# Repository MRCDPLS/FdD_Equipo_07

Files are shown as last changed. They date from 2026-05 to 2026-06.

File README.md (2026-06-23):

# Equipo 07 - Fundamentos de Diseño
### Carrera de Ingeniería Ambiental / Informática / Industrial  
**Universidad Peruana Cayetano Heredia**

---

## 🌍 Descripción del Equipo  
<p align="justify">
Somos el <strong>Equipo 07</strong> del curso <strong>Fundamentos de Diseño 2026</strong>, conformado por estudiantes de la carrera de Ingeniería Ambiental / Informática / Industrial.  
Nuestro objetivo es diseñar e implementar una solución tecnológica basada en metodologías de diseño que permita la detección y clasificación de microplásticos en ecosistemas marino, con el proposito de que las playas tengan el antiguo brillo de antes, y que los animales marinos esten bien. 
</p>

---

## 📌 Descripción del Proyecto
<p align="justify">
El Equipo 07 desarrolla un dispositivo portátil de detección automatizada de microplásticos llamado Yaku-Ñawi, enfocado en la identificación de partículas polímeras como PP (polipropileno) y EPS (poliestireno expandido) en playas y humedales de Lima y Callao.

La solución integra técnicas de procesamiento digital de imágenes, visión computacional e inteligencia artificial, empleando hardware embebido basado en Seeed Studio XIAO ESP32-S3 Sense, una placa con cámara integrada que permite la captura de imágenes en campo y su procesamiento dentro de una arquitectura portátil. Para mejorar la observación de las muestras, el prototipo incorpora iluminación ultravioleta (UV), aprovechando las propiedades ópticas de ciertos polímeros para facilitar su diferenciación visual y fortalecer el análisis computacional. De manera complementaria, el sistema puede integrar sensores de apoyo para caracterizar el entorno de la muestra, contribuyendo a una evaluación más completa del estado del agua.

El objetivo principal de Yaku-Ñawi es lograr la identificación temprana de microplásticos mediante un sistema autónomo capaz de procesar datos sin depender de infraestructura externa ni análisis de laboratorio especializados. Esto permite implementar un monitoreo ambiental continuo, oportuno y adaptado a condiciones reales, reduciendo tiempos, costos operativos y barreras tecnológicas existentes en los métodos tradicionales.

A través de esta propuesta, Yaku-Ñawi busca contribuir al estudio y monitoreo de la contaminación por microplásticos en ecosistemas marino-costeros, alineándose con los Objetivos de Desarrollo Sostenible, especialmente el ODS 6: Agua limpia y saneamiento y el ODS 14: Vida submarina.
</p>

---

## 🔍 Introducción
<p align="justify">
La creciente contaminación por microplásticos se ha convertido en uno de los desafíos ambientales más relevantes a nivel global, como resultado del uso masivo de plásticos y su persistencia en el ambiente. Estas partículas, menores a 5 mm, se encuentran ampliamente distribuidas en ecosistemas acuáticos y terrestres, lo que facilita su dispersión, acumulación y permanencia a largo plazo (1).
</p>

<p align="justify">
En el Perú, la deficiente gestión de residuos sólidos y el inadecuado manejo de desechos costeros han intensificado la presencia de microplásticos en ambientes marinos. Esta problemática no solo impacta a los ecosistemas, sino que también representa un riesgo creciente para la salud humana (2), debido a su ingreso al organismo a través de alimentos contaminados y la inhalación de partículas, generando efectos adversos como inflamación y alteraciones celulares (3).
</p>

<p align="justify">
Frente a este escenario, el presente proyecto propone determinar la presencia de microplásticos en humedales y playas de Lima y Callao mediante una metodología de análisis orientada a la identificación de polímeros sintéticos de uso común, como el polipropileno (PP) y el poliestireno expandido (EPS) (4). De esta manera, se busca generar evidencia científica que permita dimensionar la magnitud de esta contaminación y sentar bases para el desarrollo de estrategias de monitoreo y mitigación en ecosistemas acuáticos (5).
</p>

---

## ⚠️ Problemática 
### Problemática a Nivel Mundial
<p align="justify">
La crisis de los microplásticos está impulsada principalmente por polímeros de alta producción como el polipropileno (PP) y el EPS (poliestireno expandido). El polipropileno representa aproximadamente el 21 % de la producción total de plásticos no fibrosos, siendo ampliamente utilizado en envases, empaques y materiales industriales, lo que incrementa su liberación al ambiente tras su disposición final inadecuada (6). Por su parte, el PET constituye un material fundamental en la industria de bebidas y textiles sintéticos, donde domina la producción de fibras artificiales utilizadas globalmente (6,7).
</p>

#### Impactos y comportamiento:
* Persistencia diferencial:
  <p align="justify">
  El PET tiende a degradarse más lentamente que otros polímeros como el polietileno, lo que prolonga su presencia en el entorno (5,6).
  </p>

* Comportamiento en el agua: 
  <p align="justify">
  El EPS posee una densidad aproximada de 0.94 g/mL, característica que le permite flotar y dispersarse ampliamente en la superficie marina. En contraste, el PET presenta mayor densidad, favoreciendo su sedimentación y acumulación en fondos acuáticos (7,8).
  </p>

* Presencia en humanos: 
  <p align="justify">
  Diversas investigaciones han evidenciado la presencia de microplásticos en muestras biológicas humanas. Partículas de PP han sido detectadas en placenta y heces humanas, mientras que el PET constituye uno de los polímeros más frecuentemente identificados en sangre y muestras fecales, evidenciando su ingreso a la cadena alimentaria y posible impacto en la salud humana (7,8).
  </p>

### Problemática a Nivel Local
<p align="justify">
En Lima y el Callao, el ESP y el PET representan contaminantes prioritarios debido al elevado consumo de productos descartables y a deficiencias en la gestión integral de residuos sólidos. Se estima que cerca del 40 % de los residuos generados en el país no recibe una disposición adecuada, terminando en ríos, playas y ecosistemas marinos donde se fragmentan progresivamente en microplásticos (11).
</p>

#### Hallazgos específicos en Lima:
* Contaminación en playas: 
  <p align="justify">
  Estudios realizados en playas arenosas del litoral peruano han confirmado la presencia de microplásticos mediante análisis espectroscópicos, identificándose partículas de polipropileno asociadas a residuos marinos transportados por corrientes costeras y acumulación de basura oceánica (12).
  </p>

* Riesgo en recursos pesqueros: 
  <p align="justify">
  Investigaciones recientes en especies comerciales capturadas en terminales pesqueros de Lima y Callao reportaron la presencia de microplásticos en el 100 % de algunas especies analizadas, evidenciando la transferencia de estas partículas dentro de la red trófica marina y su potencial riesgo para el consumo humano (6). El uso de PP en artes de pesca y la degradación de botellas de PET constituyen fuentes directas de contaminación en el ecosistema marino local (7,11,13).
  </p>
--- 

## 🌊 Yaku-Ñawi – Detector de microplásticos
### 💡 Presentación de la solución 
<p align="justify">
El presente proyecto propone el desarrollo de un <strong>dispositivo inteligente portátil diseñado para detectar y clasificar microplásticos como el polipropileno (PP) y el polietileno tereftalato (PET)</strong> en cuerpos de agua, como humedales y playas de Lima y Callao, donde la contaminación por residuos plásticos representa una amenaza creciente para los ecosistemas y la salud humana.
</p>

<p align="justify">
La solución integra sensores ópticos, captura y procesamiento de imágenes y análisis automatizado usando modelos de IA, de muestras de agua y sedimentos. Este sistema incorpora algoritmos de machine learning y la inteligencia artificial actúa como núcleo del sistema, optimizando continuamente la detección a medida que procesa nuevas muestras. Todo ello se traduce en una herramienta portable y escalable, permitiendo realizar monitoreo ambiental directamente en campo sin necesidad de laboratorio especializado.
</p>

<p align="justify">
Bajo el enfoque de ingeniería, Yaku-Ñawi integra principalmente <strong>procesamiento de imágenes, machine learning, electrónica con sensores y microcontroladores</strong>. Esto permite transformar un proceso tradicionalmente manual en un sistema automatizado, escalable y replicable.
</p>

<p align="justify">
El valor innovador radica que <strong>automatiza la detección de microplásticos y macroplásticos, reduce costos frente a un análisis de laboratorio y que puede ser adaptada en distintas zonas del país</strong>.
</p>

---

## 🎯 Objetivos de Desarrollo Sostenible (ODS)
<p align="justify">
Nuestro proyecto se relaciona con los siguientes <strong>Objetivos de Desarrollo Sostenible (ODS)</strong>: 
</p>

- 🐠 **ODS 14 : VIDA SUBMARINA**  
  <p align="justify">
  La contaminación por plásticos y microplásticos representa una amenaza importante para los ecosistemas marinos. Estas partículas pueden permanecer durante muchos años en el agua y afectar a la fauna marina. Se estima que entre 19 y 23 millones de toneladas de residuos plásticos ingresaron a los sistemas acuáticos en el 2016, y se prevé que esta cifra podría alcanzar hasta 53 millones de toneladas anuales para 2030. Esta problemática afecta directamente a la vida submarina, ya que los organismos marinos pueden ingerir microplásticos, lo que altera los ecosistemas y la biodiversidad.
  </p>

- 💧 **ODS 6: AGUA LIMPIA Y SANEAMIENTO**  
  <p align="justify">
  Los microplásticos también afectan la calidad del agua potable y los sistemas de tratamiento de aguas residuales. Estas partículas pueden ingresar a las plantas de tratamiento a través del lavado de ropa sintética y productos que contienen plástico. Aunque los sistemas de tratamiento pueden eliminar una parte de estos contaminantes, la gran cantidad de microplásticos sigue representando un desafío para garantizar agua segura y saneamiento adecuado.
  </p>

---

## 📖 Referencias bibliográficas 
1.  Microplastics and human health. Wasser 3.0 [Internet]. 27 de julio de 2024 [citado 13 de abril de 2026].  
Disponible en: https://wasserdreinull.de/en/blog/microplastics-and-human-health/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 
2.  Micro- and mesoplastic pollution along the coast of Peru | Request PDF. ResearchGate. 23 de enero de 2026. 
Disponible en: doi:10.1007/s11356-023-27707-6.
3. Emenike EC, Okorie CJ, Ojeyemi T, Egbemhenghe A, Iwuozor KO, Saliu OD, et al. From oceans to dinner plates: The impact of microplastics on human health. Heliyon. 1 de octubre de 2023;9(10):e20440.  
Disponible en: doi:10.1016/j.heliyon.2023.e20440.
4. Luque Fernández CR. Contaminación por microplásticos en playas arenosas de Islay, departamento de Arequipa [Internet]. 17 de enero de 2020 [citado 1 de abril de 2026].  
Disponible en: https://repositorio.ucsm.edu.pe/handle/20.500.12920/9869. 
5. Gimiliani GT. Caracterização de microplásticos em amostras marinhas e estuarinas [tesis doctoral]. São Paulo: Instituto de Pesquisas Energéticas e Nucleares, Universidade de São Paulo; 2021.   
Disponible en: https://www.teses.usp.br/teses/disponiveis/85/85134/tde-22102021-104234/pt-br.php.
6. Geyer R, Jambeck JR, Law KL. Production, use, and fate of all plastics ever made. Sci Adv. 2017;3(7):e1700782. 
Disponible en: doi:10.1126/sciadv.1700782
7. Osman AI, Hosny M, Eltaweil AS, Omar S, Elgarahy AM, Farghali M, et al. Microplastic sources, formation, toxicity and remediation: a review. Environ Chem Lett. 2023;21:2129-2169.   
Disponible en: doi:10.1007/s10311-023-01593-3.
8. Rios Mendoza LM, Balcer M. Microplastics in freshwater environments: A review of quantification assessment. Trends Analyt Chem. 2019;113:402-408.
9. Hu B, Dai Y, Zhou H, Sun Y, Yu H, Dai Y, et al. Using artificial intelligence to rapidly identify microplastics pollution and predict microplastics environmental behaviors. J Hazard Mater. 2024;474:134865.
10. Tian X, Beén F, Bäuerlein PS. Quantum cascade laser imaging (LDIR) and machine learning for the identification of environmentally exposed microplastics and polymers. Environ Res. 2022;212:113569. 
Disponible en: doi:10.1016/j.envres.2022.113569
11. Ministerio del Ambiente (MINAM). Plásticos. Lima: Red Peruana Ciclo de Vida y Ecología Industrial (PELCAN); 2026. 
Disponible en: https://red.pucp.edu.pe/ciclodevida/
12. Purca S, Henostroza A. Presencia de microplásticos en cuatro playas arenosas de Perú. Rev Peru Biol. 2017;24(1):101-106.  
Disponible en: doi:10.15381/rpb.v24i1.12724
13. Flores K, Seminario M, Canchari F, Alvariño L, Miñaya D, Castañeda L, et al. Contaminación por microplásticos en tres peces marinos del Perú. Rev Inv Vet Perú. 2026;37(1):e32888.  
Disponible en: doi:10.15381/rivep.v37i1.32888

---

## 📸 Fotografía del Equipo  
<p align="center">
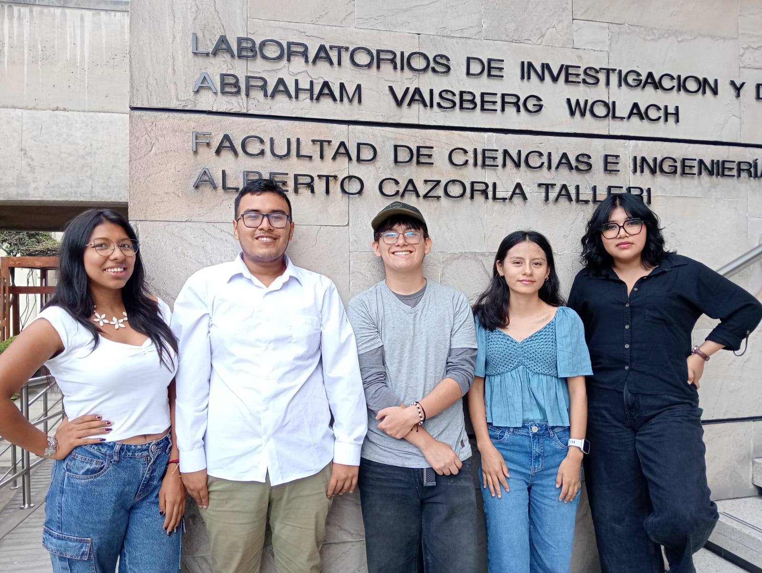
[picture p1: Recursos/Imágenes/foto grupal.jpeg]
imagen_alumnos_IA

  <em>Figura 1. Fotografía del Equipo 07</em>
</p>

---

## 👥 Integrantes del Equipo  

| Foto | 👤 Nombre | 🎓 Rol | 💡 Intereses |
| :---: | :---: | :---: | :---: |
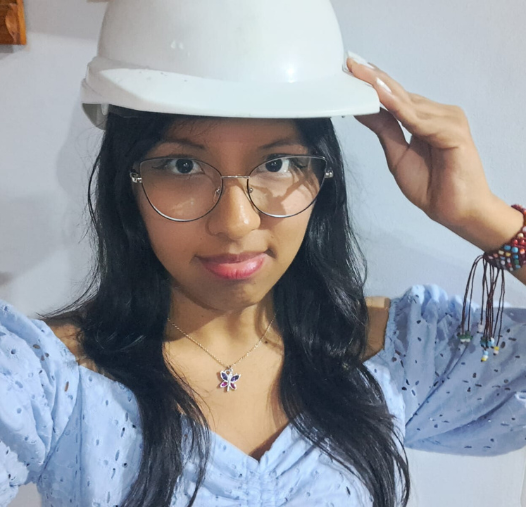
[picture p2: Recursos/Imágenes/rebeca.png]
|  | **Rebeca Cerdan** | ❤️ Líder del equipo | 🎧 Melómana, 🤖 tecnología, 🎮 fan de Genshin Impact |
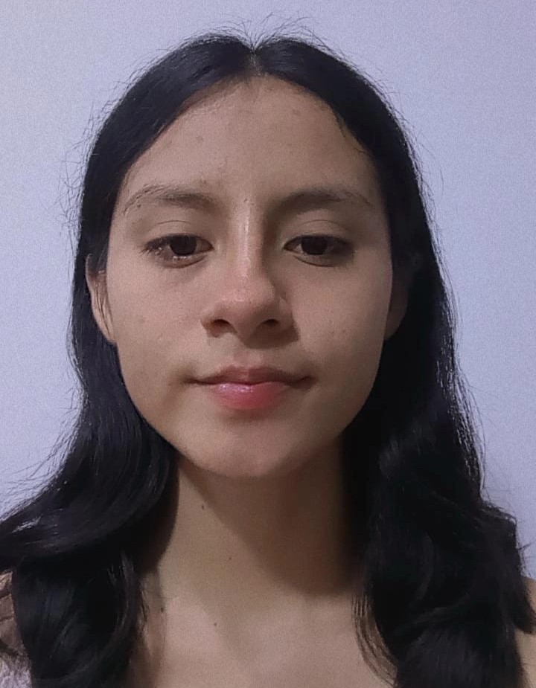
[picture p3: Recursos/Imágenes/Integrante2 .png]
|  | **Siclali Fernandez** | 🚀 Product Manager | 🧠 Entender al usuario, 💡 soluciones innovadoras, 📢 comunicar el valor del proyecto  |
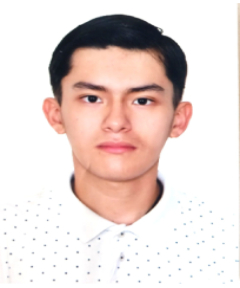
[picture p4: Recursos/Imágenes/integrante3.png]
|  | **Marcelo Alarcon** | 🎨 Diseñador | 🧩 prototipos, ✨ creatividad, 🧱 modelado 3D, 🔍 investigador UX |
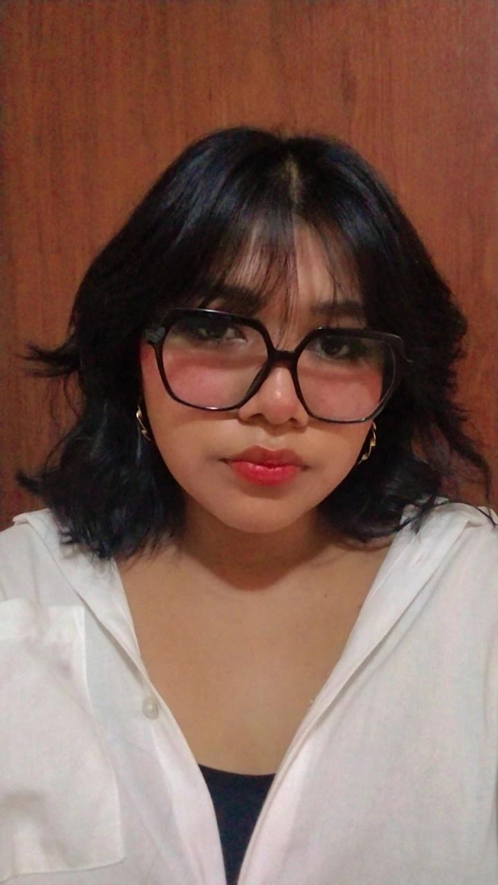
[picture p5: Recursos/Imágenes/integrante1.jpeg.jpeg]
|  | **Mariluz Quispe** | 🌱 Encargada de Apoyo Ambiental | ♻️ sostenibilidad, 🌍 cuidado ambiental |
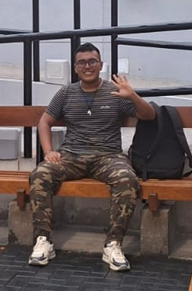
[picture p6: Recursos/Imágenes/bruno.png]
|  | **Bruno Evangelista** | 💻 Programador y Modelador 3D | 📊 Programar una solución ecosostenible |

---

## 📌 Resumen final  
<p align="justify">
El presente README describe la conformación del equipo, la problemática abordada y la propuesta de solución desarrollada en el curso Fundamentos de Diseño. El proyecto consiste en el desarrollo de un sistema inteligente para la detección y análisis de microplásticos en playas y humedales de Lima, mediante la recolección de muestras y su procesamiento con visión artificial e inteligencia artificial. Esta solución permite automatizar un proceso tradicionalmente manual, generando datos confiables para el monitoreo ambiental y contribuyendo a la protección de los ecosistemas acuáticos.
</p>

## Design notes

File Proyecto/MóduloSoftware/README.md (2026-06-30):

# Yaku-Ñawi · Guía de integración YOLOv8 + ESP32-S3

## Estructura del proyecto

```
yaku-nawi/
├── app.py                  ← Servidor Flask + YOLOv8 (ejecutar en la PC)
├── best.pt                 ← Tu modelo YOLOv8 entrenado (colocar aquí)
├── esp32_yaku_nawi.ino     ← Código Arduino para el ESP32-S3 XIAO Sense
├── templates/
│   └── index.html          ← Dashboard web (sirve Flask automáticamente)
├── static/
│   └── ultima.jpg          ← Último frame recibido del ESP32 (auto-generado)
└── README.md
```

---

## 1. Instalar dependencias en la PC

```bash
pip install flask ultralytics opencv-python numpy
```

---

## 2. Colocar el modelo YOLOv8

Copia tu archivo `best.pt` (entrenado con PET y EPS) a la raíz del proyecto.  
Si no tienes `best.pt` aún, Flask usará `yolov8n.pt` como fallback (sin clases de microplásticos).

---

## 3. Correr el servidor

```bash
cd yaku-nawi/
python app.py
```

Verás:
```
  Yaku-Ñawi · Servidor Flask + YOLOv8
  Escuchando en http://0.0.0.0:5000
  Dashboard → http://localhost:5000
  ESP32 POST → http://<TU_IP>:5000/detect
```

Abre el navegador en `http://localhost:5000`.

---

## 4. Configurar el ESP32-S3 XIAO Sense

En el archivo `esp32_yaku_nawi.ino`, edita:

```cpp
const char* SSID     = "TU_RED_WIFI";      // nombre de tu red
const char* PASSWORD = "TU_PASSWORD_WIFI"; // contraseña
const char* FLASK_URL = "http://192.168.1.100:5000/detect";
//                              ↑ IP de la PC donde corre Flask
```

**¿Cómo obtener la IP de la PC?**
- Windows: `ipconfig` → busca "Dirección IPv4"
- Linux/Mac: `ifconfig` o `ip addr`

Asegúrate de que la PC y el ESP32 estén en **la misma red WiFi**.

---

## 5. Subir el sketch al ESP32-S3 XIAO Sense

1. Arduino IDE → Board Manager → instala "esp32 by Espressif Systems"
2. Selecciona la placa: `Tools → Board → XIAO_ESP32S3`
3. Abre `esp32_yaku_nawi.ino`, edita SSID/PASSWORD/FLASK_URL
4. Sube el sketch
5. Abre el Monitor Serie a 115200 baudios para ver los logs

---

## 6. Flujo de datos completo

```
ESP32-S3 XIAO Sense
  │  (OV2640 captura frame JPEG)
  │  (sensor turbidez → NTU)
  │  (sensor TDS → µS/cm)
  │
  │  HTTP POST /detect
  │  Headers: Turbidez: <NTU>, TDS: <µS/cm>
  │  Body: bytes JPEG
  ▼
Flask (app.py) en la PC
  │  Guarda imagen en static/ultima.jpg
  │  Decodifica imagen con OpenCV
  │  Corre inferencia YOLOv8 (best.pt)
  │  Parsea detecciones PET / EPS
  │  Guarda resultado en último_resultado
  ▼
Dashboard (index.html)
  │  Polling GET /datos cada 3 segundos
  │  Muestra imagen, objetos, barras, sparklines
  └  Actualiza historial y tabla
```

---

## 7. Endpoints disponibles

| Endpoint | Método | Descripción |
|---|---|---|
| `/` | GET | Dashboard web |
| `/datos` | GET | JSON con último resultado + historial |
| `/detect` | POST | Recibe imagen + headers del ESP32 |
| `/status` | GET | Estado del servidor y modelo |

---

## 8. Ajustar clases del modelo

En `app.py`, si tus clases tienen nombres diferentes a `pet`/`eps`, edita:

```python
count_pet = sum(1 for o in objetos_detectados if "pet" in o.lower())
count_eps = sum(1 for o in objetos_detectados if "eps" in o.lower())
```

Por ejemplo, si tu modelo usa `microplastico_pet` y `microplastico_eps`, ya funciona porque usa `in o.lower()`.

---

## Notas

- El ESP32-S3 XIAO Sense incluye cámara **OV3660** y módulo WiFi integrado.  
- La resolución **QVGA (320×240)** equilibra velocidad de transferencia y precisión del modelo.  
- Para pruebas sin ESP32, puedes hacer un POST manual con `curl`:

```bash
curl -X POST http://localhost:5000/detect \
  -H "Turbidez: 45.2" \
  -H "TDS: 320" \
  -H "Content-Type: image/jpeg" \
  --data-binary @foto_muestra.jpg
```

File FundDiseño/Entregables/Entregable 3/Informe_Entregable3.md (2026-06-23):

<p align="center">
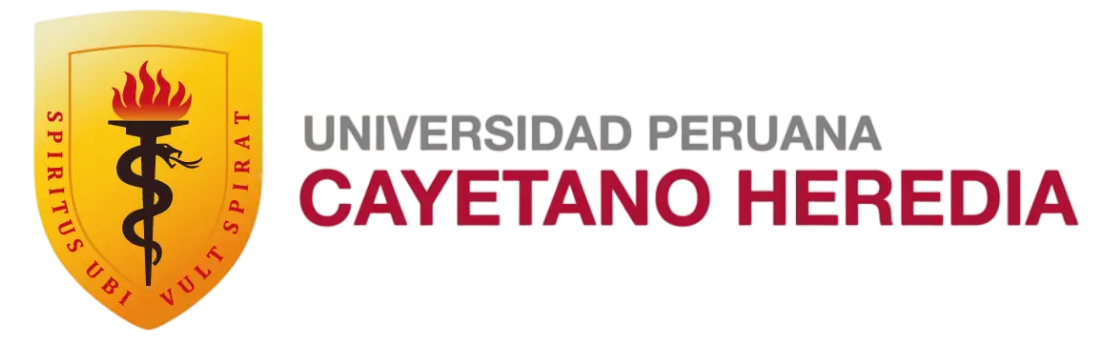
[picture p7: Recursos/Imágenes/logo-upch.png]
  
</p>

#  🔧 INFORME: ENTREGABLE 3

## 1. ESQUEMA ELECTRÓNICO 💾

## 1.1 DESCRIPCIÓN GENERAL

<p align="justify">
En esta sección, presentamos el circuito esquemático de nuestro proyecto utilizando la herramienta EasyEDA para el diseño, simulación y fabricación de circuitos electrónicos y placas de circuito impreso (PCB). Se trata de una representación gráfica de un circuito eléctrico que emplea símbolos estandarizados para ilustrar tanto los componentes como las conexiones entre ellos. Este tipo de diagrama es ampliamente utilizado en electrónica para describir y visualizar la disposición de los elementos de un sistema.
</p>
<p align="justify">
En nuestro caso, el esquemático muestra cómo se integran todos los componentes del proyecto en un único circuito, detallando aspectos como la asignación de pines, la dirección de las señales y las conexiones entre cada elemento. A continuación, presentamos el diagrama para su visualización.
</p>

<p align="center">
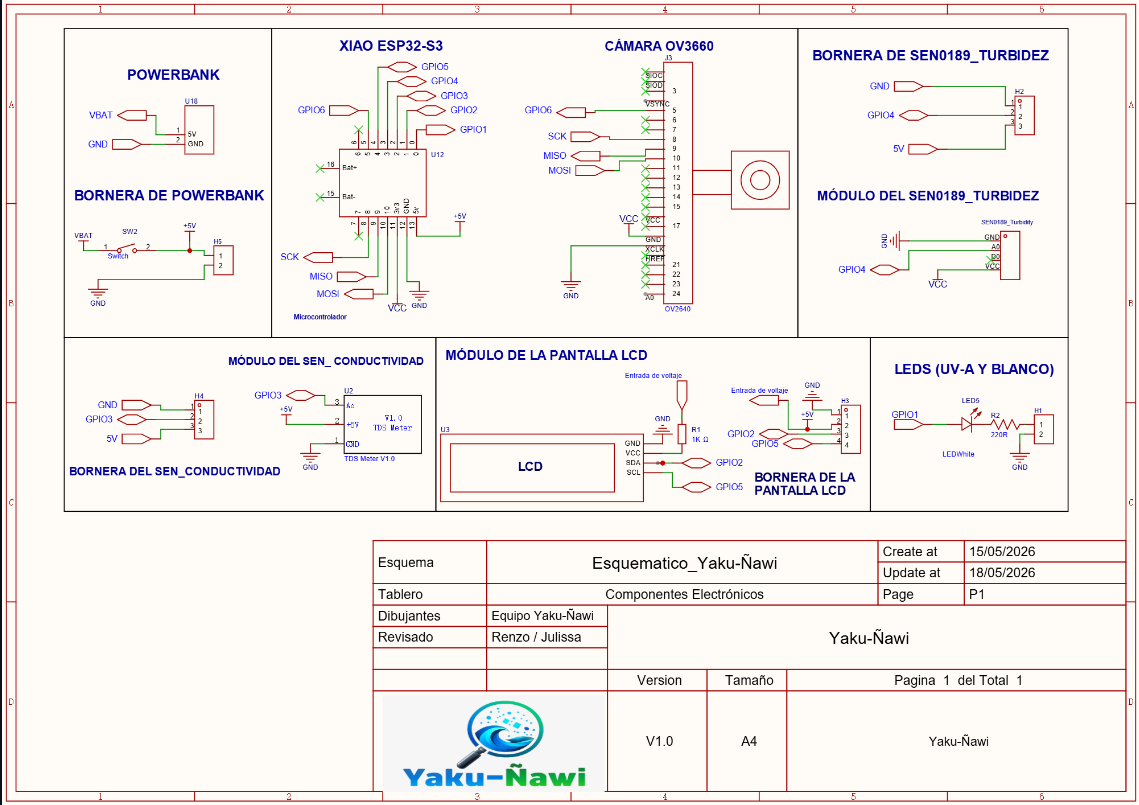
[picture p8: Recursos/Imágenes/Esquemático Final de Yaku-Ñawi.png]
  
</p>

<p align="center">Imagen 1. Circuito electrónico del proyecto general en EasyEDA. </p>

## 1.2 EXPLICACIÓN DE CONEXIONES:

✅ _**Alimentación (PowerBank):**_
<p align="justify">
La PowerBank entrega +5V y GND a través de la bornera H5 (2 pines: pin 1 = +5V, pin 2 = GND). Incluye un switch SW2 para encender/apagar el sistema.
</p>

<table align="center" style="border: none; border-collapse: collapse;">
  <tr style="border: none;">
    <td align="center" style="border: none; padding: 15px; vertical-align: top;">
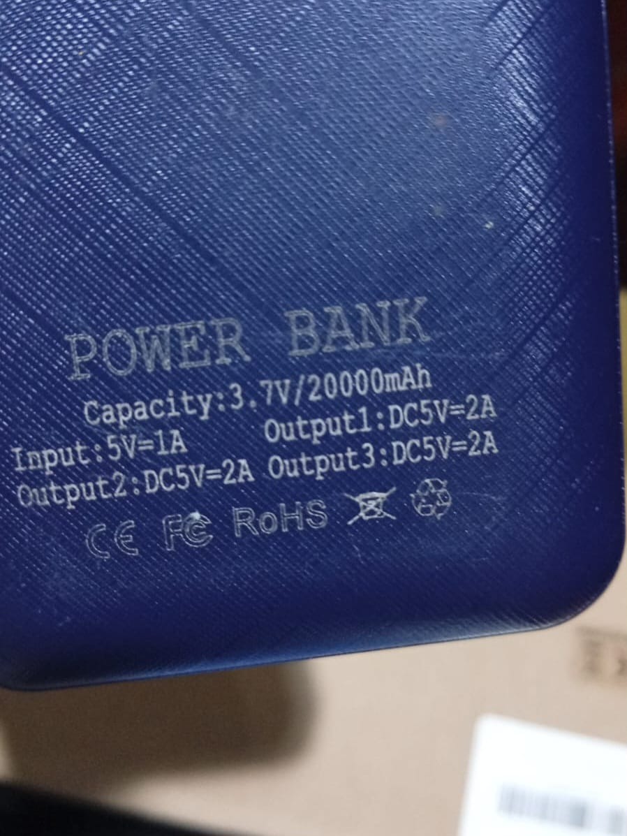
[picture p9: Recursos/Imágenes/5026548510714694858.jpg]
      <br><br>
      <sub>Imagen 2. PowerBank.</sub>
    </td>
</table>

✅ _**XIAO ESP32-S3 (Microcontrolador):**_ 
<p align="justify">
Es el cerebro del circuito. Distribuye sus GPIOs así:</p>

<p align="justify">
• GPIO1 → LEDs.</p>
<p align="justify">
• GPIO2 → SDA de la pantalla LCD.</p>
<p align="justify">
• GPIO3 → Sensor de conductividad (TDS).</p>
<p align="justify">
• GPIO4 → Sensor de turbidez (SEN0189).</p>
<p align="justify">
• GPIO5 → SCL de la pantalla LCD.</p>
<p align="justify">
• GPIO6 → Cámara OV3660.</p>
<p align="justify">
• SCK, MISO, MOSI → Comunicación SPI con la cámara.</p>
</p>

<table align="center" style="border: none; border-collapse: collapse;">
  <tr style="border: none;">
    <td align="center" style="border: none; padding: 10px;">
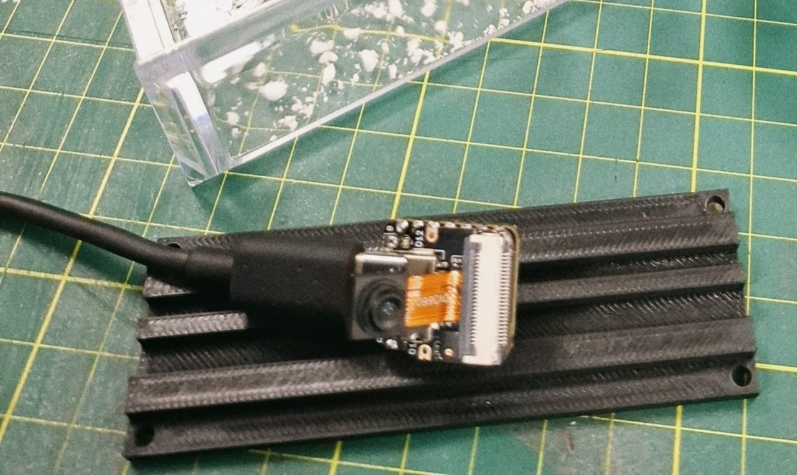
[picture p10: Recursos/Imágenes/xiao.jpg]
      <br><br>
      <sub>Imagen 3. Microcontrolador XIAO ESP32-S3 Sense.</sub>
    </td>
  </tr>
</table>

✅ _**Cámara OV3660:**_ 
<p align="justify">
Se comunica con el ESP32-S3 mediante SPI (SCK, MISO, MOSI) y control por GPIO6. Se alimenta con VCC y GND.
</p>

<table align="center" style="border: none; border-collapse: collapse;">
  <tr style="border: none;">
    <td align="center" style="border: none; padding: 10px;">
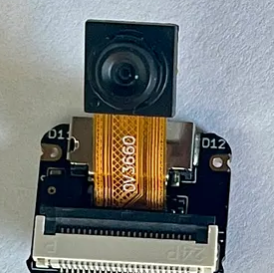
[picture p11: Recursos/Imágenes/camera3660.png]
      <br><br>
      <sub>Imagen 4. Cámara OV3660.</sub>
    </td>
  </tr>
</table>

✅ _**Sensor de Turbidez (TSW-20M):**_ 
<p align="justify">
• Bornera H2 (3 pines): pin 1 = GND, pin 2 = señal, pin 3 = 5V.</p>
<p align="justify">
• Se conecta al módulo SEN0189, el cual envía la señal analógica al GPIO4 del ESP32.
</p>

<table align="center" style="border: none; border-collapse: collapse;">
  <tr style="border: none;">
    <td align="center" style="border: none; padding: 10px;">
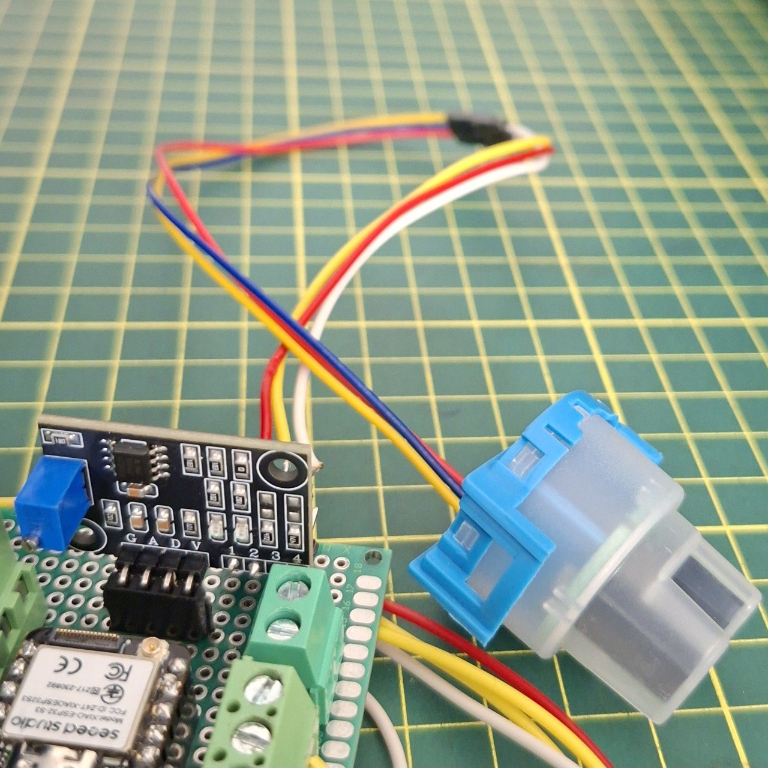
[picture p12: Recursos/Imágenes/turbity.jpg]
      <br><br>
      <sub>Imagen 5. Sensor de Turbidez de agua (TSW-20M).</sub>
    </td>
  </tr>
</table>

✅ _**Sensor de Conductividad (TDS Meter V1.0):**_ 
<p align="justify">
• Bornera H4 (3 pines): pin 1 = GND, pin 2 = GPIO3, pin 3 = 5V.</p>
<p align="justify">
• El módulo TDS procesa la señal y la envía al GPIO3 del ESP32-S3.
</p>

<table align="center" style="border: none; border-collapse: collapse;">
  <tr style="border: none;">
    <td align="center" style="border: none; padding: 10px;">
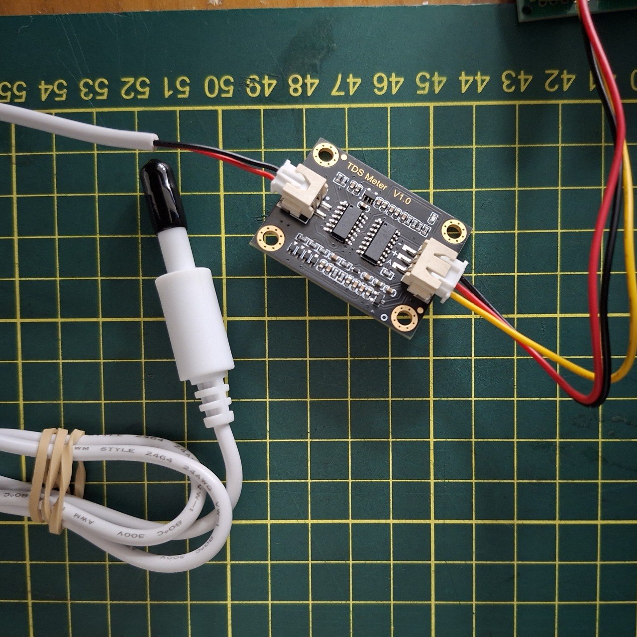
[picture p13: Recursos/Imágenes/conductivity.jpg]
      <br><br>
      <sub>Imagen 6. Sensor de Conductividad (TDS Meter V1.0).</sub>
    </td>
  </tr>
</table>

✅ _**Pantalla LCD:**_ 
<p align="justify">
• Se comunica por I2C: SDA → GPIO2, SCL → GPIO5.</p>
<p align="justify">
• Bornera H3 (4 pines): pin 1 = +5V, pin 2 = GND, pin 3 = GPIO2, pin 4 = GPIO5.</p>
<p align="justify">
• Incluye una resistencia R1 de 1KΩ en la línea de datos.
</p>

<table align="center" style="border: none; border-collapse: collapse;">
  <tr style="border: none;">
    <td align="center" style="border: none; padding: 10px;">
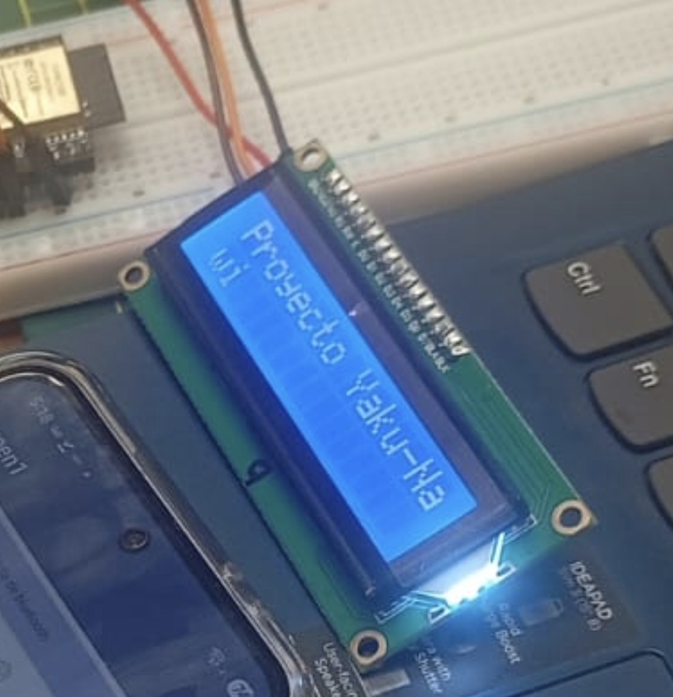
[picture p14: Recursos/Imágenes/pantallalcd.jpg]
      <br><br>
      <sub>Imagen 7. Pantalla LCD I2C (16×2).</sub>
    </td>
  </tr>
</table>

✅ _**LEDs (UV-A y Blanco)**_ 
<p align="justify">
• Controlados desde GPIO1 del ESP32.</p>
<p align="justify">
• Tienen una resistencia limitadora R2 de 270Ω para proteger los LEDs.
</p>

<table align="center" style="border: none; border-collapse: collapse;">
  <tr style="border: none;">
    <td align="center" style="border: none; padding: 10px;">
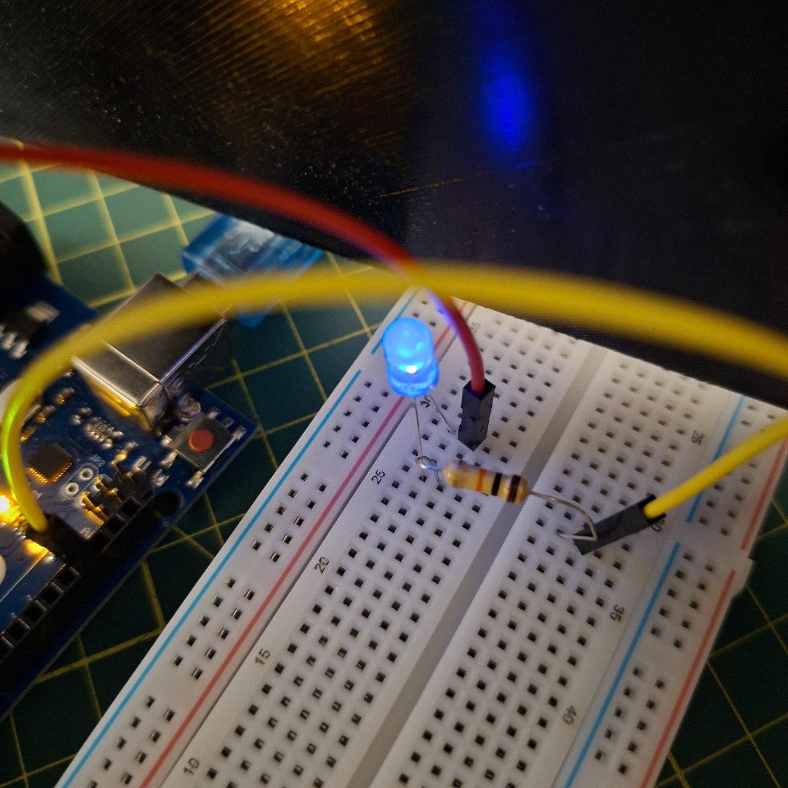
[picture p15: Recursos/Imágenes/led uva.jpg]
      <br>
      <sub>Imagen 8. LED UV-A.</sub>
    </td>
    <td align="center" style="border: none; padding: 10px;">
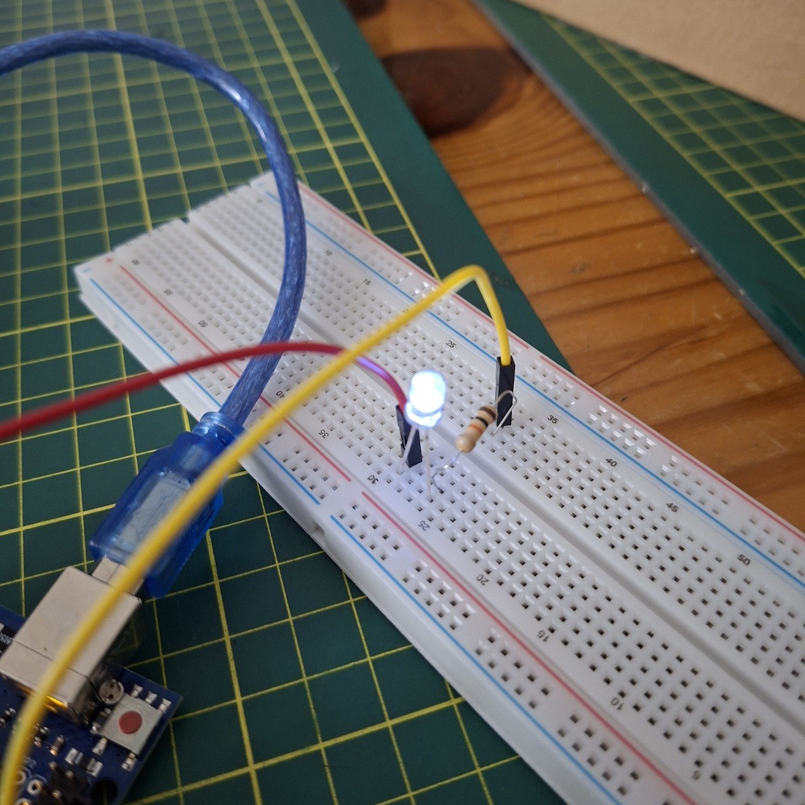
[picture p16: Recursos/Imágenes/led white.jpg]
      <br>
      <sub>Imagen 9. LED Blanco.</sub>
    </td>
  </tr>
</table>

## 2. DISEÑO MECÁNICO DEL PROTOTIPO

### 2.1 Descripción General

El módulo mecánico corresponde a la estructura física que integra y protege todos los componentes electrónicos del sistema Yaku-Ñawi. Su función principal es proporcionar soporte, estabilidad y protección a los sensores, microcontrolador, cámara, sistema de iluminación y fuente de alimentación, garantizando un correcto funcionamiento durante el análisis de muestras de agua.

El diseño fue desarrollado mediante la pagina de modelamiento 3D online "Onshape", considerando criterios de resistencia mecánica, facilidad de ensamblaje, portabilidad y acceso a los componentes para mantenimiento o futuras modificaciones.

### 2.2 Componentes Mecánicos Principales

#### ✅ Carcasa Principal

La carcasa constituye la estructura externa del dispositivo. Su diseño permite alojar de forma segura todos los módulos electrónicos, evitando daños por golpes, vibraciones o manipulación durante las pruebas experimentales.

<table align="center" style="border: none; border-collapse: collapse;">
  <tr style="border: none;">
    <td align="center" style="border: none; padding: 15px; vertical-align: top;">
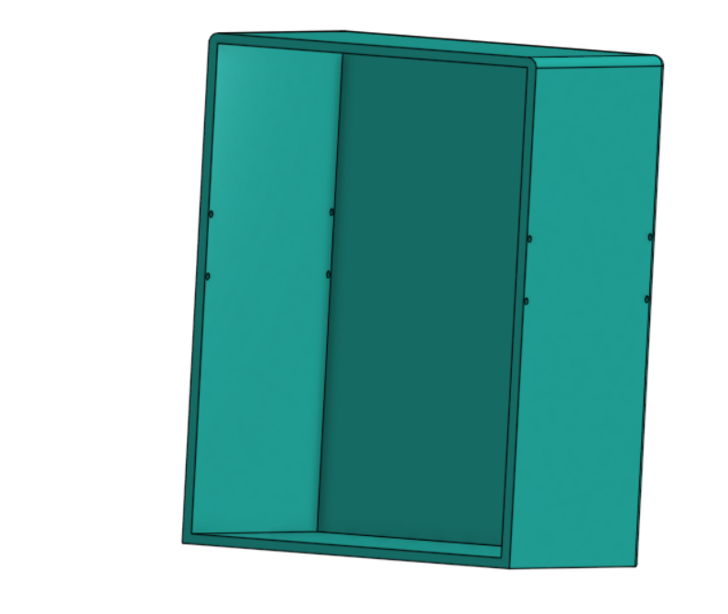
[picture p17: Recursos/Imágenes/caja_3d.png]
      <br><br>
      <sub>Imagen 10. Carcasa Principal </sub>
    </td>
  </tr>
</table>

Funciones:

* Protección de los componentes internos.
* Soporte estructural del sistema.
* Facilitar el transporte del prototipo.
* Mantener el ordenado cableado interno.

#### ✅ Soporte para lente

El lente fue instalada en un soporte que garantiza una orientación fija hacia la muestra analizada.

<table align="center" style="border: none; border-collapse: collapse;">
  <tr style="border: none;">
    <td align="center" style="border: none; padding: 15px; vertical-align: top;">
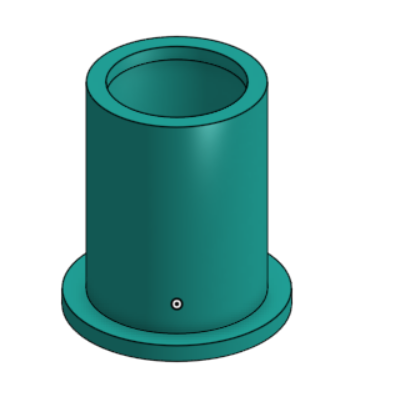
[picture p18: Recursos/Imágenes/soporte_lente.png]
      <br><br>
      <sub>Imagen 11. Soporte para el lente </sub>
    </td>
  </tr>
</table>

Funciones:

* Mantener la distancia focal fija.
* Reducir errores por movimientos o vibraciones.
* Garantizar uniformidad en la captura de imágenes.

#### ✅ Placa para electronica

Se incorporó una placa para toda la electrónica(salvo la cámara, ya que es un sensor), además de  alojamientos para los LEDs UV-A y LEDs de luz blanca, como para la salida de cables para los sensores de turbidez y conductividad, ubicándolos estratégicamente para iluminar homogéneamente la muestra.

<table align="center" style="border: none; border-collapse: collapse;">
  <tr style="border: none;">
    <td align="center" style="border: none; padding: 15px; vertical-align: top;">
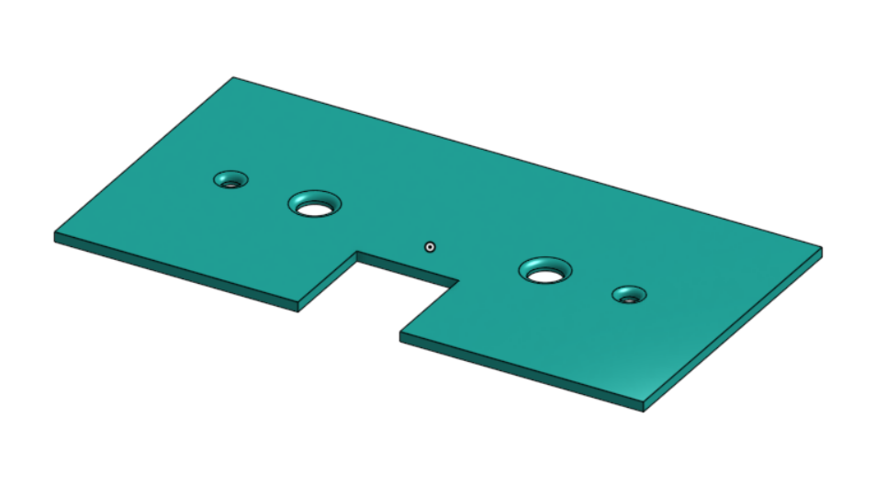
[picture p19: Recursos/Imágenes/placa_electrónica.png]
      <br><br>
      <sub>Imagen 12. Placa para electrónica </sub>
    </td>
  </tr>
</table>

Funciones:

* Separar la electrónica de la muestra para evitar la exposición al agua.
* Aumentar altura para mayor visibilidad de los microplásticos.
* Minimizar sombras e interferencias lumínicas.

#### ✅ Placa para cámara

Se incorporó una placa exclusiva para la camara por dos motivos, separar la electronica de la camara, que la placa obstruya posible luz que pueda haber por parte de los orificios de la carcasa sin obstruir la salidas de los LEDs ni de los cables para los sensores.

<table align="center" style="border: none; border-collapse: collapse;">
  <tr style="border: none;">
    <td align="center" style="border: none; padding: 15px; vertical-align: top;">
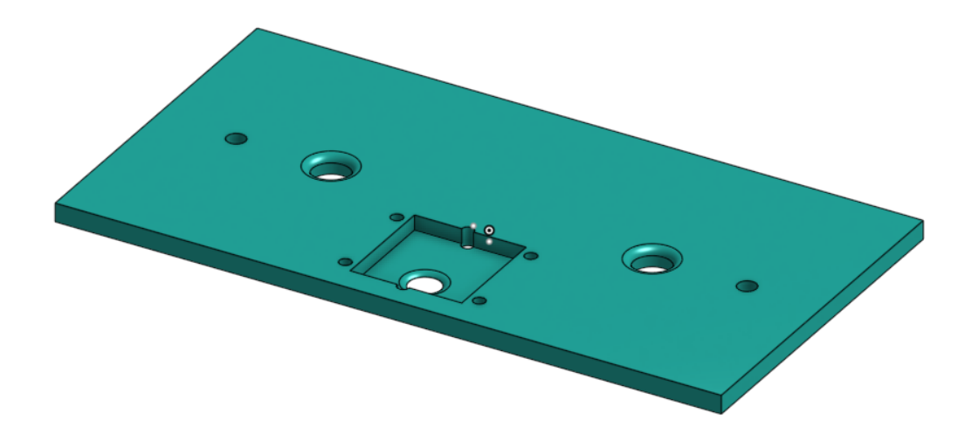
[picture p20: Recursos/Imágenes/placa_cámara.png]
      <br><br>
      <sub>Imagen 13. Placa para Cámara </sub>
    </td>
  </tr>
</table>
Funciones:

* Mencionadas en la descripcion anterior

#### ✅ Soporte para Powerbank

Se implementó un espacio destinado a la PowerBank , permitiendo una alimentación portátil y segura del equipo.

<table align="center" style="border: none; border-collapse: collapse;">
  <tr style="border: none;">
    <td align="center" style="border: none; padding: 15px; vertical-align: top;">
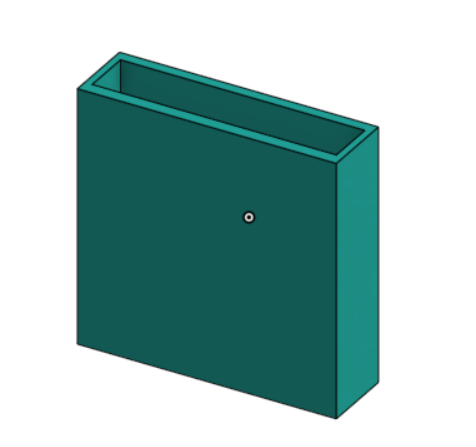
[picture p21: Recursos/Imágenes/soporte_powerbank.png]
      <br><br>
      <sub>Imagen 14. Soporte para Powerbank </sub>
    </td>
  </tr>
</table>

Funciones:

* Facilitar la conexión eléctrica.
* Permitir el reemplazo de la fuente de energía.
* Mantener organizados los elementos de alimentación.

#### ✅ Puerta Inferior

Destinado a aislar la muestra de la luz, funciona a presión.

<table align="center" style="border: none; border-collapse: collapse;">
  <tr style="border: none;">
    <td align="center" style="border: none; padding: 15px; vertical-align: top;">
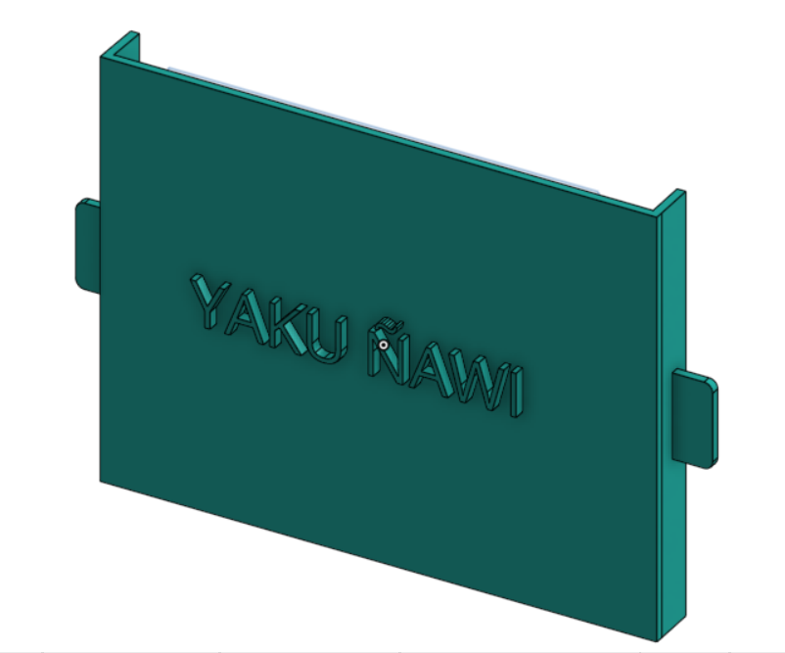
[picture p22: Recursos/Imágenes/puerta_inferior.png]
      <br><br>
      <sub>Imagen 15. Puerta Inferior </sub>
    </td>
  </tr>
</table>

Funciones:

* Mencionadas en la descripcion anterior.

#### ✅ Puerta Superior

Misma Funcion de la puerta inferior, con la diferencia de tener una pantalla LCD destinada a mostrar resultados

<table align="center" style="border: none; border-collapse: collapse;">
  <tr style="border: none;">
    <td align="center" style="border: none; padding: 15px; vertical-align: top;">
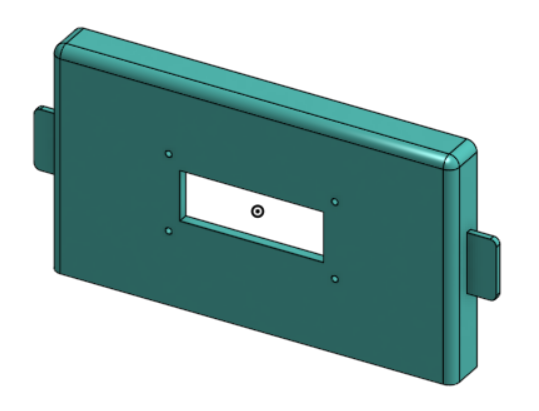
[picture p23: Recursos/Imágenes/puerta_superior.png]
      <br><br>
      <sub>Imagen 16. Puerta Superior </sub>
    </td>
  </tr>
</table>

Funciones:

* Mencionadas en la descripcion anterior.

#### ✅ Cubierta para cámara

Con la funcion de evitar daños, tanto a la cámara como del procesador.

<table align="center" style="border: none; border-collapse: collapse;">
  <tr style="border: none;">
    <td align="center" style="border: none; padding: 15px; vertical-align: top;">
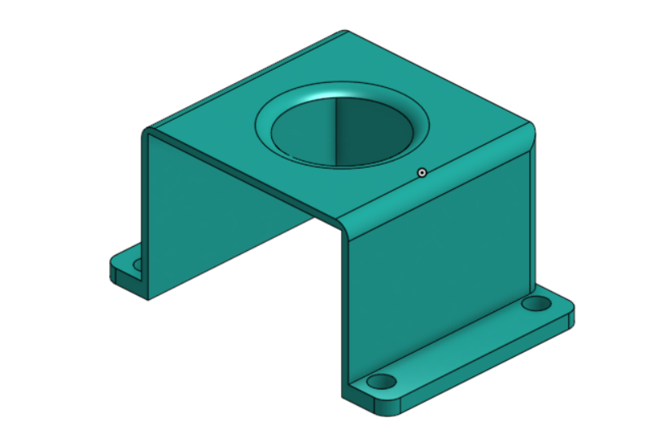
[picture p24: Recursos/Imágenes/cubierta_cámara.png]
      <br><br>
      <sub>Imagen 17. Cubierta para cámara </sub>
    </td>
  </tr>
</table>

Funciones:

* Mencionadas en la descripcion anterior.

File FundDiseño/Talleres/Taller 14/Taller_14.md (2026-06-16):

# Taller nro 14

## Actividad 1

---

### Imagen del bloque de MIT App Inventor
A continuación se presenta el bloque del MIT App Inventor

[https://drive.google.com/file/d/1D5xYZtxJiR00PYCBLBq80FJNMhT6WZPw/view?usp=drive_link](https://drive.google.com/file/d/1D5xYZtxJiR00PYCBLBq80FJNMhT6WZPw/view?usp=drive_link)

---
### Imagen del Designer de MIT App Inventor
A continuación se presenta el Designer del MIT App Inventor

[https://drive.google.com/file/d/1QXypt_W8udMlN-QIv3HKQZ5a85_nzcKo/view?usp=drive_link](https://drive.google.com/file/d/1QXypt_W8udMlN-QIv3HKQZ5a85_nzcKo/view?usp=drive_link)

---

### Bloque de Código en ARDUINO IDE
Aquí se muestra el codigo usado en ARDUINO IDE para el correcto funcionamiento:

```cpp
#include <Wire.h>
#include <LiquidCrystal_I2C.h>
#include "BluetoothSerial.h"
BluetoothSerial SerialBT;
LiquidCrystal_I2C lcd(0x27, 16, 2);
void setup() {
  lcd.init();
  lcd.backlight();

  SerialBT.begin("ESP32_LCD");

  lcd.setCursor(0, 0);
  lcd.print("Esperando...");
}
void loop() {
  if (SerialBT.available()) {

    String mensaje = SerialBT.readStringUntil('\n');
    mensaje.trim();

    lcd.clear();

    if (mensaje.length() <= 16) {
      // Cabe en una sola fila
      lcd.setCursor(0, 0);
      lcd.print(mensaje);
    } else {
      // Se divide en dos filas
      lcd.setCursor(0, 0);
      lcd.print(mensaje.substring(0, 16));
      lcd.setCursor(0, 1);
      lcd.print(mensaje.substring(16, 32));
    }
  }
}
```

---

### Enlace a Recurso de Video
El enlace a continuacion muestra como funciona:

Enlace al video: [https://drive.google.com/file/d/1oEB_WucguHfDKxK_4054fNlgEVF8Y4Jw/view?usp=drive_link](https://drive.google.com/file/d/1oEB_WucguHfDKxK_4054fNlgEVF8Y4Jw/view?usp=drive_link)

### Como funciona
Esta práctica se enfoca en el control dinámico de actuadores utilizando tecnologías de red inalámbricas como Bluetooth o WiFi. El propósito fundamental es diseñar una interfaz gráfica en MIT App Inventor que disponga de una barra deslizante (denominada slider). Al mover este control en la pantalla del smartphone, se envían datos numéricos en tiempo real hacia el ESP32, el cual decodifica la señal para modificar con precisión el ángulo de giro de un servomotor acoplado al sistema.

En el apartado de hardware, la complejidad del cableado se reduce en comparación con la primera actividad, ya que se emplean menos componentes externos. Los materiales necesarios se limitan al módulo ESP32 DevKit V1 como cerebro del proyecto, un servomotor específico modelo 35G-CM con capacidad de rotación de hasta 270°, el cable micro-USB para la transferencia del código junto a la alimentación eléctrica, y el dispositivo Android que actúa como el panel de control interactivo.
## Actividad 2

---

### Imagen del bloque de MIT App Inventor
A continuación se presenta el bloque del MIT App Inventor

[https://drive.google.com/file/d/1k5u4m1aDOfD-LFQjilzLEEmkRXQ-nm-8/view?usp=drive_link](https://drive.google.com/file/d/1k5u4m1aDOfD-LFQjilzLEEmkRXQ-nm-8/view?usp=drive_link)

---
### Imagen del Designer de MIT App Inventor
A continuación se presenta el Designer del MIT App Inventor

[https://drive.google.com/file/d/1g2GzaLHDTw6mZWex8EHxU-rcTl4cUilY/view?usp=drive_link](https://drive.google.com/file/d/1g2GzaLHDTw6mZWex8EHxU-rcTl4cUilY/view?usp=drive_link)

---

### Bloque de Código en ARDUINO IDE
Aquí se muestra el codigo usado en ARDUINO IDE para el correcto funcionamiento:

```cpp
#include <WiFi.h>
#include <WebServer.h>

// Configuración del pin y PWM nativo para el servo
const int pinServo = 1; // Pin D0 en la XIAO ESP32-S3
const int frecuencia = 50;
const int resolucion = 12;

// Nombre y contraseña de la red Wi-Fi que creará la XIAO
const char* ssid = "XIAO_Servo_Net";
const char* password = "123456789_XIAO";

// Creamos el servidor web en el puerto 80
WebServer server(80);

void moverServo(int angulo) {
  int duty = map(angulo, 0, 270, 102, 491);
  ledcWrite(pinServo, duty);
}

// Función que se ejecuta cuando el celular manda el ángulo
void manejarRutaServo() {
  if (server.hasArg("angulo")) {
    String valor = server.arg("angulo");
    int angulo = valor.toInt();
    
    if (angulo >= 0 && angulo <= 270) {
      moverServo(angulo);
      Serial.print("Ángulo recibido por Wi-Fi: ");
      Serial.println(angulo);
    }
    server.send(200, "text/plain", "OK");
  } else {
    server.send(400, "text/plain", "Falta el parámetro 'angulo'");
  }
}

void setup() {
  Serial.begin(115200);
  
  // Configurar PWM del servo
  ledcAttach(pinServo, frecuencia, resolucion);
  moverServo(0); // Iniciar en 0 grados

  // Configurar la XIAO en modo Access Point
  Serial.println("Configurando Access Point...");
  WiFi.softAP(ssid, password);
  
  IPAddress IP = WiFi.softAPIP();
  Serial.print("Red Wi-Fi lista. IP del servidor: ");
  Serial.println(IP); // Por defecto será 192.168.4.1

  // Definir la ruta web para el control del servo
  server.on("/setServo", manejarRutaServo);
  
  // Iniciar el servidor
  server.begin();
  Serial.println("Servidor HTTP iniciado.");
}

void loop() {
  server.handleClient(); // Mantener el servidor atento a peticiones
}
```

---

### Enlace a Recurso de Video
El enlace a continuacion muestra como funciona:

Enlace al video: [https://drive.google.com/file/d/1lbO74vRa-t-MmN_bKW8oT_3HK0gYHMYx/view?usp=sharing](https://drive.google.com/file/d/1lbO74vRa-t-MmN_bKW8oT_3HK0gYHMYx/view?usp=sharing)

### Como funciona
El objetivo principal de este proyecto es diseñar e implementar un sistema de comunicación inalámbrica de corto alcance. Consiste en desarrollar una aplicación móvil personalizada mediante la plataforma MIT App Inventor que se conecte vía Bluetooth a un módulo ESP32 DevKit V1. La meta final es redactar un mensaje de texto desde un smartphone Android y transmitirlo de forma inalámbrica para que el microcontrolador lo procese y lo muestre en una pantalla LCD de 2x16 caracteres.

Para llevar a cabo este montaje electrónico, se requiere un conjunto específico de componentes que aseguren el correcto funcionamiento del hardware. Además del módulo ESP32 y el teléfono inteligente, la lista de materiales incluye una pantalla LCD 2x16, una resistencia de 220 Ω para proteger la retroiluminación y un potenciómetro de 10 kΩ para regular el contraste de las letras en el panel. Todo el sistema se energiza y se programa utilizando un cable de datos micro-USB conectado al módulo principal.

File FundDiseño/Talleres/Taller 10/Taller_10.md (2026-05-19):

## 
| Certificados de Advanced OneShape Assemblies |
|-------------|
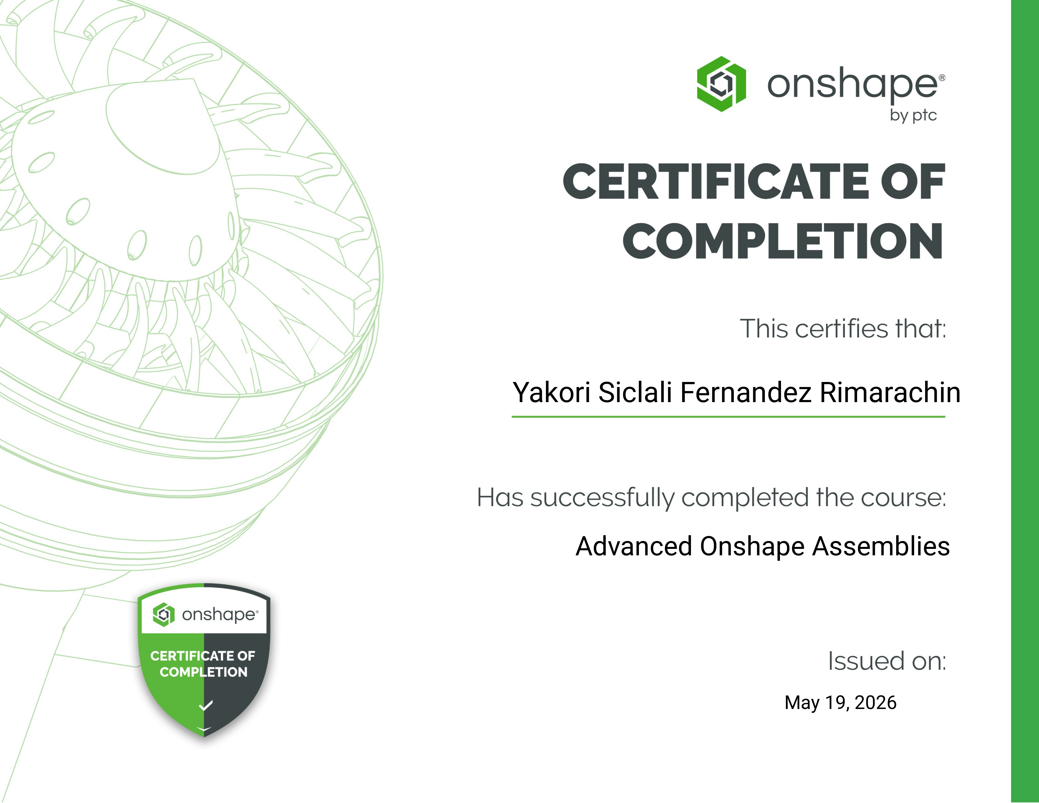
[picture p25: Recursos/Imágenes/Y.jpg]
||
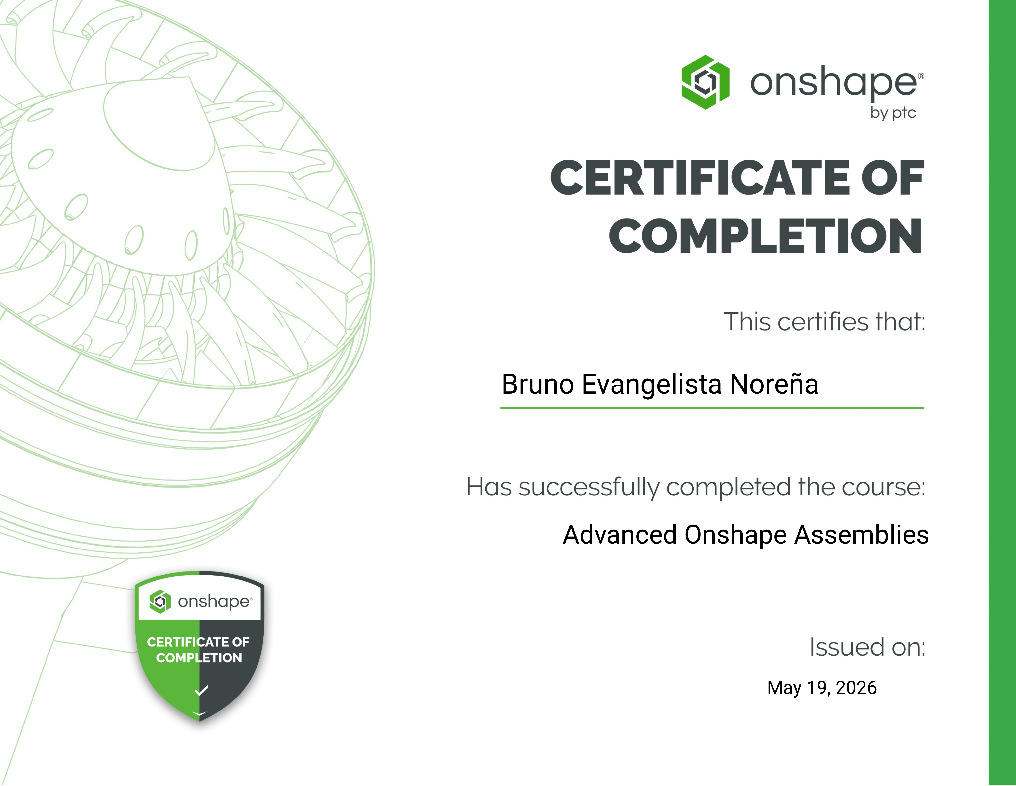
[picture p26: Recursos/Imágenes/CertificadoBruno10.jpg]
||
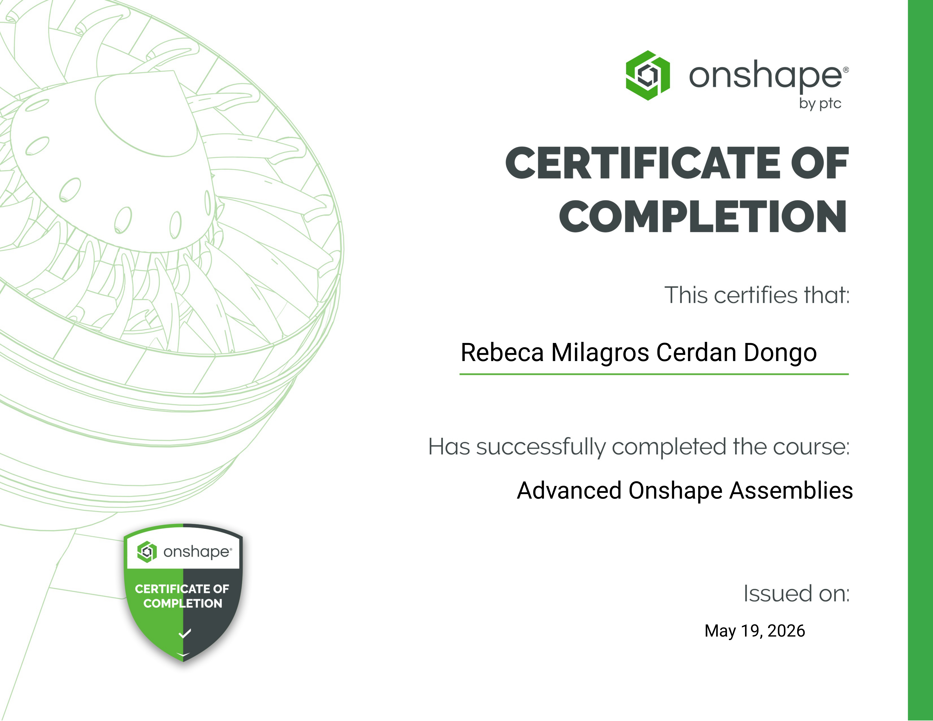
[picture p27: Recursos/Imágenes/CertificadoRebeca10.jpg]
||
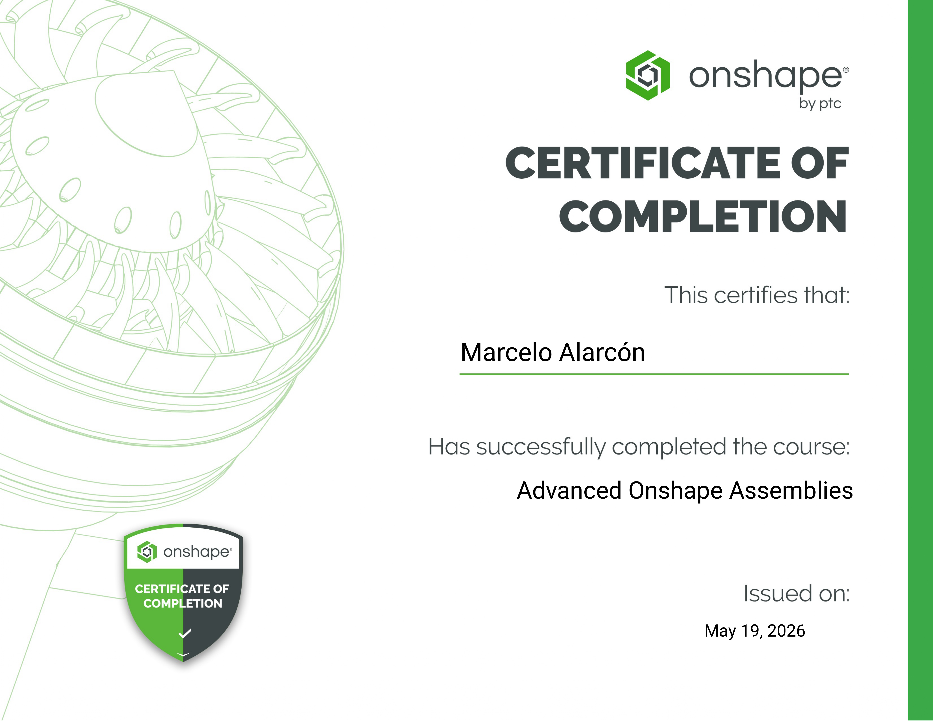
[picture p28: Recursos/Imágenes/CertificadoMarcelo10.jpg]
||
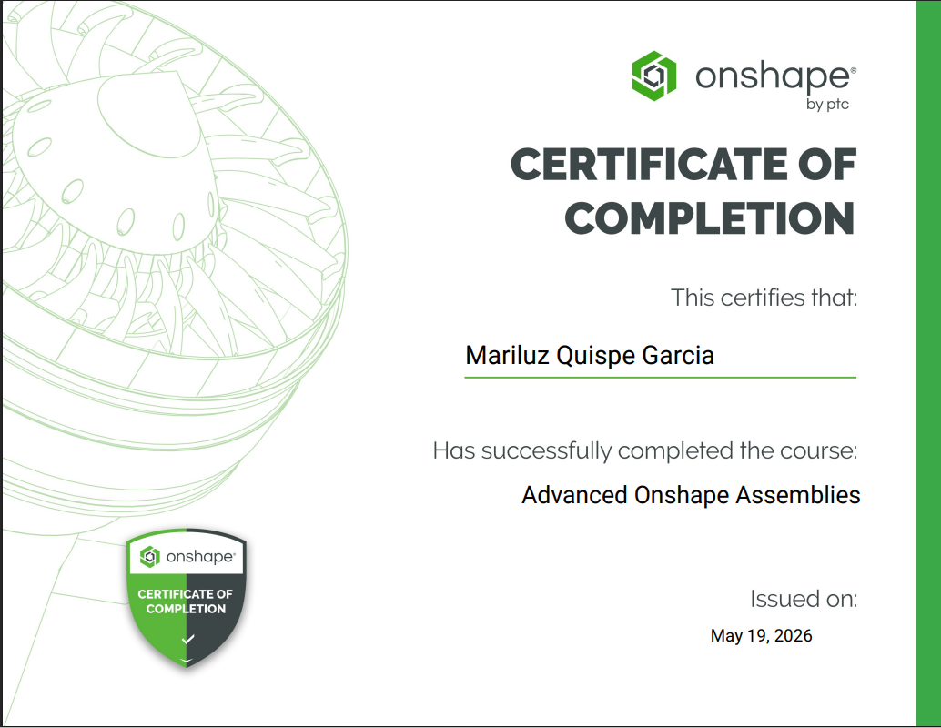
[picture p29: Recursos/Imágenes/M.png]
||

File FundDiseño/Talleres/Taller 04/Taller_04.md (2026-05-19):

<table border="1">
  <tr>
    <td><b>TÍTULO </b></td>
    <td colspan="2">ACOPLAMIENTO DE SENSORES DETECTORES DE MICROPLÁSTICOS Y ENTRENAMIENTO DE DATOS</td>
  </tr>
  <tr>
    <td> CIP: G06V20/69 </td>
    <td colspan="2">Investigating or analysing materials by the use of optical means, i.e. using sub-millimetre waves, infrared, visible or ultraviolet light (G01N3/00 - G01N19/00 take precedence)</td>
  </tr>
  <tr>
    <td> NÚMERO DE PUBLICACIÓN </td>
    <td> US2024071072A1 </td>
    <td> IMAGEN </td>
  </tr>
  <tr>
    <td> Resumen </td>
    <td> Métodos, sistemas y aparatos, incluidos programas informáticos codificados en medios de almacenamiento informático, para recibir datos de sensores y perfeccionar un modelo de entrenamiento para detectores de microplásticos. En algunas implementaciones, un método ejemplar incluye recibir datos de detección de microplásticos de un sensor de detección de microplásticos y datos adicionales de uno o más sensores adicionales; proporcionar los datos de detección de microplásticos y datos adicionales de sensores a un modelo entrenado para detectar microplásticos; recibir uno o más valores que representan la cantidad de microplásticos a partir de los datos de detección de microplásticos y datos adicionales de sensores; y proporcionar una representación de uno o más valores de salida del modelo que describa la cantidad de microplásticos para uso por uno o más dispositivos usuarios.</td>
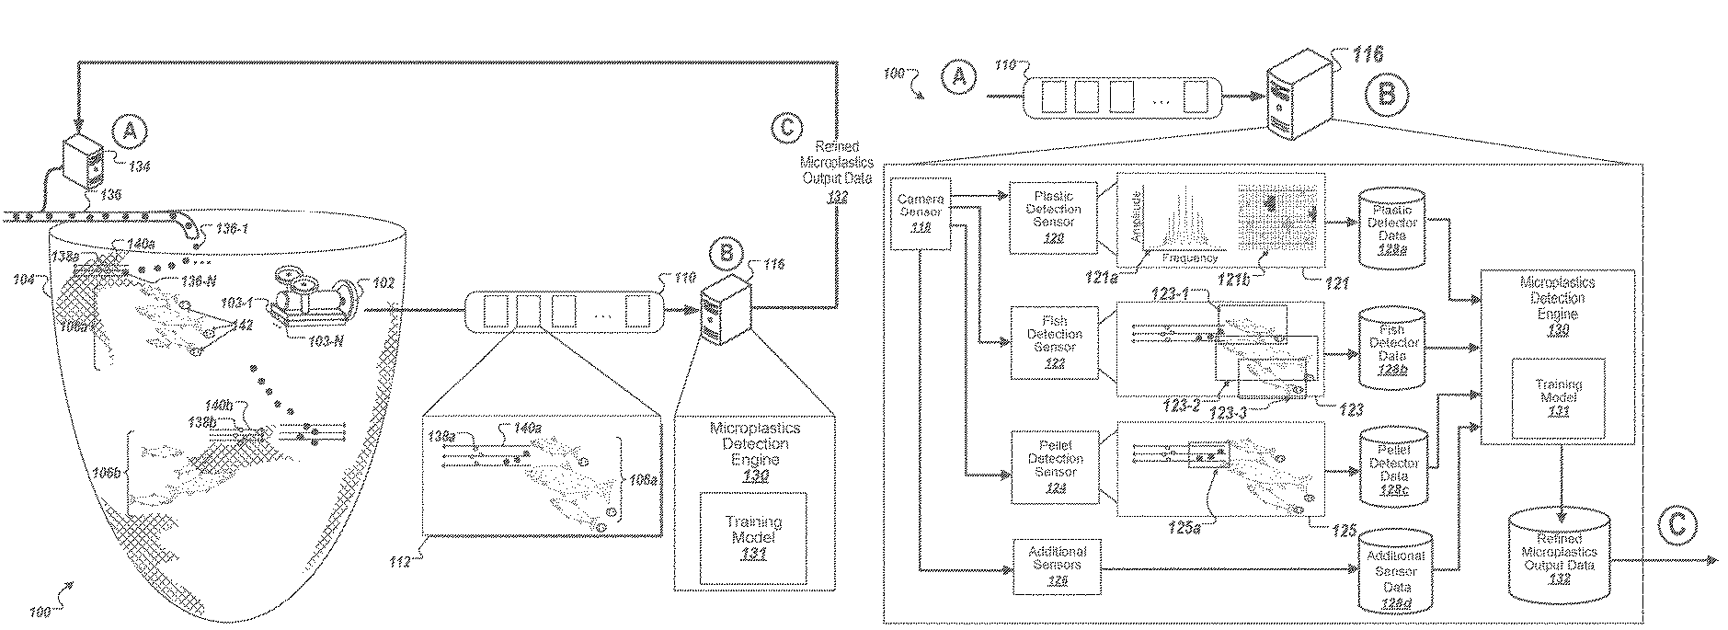
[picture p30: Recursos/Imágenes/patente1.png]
    <td "width:40%; vertical-align:top;">   </td>
  </tr>
  <tr>
    <td > LINK </td>
    <td colspan="3"> https://worldwide.espacenet.com/patent/search/family/089997042/publication/US2024071072A1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 </td>
  </tr>
</table>

<table border="1">
  <tr>
    <td><b>TÍTULO </b></td>
    <td colspan="2">  DOUBLE-BEAM RAMAN ENHANCED MICRO-PLASTIC TRACE DETECTION METHOD BASED ON BUBBLE DEPOSITION PRINCIPLE AND APPLICATION OF DOUBLE-BEAM RAMAN ENHANCED MICRO-PLASTIC TRACE DETECTION METHOD  </td>
  </tr>
  <tr>
    <td>  CIP: G01N21/68   </td>
    <td colspan="2">  Investigating or analysing materials by the use of optical means, i.e. using sub-millimetre waves, infrared, visible or ultraviolet light (G01N3/00 - G01N19/00 take precedence)   </td>
  </tr>
  <tr>
    <td> NÚMERO DE PUBLICACIÓN </td>
    <td> CN120334208A  </td>
    <td> IMAGEN </td>
  </tr>
  <tr>
    <td style="width:15%"> Resumen </td>
    <td style="width:40%">  La invención se refiere al campo de la nanociencia y la nanotecnología, en particular a un método de detección de trazas mejorado por Raman de doble haz basado en un principio de deposición de burbujas en la superficie de contracción y a la aplicación de dicho método. Se realiza un calentamiento láser, se generan burbujas de luz en la superficie de la solución, se detiene el calentamiento láser cuando las burbujas alcanzan un cierto diámetro y, durante el proceso de deposición de burbujas, se depositan conjuntamente nanopartículas de metales preciosos y partículas del objeto a medir en la superficie del sustrato; se mide una señal Raman intrínseca utilizando una trayectoria de luz confocal de doble haz como fuente de luz de detección Raman; y se compara la señal Raman intrínseca medida con un espectro Raman estándar, realizando un análisis cualitativo del objeto a medir. Según la invención, la detección Raman se lleva a cabo utilizando simultáneamente dos fuentes láser con diferentes longitudes de onda como trayectorias de luz confocales, de modo que la resolución y la sensibilidad del espectro Raman mejoran notablemente, se puede reducir eficazmente la interferencia de la fluorescencia y se logra una detección de alta precisión de las partículas a detectar.   </td>
    <td style="width:45%" >   </td>
  </tr>
  <tr>
    <td > LINK </td>
    <td colspan="3">  https://worldwide.espacenet.com/patent/search?q=pn%3DCN120334208A </td>
  </tr>
</table>

<table border="1">
  <tr>
    <td><b>TÍTULO </b></td>
    <td colspan="2">  MÉTODO Y SISTEMA PARA LA DETECCIÓN DE MICROPLÁSTICOS CON TAMAÑO DE PARTÍCULA PEQUEÑO, DISPOSITIVO ELECTRÓNICO Y MEDIO   </td>
  </tr>
  <tr>
    <td>   CIP: G01N1/28  </td>
    <td colspan="2"> Preparing specimens for investigation including physical details of (bio-)chemical methods covered elsewhere, e.g. G01N33/50, C12Q (mounting specimens on microscopic slides G02B21/34; means for supporting the objects or the materials to be analysed in electron microscopes H01J37/20 ; laboratory gas handling apparatus B01L5/00)    </td>
  </tr>
  <tr>
    <td> NÚMERO DE PUBLICACIÓN </td>
    <td>  US2024125677A1 </td>
    <td> IMAGEN </td>
  </tr>
  <tr>
    <td style="width:15%"> Resumen </td>
    <td style="width:40%">  Se divulga un método y un sistema para detectar microplásticos de tamaño de partícula pequeño, así como un dispositivo electrónico y un medio.
El método incluye: ampliar el mosaico de la membrana de filtrado de la muestra de microplásticos que se va a preseleccionar mediante múltiples aumentos, para obtener varios mosaicos ampliados de la membrana de filtrado; identificar cada uno de los mosaicos ampliados mediante una herramienta de identificación de partículas, para obtener el mosaico con la mayor tasa de identificación; identificar dicho mosaico con la mayor tasa de identificación bajo múltiples combinaciones de parámetros de identificación, para obtener un conjunto preliminar de parámetros; identificar cada una de las muestras de microplásticos bajo cada combinación de parámetros del conjunto preliminar, para obtener una tasa de identificación y una precisión de identificación de la muestra bajo cada combinación; y obtener una combinación óptima de parámetros de identificación.
   </td>
    <td style="width:45%" >   </td>
  </tr>
  <tr>
    <td > LINK </td>
    <td colspan="3">  https://worldwide.espacenet.com/patent/search?q=pn%3DUS2024125677A1 </td>
  </tr>
</table>

<table border="1">
  <tr>
    <td><b>TÍTULO </b></td>
    <td colspan="2">   EQUIPO ELECTRÓNICO PORTÁTIL PARA LA DETECCIÓN DE MICROPLÁSTICOS EN AGUA </td>
  </tr>
  <tr>
    <td>   CIP: C12Q 1/00   </td>
    <td colspan="2">  Procesos de medida, investigación o análisis en los que intervienen enzimas, ácidos nucleicos o microorganismos (aparatos de medida, investigación o análisis con medios de medida o detección de las condiciones del medio, p. ej. contadores de colonias, C12M 1/34); Composiciones para este fin; Procesos para preparar estas composiciones   </td>
  </tr>
  <tr>
    <td> NÚMERO DE PUBLICACIÓN </td>
    <td> 002302-2024/DIN  </td>
    <td> IMAGEN </td>
  </tr>
  <tr>
    <td style="width:15%"> Resumen </td>
    <td style="width:40%">  El invento propuesto consiste en un equipo electrónico portátil diseñado para la detección de micro plásticos en el agua, con el objetivo de monitorear la contaminación de aguas fluviales, dado que muchas veces las técnicas habituales implican llevar a un laboratorio y analizar la presencia de microplásticos. Este equipo ayuda a tener los primeros análisis in situ que permitan identificar la sospecha de presencia de microplásticos con cierto grado de confiabilidad, guardar esa información en el equipo y enviar a través de una conexión a otro dispositivo. El equipo electrónico portátil comprende: una dimensión de 21.5cm de largo, 17.5 cm de profundidad y 18.7cm de altura con un peso menor a 3kg donde proporciona una mayor libertad, flexibilidad y conveniencia en su uso por el usuario. Asimismo, la facilidad de insertar la muestra en el portamuestra (3) sin ocupar varios tubos de ensayos, químicos y varios complementos el cual demanda mucho tiempo para conocer los resultados. Otro de los componentes el cual el equipo electrónico portátil comprende: un computador de placa reducida (19) donde ejecuta el algoritmo de inteligencia artificial para el proceso de los algoritmos; dos cámaras (15) y (15') para poder capturar las imágenes; interruptor magnético (22) para la inicialización automática; un sistema de geolocalización módulo GNSS (18) para registrar la ubicación exacta del análisis, LED UV 365nm (17), una batería (20) interna, una Pantalla táctil de 7'' LCD (14) donde se visualizará los resultados analizados y en la cual se podrá interactuar con una interfaz gráfica; dos lentes de filtros ópticos de 450nm pasa altas (16) y (16') para atenuar las la longitud de onda no deseada y un imán (21) para realizar el proceso automático del sistema.   </td>
    <td style="width:45%" >   </td>
  </tr>
  <tr>
    <td > LINK </td>
    <td colspan="3">  https://servicio.indecopi.gob.pe/portalSAE/index.html  </td>
  </tr>
</table>

<table border="1">
  <tr>
    <td><b>TÍTULO </b></td>
    <td colspan="2">  PLASTIC DEBRIS AND MICROPLASTICS DETECTION METHOD BASED ON RGB AND HYPERSPECTRAL IMAGE FUSION  </td>
  </tr>
  <tr>
    <td>  CIP: 
 GO1N21/00
   </td>
    <td colspan="2">  Investigating or analysing materials by the use of optical means, i.e. using sub-millimetre waves, infrared, visible or ultraviolet light (GO1N3/00 - GO1N19/00 take precedence)   </td>
  </tr>
  <tr>
    <td> NÚMERO DE PUBLICACIÓN </td>
    <td> W02024066118A1   </td>
    <td> IMAGEN </td>
  </tr>
  <tr>
    <td style="width:15%"> Resumen </td>
    <td style="width:40%">  Método de detección de residuos plásticos y microplásticos basado en la fusión de imágenes RGB e hiperespectrales . El método comprende los siguientes pasos: obtención de residuos plásticos y microplásticos ; mezcla de los residuos plásticos y los microplásticos con residuos sólidos para obtener una matriz de fase sólida; pretratamiento de la matriz de fase sólida para obtener un material; secado del material para eliminar parte de la humedad y posterior recubrimiento sobre una lámina de cuarzo, secado del material hasta su completa eliminación de la humedad y prensado del material plano con otra lámina de cuarzo para obtener un material a analizar; uso de un escáner de imágenes en color de alta resolución y una cámara hiperespectral para obtener una imagen RGB y una imagen hiperespectral del material a analizar; fusión de la imagen RGB con la imagen hiperespectral ; y uso de un modelo de clasificación supervisada para clasificar e identificar automáticamente los residuos plásticos y los microplásticos . No se requieren pasos de separación como la flotación por densidad, lo que reduce la pérdida de residuos plásticos y microplásticos durante el pretratamiento. El tiempo necesario para la detección es corto y se logra un análisis de alto rendimiento de una gran cantidad de muestras; además, se amplía el rango de tamaño de identificación de los residuos plásticos y los microplásticos , y se mejora la precisión de la identificación.

   </td>
    <td style="width:45%" >   </td>
  </tr>
  <tr>
    <td > LINK </td>
    <td colspan="3">  https://worldwide.espacenet.com/patent/search?q=pn%3DWO2024066118A1

 </td>
  </tr>
</table>

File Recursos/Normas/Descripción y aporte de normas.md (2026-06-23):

# 📜 DESCRIPCIÓN Y APORTE DE NORMAS

<p align="center">
  <a href="https://www.une.org/encuentra-tu-norma/busca-tu-norma/norma/?c=N0073033" target="_blank">
    
  </a>
  <a href="https://www.iso.org/obp/ui/en/#iso:std:iso:16094:-2:ed-1:v1:en" target="_blank">
    
  </a>
  <a href="https://www.iso.org/obp/ui/en/#iso:std:iso:7027:-1:ed-1:v1:en" target="_blank">
    
  </a>
</p>

### 📄 NORMA 1: UNE-EN ISO 7027-1 / ISO 7027-1 (Calidad del Agua - Determinación de la Turbidez)
<p align="justify">
-Resumen: Especifica los métodos estándar internacionales para determinar la turbidez del agua. Describe la metodología cuantitativa usando medidores ópticos de radiación (nefelómetros) para evaluar la concentración de partículas suspendidas basándose en cómo dispersan la luz.</p>

<p align="justify">
-Aporte a Yaku-Ñawi: Es el fundamento matemático y físico directo de nuestro Sensor de Turbidez. Esta norma justifica técnicamente por qué usas un sensor óptico infrarrojo (LED emisor y fototransistor receptor) para leer el nivel de opacidad del agua antes de buscar microplásticos, permitiéndote calibrar el algoritmo en tu XIAO ESP32-S3 bajo rangos estandarizados de turbidez.</p>

### 📄 NORMA 2: ISO 16094-2 (Plásticos - Evaluación de la Degradabilidad de Plásticos en Agua)
<p align="justify">
-Resumen: Establece los criterios y métodos estandarizados para evaluar la degradación física, pérdida de masa y fragmentación de materiales plásticos cuando están expuestos a ambientes acuáticos fluviales o marinos en condiciones controladas.
</p>
<p align="justify">
-Aporte a Yaku-Ñawi: Nos brinda el marco teórico para la clasificación del problema. Justifica la necesidad del prototipo, ya que los plásticos no desaparecen en el agua, sino que según esta norma se fragmentan continuamente hasta convertirse en microplásticos de tamaños milimétricos. Sustenta por qué el diseño del prototipo debe integrar una Cámara OV3660 con iluminación LED (UV-A y Blanco) para reconocer ópticamente esas partículas fragmentadas que la norma detalla.
</p>

### 📄 NORMA 3: ISO 7027-1 (Organización Internacional de Normalización)
<p align="justify">
Resumen: Describe el método estandarizado para determinar la turbidez del agua mediante la medición cualitativa y cuantitativa de partículas suspendidas en una muestra líquida empleando métodos ópticos calibrados.
</p>
  
<p align="justify">
Aporte a Yaku-Ñawi: Esta norma exige el uso de métodos ópticos calibrados para detectar impurezas, lo cual convalida directamente la integración y calibración matemática del Sensor de Turbidez analógico en los pines GPIO del ESP32-S3 para medir la claridad del agua de manera previa a la detección visual de los plásticos.
</p>

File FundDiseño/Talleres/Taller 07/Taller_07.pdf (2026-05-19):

## 1. Lista de Exigencias

Tabla 1: Lista de Exigencias

LISTA DE EXIGENCIAS

Páginas: 6

Edición: Rev. 2

PROYECTO:

YAKU-ÑAWI dispositivo portátil de detección de microplásticos PP y PET en playas y humedales de Lima

Fecha: 21/04/2026

Revisado:

CLIENTE: | Docentes del curso de Fundamentos de diseño de la Universidad Peruana Cayetano Heredia | Elaborado: ●Alarcon Camones, Marcelo Valentino. ● Cerdan Dongo, Rebeca Milagros. ●Evangelista Noreña, Bruno Felix Agustin. ●Fernandez Rimarachín, Yakori Siclali. ●Quispe Garcia, Mariluz.
Fecha (cambios) | Deseo o Exigencia | Descripción | Responsable
27/04/26 | E | Función Principal: Detectar microplásticos de tamaño 0.3 y 5 mm (ISO 24187:2023) de tipo polipropileno (PP) y polietileno tereftalato (PET) en muestras ambientales mediante análisis automatizado de imágenes basado en inteligencia artificial para el monitoreo ambiental en playas y humedales de Lima. | Todos
28/04/26 | E | Geometría: El dispositivo portátil Yaku-Ñawi deberá presentar una estructura compacta tipo domo o platillo protector, diseñada para integrar los componentes físicos del sistema, incluyendo hardware electrónico, cámara de captura de imágenes y la interfaz física del usuario, cuyas dimensiones no deberán exceder los 35 cm de diámetro y 25 cm de altura (UNEP, 2021; ISO 9241 Ergonomics). | Alarcon Camones Marcelo Valentino Quispe Garcia, Mariluz.
| | Cinemática: No aplica
05/05/26 | E | Fuerzas: El dispositivo deberá garantizar estabilidad estructural durante su operación en entornos marino-costeros, soportando fuerzas asociadas al peso propio, manipulación del operador y perturbaciones ambientales como oleaje leve. El sistema deberá presentar un peso igual a <= 3 kg, mantener estabilidad ante inclinaciones de hasta 15° sin volcamiento y contar con una carcasa rígida que protege los componentes electrónicos y la cámara(UNEP, 2021),(UNEP, 2021),(IEC 60529). | Cerdan Dongo, Rebeca Milagros. Evangelista Noreña, Bruno Felix Agustin.
08/05/26 | E | Energía: El dispositivo contará con una fuente luminosa tipo LED UV-A dentro del rango espectral de 315–400 nm, preferentemente entre 365 y 395 nm, permitiendo inducir | Quispe Garcia, Mariluz
MTR 240 | 2026-1 | página 1

fluorescencia en microplásticos PP y PET para su identificación mediante visión computacional (IEC 62471). El dispositivo contará con una fuente de energía portátil basada en una batería recargable de ion-litio.

10/05/26

E

Materia: La materia de ingreso del sistema Yaku-Ñawi estará conformada por imágenes digitales capturadas en playas y humedales de Lima, las cuales contendrán partículas de microplásticos, principalmente polímeros PP (polipropileno) y PET (polietileno tereftalato). (Andrady 2017; GESAMP, 2019).

La materia de salida es información digital procesada mediante inteligencia artificial y análisis de imágenes, incluyendo detección automática, clasificación preliminar de microplásticos en PP o PET y estimación del nivel relativo de contaminación en el área observada, contribuyendo al monitoreo ambiental de residuos plásticos (Li et al., 2020; UNEP, 2021).

Fernández
Rimarachín, Yakori
Siclali.

15/05/26

E

Señales (Información): El sistema Yaku-Ñawi deberá contar con señales de entrada y salida que permitan la interacción entre el usuario, los componentes electrónicos y el sistema de procesamiento basado en inteligencia artificial.

Señales de entrada:

- Señal de encendido: Permite energizar el sistema electrónico, sensores, cámara y unidad de procesamiento.
- Señal de inicio de monitoreo: Activa el proceso de captura de imágenes y análisis automático de microplásticos.
- Señal de parada: Permitirá detener la captura y procesamiento de datos en cualquier etapa de operación.
Señales de salida:
- Señal de estado del sistema (Stand-by): Indica que el dispositivo se encuentra energizado y listo para operar.
- Señal de operación activa: Confirma que la cámara y el sistema de inteligencia artificial están ejecutando el monitoreo ambiental.
- Señal de alerta o emergencia: Notifica condiciones anómalas como batería baja, falla del sensor, pérdida de estabilidad o error de procesamiento.
- Señal de resultados: Muestra al usuario los datos obtenidos del análisis, incluyendo detección y estimación de microplásticos presentes en el área evaluada.
- Señal de fin de proceso: Indica la finalización del ciclo de captura y análisis de imágenes.
- Señal de geolocalización: Permite identificar la ubicación del dispositivo mediante coordenadas GPS durante el monitoreo.

Evangelista Noreña,
Bruno Felix Agustin.

Fernández
Rimarachín, Yakori
Siclali.
19/05/26 | E
Control: El dispositivo deberá mantener estabilidad operativa durante todas las etapas de funcionamiento,

Quispe Garcia,
Mariluz.

garantizando la correcta coordinación entre el sistema de captura de imágenes, los sensores electrónicos y la unidad de procesamiento basada en inteligencia artificial.

El control deberá gestionar automáticamente la activación de la cámara, adquisición de datos y ejecución del algoritmo de detección de microplásticos PP y PET, asegurando precisión en el análisis y eficiencia energética durante la operación. Asimismo, el sistema deberá supervisar variables críticas como estado de batería, funcionamiento de sensores, almacenamiento de datos y condiciones operativas del dispositivo, permitiendo una operación segura y confiable en entornos acuáticos abiertos (ISO 12100; IEC 61508; UNEP, 2021).

Cerdan Dongo,
Rebeca Milagros.

22/05/26

E

Electrónico (hardware): El dispositivo Yaku-Ñawi empleará un sistema electrónico integrado orientado a la adquisición y procesamiento de información visual para la detección de microplásticos PP y PET. El hardware estará conformado por una unidad de control basada en ESP32, encargada de coordinar la captura de imágenes, la comunicación entre sensores y la gestión energética del sistema, utilizando programación en C++.

El sistema incorporará una cámara de captura de imágenes asistida por una fuente de iluminación (LED UV-A) controlada, filtros ópticos y un sistema de ampliación tipo lupa, con el objetivo de mejorar la visibilidad y diferenciación espectral de partículas micro plásticas en la parte superficial del mar. La información adquirida será procesada mediante algoritmos de visión computacional basados en YOLOv8, permitiendo la identificación automática de microplásticos.

Asimismo, el hardware deberá integrar módulos electrónicos de alimentación, regulación de potencia y protección eléctrica que garanticen el funcionamiento estable, eficiente y seguro del dispositivo en condiciones ambientales de campo (IEC 62368-1; IEEE Embedded Systems Standards.)

Cerdan Dongo,
Rebeca Milagros.

Evangelista Noreña,
Bruno Felix Agustin.

Fernandez
Rimarachín, Yakori
Siclali.

24/05/26

E

Software: El sistema Yaku-Ñawi emplea software de código abierto orientado al control del dispositivo, adquisición de imágenes y procesamiento inteligente de la información capturada. El control del sistema lo programaremos en C++, ejecutándose sobre la plataforma ESP32 para gestionar la activación de sensores, cámara y funcionamiento general del dispositivo.

El análisis de imágenes se realizará mediante un modelo de visión computacional basado en YOLOv8, permitiendo la detección automática de microplásticos PP y PET a partir de las imágenes obtenidas. El sistema deberá presentar una interfaz básica de operación que permite iniciar, detener y visualizar los resultados del monitoreo, priorizando simplicidad, eficiencia operativa y facilidad de uso en entornos de campo (IEEE Open Source Software Guidelines; ISO/IEC 25010).

Cerdan Dongo,
Rebeca Milagros.

Evangelista Noreña,
Bruno Felix Agustin.

Fernandez
Rimarachín, Yakori
Siclali.

Alarcon Camones
Marcelo Valentino
26/05/26 | E | Comunicaciones: El controlador de Yaku-Ñawi debe poder | Quispe Garcia,

comunicarse con los distintos módulos del dispositivo, incluyendo el sensor óptico, módulo de captura de imágenes (ESP32-CAM) y la unidad de procesamiento a través de un sistema directo de cableado. Además, debe ser capaz de procesar correctamente la información o la transmisión de datos. Asimismo, los dispositivos de mando deben procesar las señales capturadas para su posterior análisis.

Mariluz.
Cerdan Dongo,
Rebeca Milagros.

28/05/26

E

Seguridad: El dispositivo deberá garantizar la seguridad del usuario y del sistema durante su operación en playas y humedales. La carcasa protectora deberá ser resistente a humedad, salinidad y partículas ambientales IEC 60529 (grado IP).

El sistema operará con niveles seguros de tensión eléctrica e
incorporará | protección | frente | a | sobrecorriente | y
sobrecalentamiento conforme a IEC 62368-1. Asimismo, el dispositivo deberá incluir un mecanismo de apagado seguro accesible al usuario y cumplir con la Ley N°29783 de Seguridad y Salud en el Trabajo e ISO 45001. La fuente luminosa utilizada para el análisis óptico deberá operar dentro de niveles seguros establecidos por IEC 62471

Asimismo, el dispositivo deberá incorporar un módulo GPS destinado exclusivamente a la localización del equipo, permitiendo conocer su posición geográfica en tiempo real para fines de seguridad, seguimiento y recuperación ante pérdida, desplazamiento no autorizado o robo.

Alarcon Camones
Marcelo Valentino.

Cerdan Dongo,
Rebeca Milagros.

02/05/26

E

Ergonomía: El dispositivo portátil Yaku-Ñawi deberá presentar una disposición de controles e interfaz de usuario que facilite su manipulación segura y cómoda durante operaciones de monitoreo ambiental en campo. La altura, ubicación y acceso a los dispositivos de mando deberán diseñarse de manera que no generen posturas forzadas ni fatiga en el operador (ISO 7250), Basic human body measurements for technological design). Asimismo, el equipo deberá poder ser transportado de manera manual y fácil por un solo usuario, garantizando facilidad de uso en ambientes costeros.

Fernandez
Rimarachín, Yakori
Siclali.

05/06/26

E

Fabricación: El dispositivo portátil deberá diseñarse para su fabricación utilizando materiales disponibles en el mercado nacional y de fácil reposición, priorizando componentes electrónicos comerciales compatibles con plataformas embebidas. La carcasa protectora deberá fabricarse mediante polímeros técnicos ligeros y resistentes a la humedad, salinidad y radiación solar, como ABS, PETG o policarbonato, permitiendo su manufactura mediante impresión 3D o mecanizado ligero en talleres locales.

El diseño deberá ser modular para facilitar el ensamblaje, mantenimiento y reemplazo de componentes electrónicos, garantizando viabilidad de fabricación y transporte del dispositivo. Asimismo, los materiales electrónicos deberán cumplir criterios de seguridad ambiental establecidos en la directiva RoHS (2011/65/EU) y estándares de calidad de fabricación según ISO 9001, asegurando durabilidad y

Todos

| | operación adecuada en ambientes marino-costeros.
07/06/26 | E | Control de calidad: El diseño y la fabricación de Yaku-Ñawi debe contemplar todas las exigencias planteadas en esta lista a fin de que cumpla con un funcionamiento afín a las necesidades del usuario y en el contexto ambiental de la preservación de los ecosistemas marinos y calidad de agua. Esto incluye que cumpla con los requisitos de diseño como dimensiones, tolerancias, materiales a emplear, etc; así como de análisis, identificación, seguridad, medioambientales y aquellos que garanticen un producto apto para el mercado. | Alarcon Camones, Marcelo Valentino. Fernandez Rimarachín, Yakori Siclali. Quispe Garcia, Mariluz.

09/06/26

E

Montaje: El dispositivo Yaku-Ñawi deberá presentar un diseño de montaje modular y portátil que permita su instalación rápida y segura en playas y humedales sin requerir fijación permanente al suelo. El sistema deberá garantizar estabilidad durante la operación mediante una base nivelada o estructura flotante que evita vibraciones o movimientos bruscos que afecten la captura de imágenes y el funcionamiento del sistema de detección.

Asimismo, el dispositivo deberá contar con un sistema de energización compatible con fuentes locales de alimentación portátil, priorizando baterías recargables de ion-litio y conexiones eléctricas seguras para operación en campo, conforme a criterios de seguridad para equipos electrónicos establecidos en IEC 62368-1.

Cerdan Dongo,
Rebeca Milagros.

Evangelista Noreña,
Bruno Felix Agustin.

14/06/26

E

Transporte: El dispositivo portátil Yaku-Ñawi deberá presentar un diseño ligero y compacto que facilita su transporte hacia zonas de monitoreo ambiental. El peso total del sistema deberá ser ≤ 3 kg, permitiendo su traslado manual por un solo operador y su movilización mediante transporte terrestre o marítimo, como vehículos o embarcaciones menores. Asimismo, el equipo deberá contar con una estructura resistente a vibraciones y condiciones ambientales propias del traslado hacia playas y humedales, garantizando la integridad de sus componentes electrónicos durante el transporte.

Todos

16/06/26

D

Uso: Yaku-Ñawi deberá operar bajo diversas condiciones ambientales presentes en playas y humedales del territorio peruano, considerando variaciones de temperatura, humedad, parámetros que deberán ser considerados en la selección de sensores, materiales y componentes electrónicos. El sistema estará diseñado para realizar monitoreo superficial del agua, efectuando la detección de microplásticos de entre 0.3 y 5 mm, y sedimentos superficiales, con una profundidad de operación aproximada entre 5 y 20 cm, zona donde se reporta mayor concentración de microplásticos flotantes y sedimentados en ecosistemas costeros.

Quispe Garcia,
Mariluz.

19/06/26
E

Mantenimiento:
- Componentes mecánicos y eléctricos: Acceso a Yaku-Ñawi para inspección, reparación o cambio de piezas después de ser extraído del mar de la playa.

Evangelista Noreña,
Bruno Felix Agustin.

- Componentes electrónicos: Sensores, cámara ESP32, GPS y batería.
| D | Costos: Para la realización de este proyecto en ámbito universitario, consideramos una estimación del costo del diseño en S/300, por concepto de la batería de Litio, los aparatos electrónicos, GPS y cámara ESP32 con WiFi-Bluetooth | Cerdan Dongo, Rebeca. Alarcon Camones, Marcelo Valentino.
30/06/26 | E | Plazos: El proyecto Yaku-Ñawi empezará el martes 28 de abril y se espera su finalización el miércoles 30 de junio con un total aproximado de 3 meses de trabajo. | Todos

## Bibliografía Lista de Requerimientos

1. ISO 24187:2023(en), Principios para el análisis de microplásticos presentes en el medio ambiente. (s. f.). Recuperado 28 de abril de 2026, de https://www.iso.org/obp/ui/es/#iso:std:iso:24187:ed-1:v1:
2. Environment, U. N. (s. f.). UNEP - UN Environment Programme. Recuperado 28 de abril de 2026, de https://www.unep.org/node
3. ISO 9241-210:2010. (s. f.). ISO. Recuperado 28 de abril de 2026, de https://www.iso.org/standard/52075.html
4. Ensayos de Protección IP (Ingress Protection) en Productos de Iluminación: Norma IEC 60529. (s. f.). Recuperado 28 de abril de 2026, de https://www.intertek.es/iluminacion/ip-ingress-protection-iec-60529/
5. Hardin, W. (2019, noviembre 26). IEC 62471 for LED Lighting Products. Smart Vision Lights. https://smartvisionlights.com/resources/lighting-basics-resources/iec-62471-for-led-lighting-products/ (https://smartvisionlights.com/resources/lighting-basics-resources/iec-62471-for-led-lighting-products/)
6. Andrady, A. L. (2017). The plastic in microplastics: A review. Marine Pollution Bulletin, 119(1), 12-22. https://doi.org/10.1016/j.marpolbul.2017.01.082
7. Guidelines for the Monitoring and Assessment of Plastic Litter in the Ocean. (s. f.). GESAMP. Recuperado 28 de abril de 2026, de https://www.gesamp.org/publications/guidelines-for-the-monitoring-and-assessment-of-plastic-litter-in-the-ocean (https://www.gesamp.org/publications/guidelines-for-the-monitoring-and-assessment-of-plastic-litter-in-the-ocean)
8. Ho, Y.-S. (2021). Comentarios sobre: Li et al. (2020) «Estructura del conocimiento de la concesión de licencias tecnológicas basada en la red de palabras clave conjuntas: una revisión y direcciones futuras» International Review of Economics & Finance , 66: 154-165. International Review of Economics & Finance, 75, 267-268. https://doi.org/10.1016/j.iref.2021.03.018
9. ISO 12100:2010. (s. f.). ISO. Recuperado 28 de abril de 2026, de https://www.iso.org/standard/51528.html
10. Safety and functional safety. (s. f.). Recuperado 28 de abril de 2026, de https://www.iec.ch/functional-safety
11. Certificación según el estándar IEC 62368-1. (s. f.). Recuperado 28 de abril de 2026, de https://www.intertek.es/electrico-electronico/certificacion-estandar-iec-62368-1/
12. IEEE SA - IEEE 3121-2025. (s. f.). Recuperado 28 de abril de 2026, de https://standards.ieee.org/ieee/3121/10752/
13. Open Source. IEEE Standards Association [Internet]. [citado 28 de abril de 2026]. Disponible en: https://standards.ieee.org/initiatives/opensource/
14. ISO 25010 [Internet]. [citado 28 de abril de 2026]. Disponible en: https://iso25000.com/index.php/normas-iso-25000/iso-25010
15. ISO 45001. - Buscar con Google. (s. f.). Recuperado 28 de abril de 2026, de https://www.google.com/search?q=ISO+45001.&oq=ISO+45001.&gs_lcrp=EgZjaHJvbWUyBg gAEEUYOTIHCAEQABiABDIICAIQABgWGB4yCAgDEAAYFhgeMggIBBAAGBYYHjIICAUQA BgWGB4yCAgGEAAYFhgeMggIBxAAGBYYHjIICAgQABgWGB4yCAgJEAAYFhge0gEJNDky OGowajE1qAIIsAIB8QWy3XwD-BVFavEFst18A_gVRWo&sourceid=chrome&ie=UTF-8 (https://www.google.com/search?q=ISO+45001.&oq=ISO+45001.&sourceid=chrome)
16. Ley N.° 29783. (s. f.). Recuperado 28 de abril de 2026, de https://www.gob.pe/institucion/congreso-de-la-republica/normas-legales/462576-29783
17. ISO 7250-1:2017. (s. f.). ISO. Recuperado 28 de abril de 2026, de https://www.iso.org/standard/65246.html
18. Directive 2011/65/EU of the European Parliament and of the Council of 8 June 2011 on the restriction of the use of certain hazardous substances in electrical and electronic equipment (recast) Text with EEA relevance. OJ L [Internet]. 8 de junio de 2011. Disponible en: http://data.europa.eu/eli/dir/2011/65/oj
19. ISO 9001:2015(es), Sistemas de gestión de la calidad — Requisitos [Internet]. [citado 28 de abril de 2026]. Disponible en: https://www.iso.org/obp/ui/#iso:std:iso:9001:ed-5:v1:es
20. Standard | IECEE. (s. f.). Recuperado 28 de abril de 2026, de
https://www.iecee.org/certification/iec-standards/iec-62368-12018

## CAJA NEGRA Y ESTRUCTURA DE FUNCIONES



BOCETO 1
TÍTULO DEL BOCETO: Disco Toroidal


LISTA DE DESPIECE


PIEZA | NOMBRE | MATERIAL
1 | antena | plástico protector
2 | Plataforma superior | ABS/Policarbonato
3 | Cúpula protectora | Plástico técnico
4 | cámara + lente | PCB (ESP32 + batería)
5 | Iluminación LED UV-A | Módulo LED (315–400 nm)
6 | Rejilla filtrante | ABS/Policarbonato
7 | Estructura inferior | ABS/ TPR antideslizante

DESCRIPCIÓN DE FUNCIONAMIENTO:
El dispositivo flota en la superficie del agua gracias a las almohadillas de la silicona en forma de disco toroidal, que brindan estabilidad y absorben pequeñas olas y movimientos.
La plataforma superior protege los componentes internos y permite su manipulación mediante las asas laterales, en la parte inferior la cúpula transparente protege la cámara y el sistema óptico, permitiendo la captura de imágenes de agua.
En la parte inferior, el agua ingresa a través de la rejilla filtrante, que retiene partículas y microplásticos, permitiendo su análisis mediante visión computacional.
El sistema electrónico procesa la información para detectar microplásticos y mostrar resultados. La estructura está sellada y protegida contra, agua, humedad y salinidad.


BOCETO 2
TÍTULO DEL BOCETO: Catamarán modular

LISTA DE DESPIECE


PIEZA | NOMBRE | MATERIAL
1 | Antena /comunicación | ABS / Policarbonato
2 | Carcasa superior sellada | ABS / Policarbonato
3 Pontones flotantes (doble | flotación) | Eva/ espuma sellada
4 | Cámara + lente + filtro | Vidrio óptico/ plástico técnico
5 | Iluminación LED UV-A | Módulo LED (315- 400 mm)
6 Módulo electrónico (ESP32 + | batería) | PCB
7 | Estabilizadores laterales | Plástico técnico / goma

DESCRIPCIÓN DE FUNCIONAMIENTO:
El dispositivo flota sobre el agua gracias a sus pontones, manteniendo estabilidad durante la operación. Al activarse, la cámara captura imágenes de la superficie mientras los LED UV-A inducen fluorescencia en microplásticos. Estas imágenes son procesadas por el sistema para detectar y estimar su presencia. El equipo monitorea su estado en todo momento y finaliza el proceso al recibir la orden del usuario.

BOCETO 3
TÍTULO DEL BOCETO: Boya inteligente


LISTA DE DESPIECE


PIEZA | NOMBRE | MATERIAL
1 | Antena / comunicación | ABS / Policarbonato
2 | Carcasa cilíndrica principal | ABS / Policarbonato
3 | Cúpula transparente inferior | Policarbonato / Acrílico
4 | Cámara + lente + filtro óptico | Vidrio óptico / Plástico técnico
5 Sistema de iluminación LED | UV-A | Módulo LED
6 Compartimento electrónico | (ESP32 + batería) | PCB
7 Módulo de estabilidad interna | (lastre) | Acero inoxidable

DESCRIPCIÓN DE FUNCIONAMIENTO:
El dispositivo flota verticalmente, manteniendo la electrónica fuera del agua y el módulo de análisis parcialmente sumergido. La cámara inferior, junto con la iluminación UV-A, captura imágenes del agua para detectar microplásticos. El agua ingresa por rejillas filtrantes que concentran partículas, facilitando su identificación mediante visión computacional. El sistema procesa la información, monitorea su estado y muestra resultados, operando dentro de una carcasa sellada resistente a humedad y salinidad.

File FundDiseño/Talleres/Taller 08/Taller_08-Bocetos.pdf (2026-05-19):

BOCETO 1
TÍTULO DEL BOCETO: Disco Toroidal


LISTA DE DESPIECE


PIEZA | NOMBRE | MATERIAL
1 | antena | plástico protector
2 | Plataforma superior | ABS/Policarbonato
3 | Cúpula protectora | Plástico técnico
4 | cámara + lente | PCB (ESP32 + batería)
5 | Iluminación LED UV-A | Módulo LED (315–400 nm)
6 | Rejilla filtrante | ABS/Policarbonato
7 | Estructura inferior | ABS/ TPR antideslizante

DESCRIPCIÓN DE FUNCIONAMIENTO:
El dispositivo flota en la superficie del agua gracias a las almohadillas de la silicona en forma de disco toroidal, que brindan estabilidad y absorben pequeñas olas y movimientos.
La plataforma superior protege los componentes internos y permite su manipulación mediante las asas laterales, en la parte inferior la cúpula transparente protege la cámara y el sistema óptico, permitiendo la captura de imágenes de agua.
En la parte inferior, el agua ingresa a través de la rejilla filtrante, que retiene partículas y microplásticos, permitiendo su análisis mediante visión computacional.
El sistema electrónico procesa la información para detectar microplásticos y mostrar resultados. La estructura está sellada y protegida contra, agua, humedad y salinidad.


BOCETO 2
TÍTULO DEL BOCETO: Catamarán modular

LISTA DE DESPIECE


PIEZA | NOMBRE | MATERIAL
1 | Antena /comunicación | ABS / Policarbonato
2 | Carcasa superior sellada | ABS / Policarbonato
3 Pontones flotantes (doble | flotación) | Eva/ espuma sellada
4 | Cámara + lente + filtro | Vidrio óptico/ plástico técnico
5 | Iluminación LED UV-A | Módulo LED (315- 400 mm)
6 Módulo electrónico (ESP32 + | batería) | PCB
7 | Estabilizadores laterales | Plástico técnico / goma

DESCRIPCIÓN DE FUNCIONAMIENTO:
El dispositivo flota sobre el agua gracias a sus pontones, manteniendo estabilidad durante la operación. Al activarse, la cámara captura imágenes de la superficie mientras los LED UV-A inducen fluorescencia en microplásticos. Estas imágenes son procesadas por el sistema para detectar y estimar su presencia. El equipo monitorea su estado en todo momento y finaliza el proceso al recibir la orden del usuario.

BOCETO 3
TÍTULO DEL BOCETO: Boya inteligente


LISTA DE DESPIECE


PIEZA | NOMBRE | MATERIAL
1 | Antena / comunicación | ABS / Policarbonato
2 | Carcasa cilíndrica principal | ABS / Policarbonato
3 | Cúpula transparente inferior | Policarbonato / Acrílico
4 | Cámara + lente + filtro óptico | Vidrio óptico / Plástico técnico
5 Sistema de iluminación LED | UV-A | Módulo LED
6 Compartimento electrónico | (ESP32 + batería) | PCB
7 Módulo de estabilidad interna | (lastre) | Acero inoxidable

DESCRIPCIÓN DE FUNCIONAMIENTO:
El dispositivo flota verticalmente, manteniendo la electrónica fuera del agua y el módulo de análisis parcialmente sumergido. La cámara inferior, junto con la iluminación UV-A, captura imágenes del agua para detectar microplásticos. El agua ingresa por rejillas filtrantes que concentran partículas, facilitando su identificación mediante visión computacional. El sistema procesa la información, monitorea su estado y muestra resultados, operando dentro de una carcasa sellada resistente a humedad y salinidad.

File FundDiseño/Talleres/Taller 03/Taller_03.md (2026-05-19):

# INTRODUCCIÓN 
En las últimas décadas, la producción y el uso masivo de plásticos han generado un incremento significativo de residuos sólidos en el ambiente, lo que ha ocasionado la acumulación de partículas plásticas en diversos ecosistemas a nivel mundial. Estas partículas, conocidas como microplásticos, se originan principalmente por la fragmentación de materiales plásticos de mayor tamaño y se han convertido en un contaminante emergente de gran preocupación ambiental y sanitaria (1,2).

Los microplásticos se definen como partículas plásticas con un tamaño menor a 5 mm y pueden encontrarse en una amplia variedad de entornos, incluyendo océanos, ríos, suelos y el aire. Debido a su reducido tamaño y alta resistencia a la degradación, estas partículas permanecen en el ambiente durante largos periodos y pueden transportarse a través de diferentes medios naturales, favoreciendo su dispersión en ecosistemas acuáticos y terrestres (3,4).

En el Perú, la gestión inadecuada de residuos sólidos y el manejo deficiente de los desechos costeros han favorecido la acumulación de plásticos en ambientes marinos. Investigaciones realizadas en la costa peruana han evidenciado la presencia de microplásticos en diversas zonas, demostrando su amplia distribución y su generación continua a partir de la degradación de residuos plásticos (5).

Asimismo, los microplásticos no solo se encuentran en el ambiente, sino que también han sido detectados en organismos vivos, incluyendo especies marinas y seres humanos. Estas partículas pueden ingresar al cuerpo humano mediante la ingestión de alimentos contaminados o la inhalación de aire con partículas suspendidas, lo que ha incrementado la preocupación sobre sus posibles efectos en la salud (6,7).

En este contexto, diversas investigaciones han señalado que la exposición a microplásticos puede provocar efectos adversos como inflamación, estrés oxidativo y alteraciones en tejidos y órganos. Además, estos contaminantes representan una amenaza significativa para los ecosistemas, ya que afectan a organismos acuáticos y pueden alterar las cadenas alimentarias y la biodiversidad (2,8).

Frente a esta problemática, el presente proyecto tiene como objetivo determinar la presencia de microplásticos (MPs) en humedales y playas de Lima mediante la implementación de una metodología para su análisis e identificación, enfocándose en polímeros sintéticos de uso común como el polipropileno (PP) y el polietileno tereftalato (PET). Este tipo de estudios es fundamental para comprender la magnitud de la contaminación por microplásticos y contribuir al desarrollo de estrategias orientadas a la protección de los recursos hídricos y la salud ambiental (9).

En ese sentido, resulta necesario implementar estrategias que permitan mitigar la acumulación de microplásticos en sedimentos y cuerpos de agua. La presente propuesta se enmarca en los Objetivos de Desarrollo Sostenible (ODS), específicamente en el ODS 6, orientado a la protección de la calidad del agua, y en el ODS 14, enfocado en la reducción de la contaminación que afecta la biodiversidad marina. De esta manera, se busca establecer una metodología de diagnóstico escalable y replicable que contribuya a la generación de evidencia científica para la conservación del patrimonio hídrico del Perú (10).

# REFERENCIAS BIBLIOGRÁFICAS
1. Microplastics and human health. Wasser 3.0 [Internet]. 27 de julio de 2024 [citado 13 de abril de 2026].  
   Disponible en: https://wasserdreinull.de/en/blog/microplastics-and-human-health/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
   
2. Snehamayee N, Somya S, Kumar SC, Niranjan M, Ranjan SB, Kumar MN. Microplastics and Human Health: A Comprehensive Review on Exposure Pathways, Toxicity, and Emerging Risks. Microplastics. marzo de 2026;5(1):8.   
   Disponible en: doi:10.3390/microplastics5010008
   
3. Lombardi G, Di Russo M, Zjalic D, Lanza T, Simmons M, Moscato U, et al. Microplastics inhalation and their effects on human health: a systematic review. Eur J Public Health. 25 de octubre de 2022;32(Suppl 3):ckac131.152.  
   Disponible en: doi:10.1093/eurpub/ckac131.152 PubMed PMID: null; PubMed Central PMCID: PMC9835049.
   
4. Luo Q, Tan H, Ye M, Jho EH, Wang P, Iqbal B, et al. Microplastics as an emerging threat to human health: An overview of potential health impacts. J Environ Manage. 1 de julio de 2025;387:125915.  
   Disponible en: doi:10.1016/j.jenvman.2025.125915
 
5. Micro- and mesoplastic pollution along the coast of Peru | Request PDF. ResearchGate. 23 de enero de 2026.  
   Disponible en: doi:10.1007/s11356-023-27707-6
   
6. Emenike EC, Okorie CJ, Ojeyemi T, Egbemhenghe A, Iwuozor KO, Saliu OD, et al. From oceans to dinner plates: The impact of microplastics on human health. Heliyon. 1 de octubre de 2023;9(10):e20440.   
    Dispponible en: doi:10.1016/j.heliyon.2023.e20440
   
7. Thin ZS, Chew J, Ong TYY, Raja Ali RA, Gew LT. Impact of microplastics on the human gut microbiome: a systematic review of microbial composition, diversity, and metabolic disruptions. BMC Gastroenterol. 13 de agosto de 2025;25(1):583.  
   Disponible en: doi:10.1186/s12876-025-04140-2 PubMed PMID: 40804621; PubMed Central PMCID: PMC12351775.
   
8. Ririe AK, Fatema N, Dina TJ, Devi Kuchipudi J, Tamanna P, Libriansyah L, et al. Impact of Microplastic Exposure on Human Health: A Systematic Review of Mechanisms, Biomarkers, and Clinical Outcomes. Cureus. 28 de diciembre de 2025.  
   Disponible en: doi:10.7759/cureus.100295
   
9. Luque Fernández CR. Contaminación por microplásticos en playas arenosas de Islay, departamento de Arequipa [Internet]. 17 de enero de 2020 [citado 1 de abril de 2026].  
    Disponible en: https://repositorio.ucsm.edu.pe/handle/20.500.12920/9869
    
10. Gimiliani GT. Caracterização de microplásticos em amostras marinhas e estuarinas [tesis doctoral]. São Paulo: Instituto de Pesquisas Energéticas e Nucleares, Universidade de São Paulo; 2021.  
    Disponible en: https://www.teses.usp.br/teses/disponiveis/85/85134/tde-22102021-104234/pt-br.php

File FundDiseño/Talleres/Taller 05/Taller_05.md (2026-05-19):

## 🚀 Presentación del Elevator Pitch

<p align="center">
  <a href="https://docs.google.com/document/d/1l3ybWkPrAe1x9EHNxvqltnJuuAEBV3oi/edit" target="_blank">
    
  </a>
  <a href="https://canva.link/wqtahsbx5hdpl2a" target="_blank">
    
  </a>
</p>

<p align="center">
  Accede al documento técnico y a la presentación del proyecto YAKU-ÑAWI.
</p>

# 🌊 YAKU-ÑAWI:

## 1. Historia

Cuando visitamos una playa, solemos pensar que está limpia si no vemos basura alrededor.

Pero la realidad es distinta: la mayor parte de la contaminación ya no es visible.

Cada año se han producido más de 8 300 millones de toneladas de plástico en el mundo, y gran parte termina fragmentándose en partículas diminutas llamadas microplásticos.
Estos microplásticos, especialmente PP y PET, ya se encuentran en el agua, en los peces que consumimos e incluso en el cuerpo humano.

El problema es que detectarlos actualmente requiere laboratorios costosos y mucho tiempo, lo que dificulta monitorear constantemente nuestras playas y humedales.
Ante esta problemática nos hicimos la siguiente pregunta:  
**¿Cómo podemos detectar microplásticos directamente en el lugar donde ocurre la contaminación?**

---

## 2. Problema

La contaminación por microplásticos se ha convertido en un motivo de gran preocupación en los últimos años y, a pesar de haber sido estudiada desde hace unos 20 años (1) debido al uso masivo de plásticos como el polipropileno (PP) y el tereftalato de polietileno (PET), y a una gestión inadecuada de residuos.

- Producción acumulada de plástico: más de 8300 millones de toneladas.
- Presencia creciente de microplásticos en:
    - Ambientes acuáticos y terrestres
    - La atmósfera (2)
    - Los efectos biológicos sobre la vida animal y vegetal (3)
 
Además:
- Las personas pueden:
    - Exponerse directamente en playas y entornos costeros
    - Consumir alimentos de organismos marinos con microplásticos sin saberlo, el cual es perjudicial para la salud
      
- Las tecnologías actuales:
    - Requieren infraestructura especializada
    - El acceso es costoso y limita su uso frecuente en monitoreo ambiental
    - Personal altamente capacitado

👉 **Problema central:**  
Existe una tecnología para detectar microplásticos (FTIR, Raman), pero es costosa, poco portátil y requiere personal especializado, lo que impide el monitoreo continuo y accesible en ecosistemas marinos y costeros.

---

## 3. Solución

Proponemos **YAKU-ÑAWI**, un sistema que:

- Toma de muestra agua, sedimento en playas de Lima o humedales de Chorrillos y Ventanilla.
- Captura imagen con ESP-32 CAM y YOLOv5 integrado al dispositivo portátil
- Procesa los información y datos con IA

Esto permite entender:
- En qué zonas y condiciones hay mayor concentración de microplásticos
- Qué tipo de polímeros predominan (PP, PET u ambos)
- Qué ecosistemas requieren intervención prioritaria

---

## 4. Propuesta de valor

YAKU-ÑAWI no es un equipo electrónico tradicional, sino una solución integral que combina:

- Toma de muestra
- Captura de imagen óptica
- Análisis con IA
- Reporte inmediato
- Parámetro geolocalizador del área de mayor concentración de MPs

Beneficios:
-Reducción significativa de costos operativos
- Análisis ambiental en menor tiempo
- Monitoreo portátil.
- Portabilidad del sistema, el cliente puede trasladar el dispositivo fácilmente entre diferentes playas y humedales.

✔ Enfoque realista:  
Está orientado al **monitoreo y detección ambiental**, no a la eliminación directa de microplásticos, sino a generar información clave para la toma de decisiones y acciones sostenibles.

---

## 5. Modelo de negocio

YAKU-ÑAWI se plantea como una solución de implementación:

- Comercial (venta de dispositivos) 
- Institucional
- Escalable

Dirigida a:
- Entidades gubernamentales (encargadas del monitoreo de calidad de agua como Sedapal)
- Empresas del sector ambiental
- Laboratorios e industrias
- Organizaciones de conservación

Basado en un modelo:
- B2B (Business to Business)
- B2G (Business to Government)

💡 Propuesta:  
Servicio integral que incluye:
- Instalación  
- Mantenimiento
- Soporte técnico
- Análisis personalizado del monitoreo ambiental  

---

## 6. Estrategia

1. Periodo piloto sin costo que permite a las instituciones probar el dispositivo en entornos reales
2. Evaluación del sistema en campo
3. Simulación en la universidad
4. Validación del impacto
5. Generación de alianzas

Objetivo:
- Expandirse tanto regional como globalmente hacia el mercado latinoamericano

---

## 7. Tracción

Actualmente en fase de:

- Análisis del contexto  
- Definición del problema enfocado a los ODS
- Diseño conceptual  

✔ Próximo paso:
- Desarrollo y viabilidad del prototipo funcional en campo

---

## 8. Equipo

Equipo multidisciplinario de estudiantes de:

- Ingeniería Ambiental  
- Ingeniería Informática  
- Ingeniería Industrial

Capacidad:
- Formulación de proyectos con enfoque en sostenibilidad 
- Desarrollo de la solución reales con visiones transversales
- Adaptación al contexto  

---

## 9. Pedido

Buscamos apoyo para:

- Financiamiento inicial para materiales
- Desarrollo del prototipo
- Asesoría técnica
- Espacios de prueba
- Validación en campo
- Alianzas estratégicas

🎯 Objetivo:
Demostrar que la inteligencia artificial puede convertirse en una herramienta accesible, portátil y confiable para detectar microplásticos en ecosistemas marinos y costeros del Perú.

---

## 📚 Referencias

1. Thompson, RC.; Courtene-Jones, W.; Boucher, J.; Pahl, S.; Raubenheimer, K.; Koelmans, AA.
   Veinte años de investigación sobre la contaminación por microplásticos─¿qué hemos aprendido?. Ciencia 2024. Disponible en: https://www.science.org/doi/10.1126/science.adl2746
   
2. Comisión de Investigaciones Científicas.
   Microplásticos en el aire: mapa de una contaminación silenciosa. 2026. Disponible en: https://www.cic.gba.gob.ar/microplasticos-en-el-aire-mapa-de-una-contaminacion-silenciosa/

3. Blackburn K, Green D. 
  Los efectos potenciales de los microplásticos en la salud humana: lo que se sabe y lo que se desconoce. Mar 2022. Dispponible en: https://pubmed.ncbi.nlm.nih.gov/34185251/

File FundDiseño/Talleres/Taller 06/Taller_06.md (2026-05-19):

## MATRIZ DE DESK RESEARCH

**Proyecto:** YAKU-ÑAWI - Sistema portátil de detección y clasificación de microplásticos PP y PET basado en inteligencia artificial   
**Ubicación:** Playas y humedales, Lima – Perú  

**Problematica:**  
¿Cómo diseñar un sistema portátil capaz de detectar y clasificar microplásticos de tipo PET y PP en muestras de agua mediante el análisis de imágenes en tiempo real?

---

| N° | Fuente | Autor/Institución | Año | Referencia | Estado de tecnología encontrada | Exigencia o requisito identificado | Restricción o limitación | Función principal | Aplicación al proyecto |
|----|---|---|-----|---|---|---|---|---|---|
| 1 | Norma | Asociación española de industriales plásticos | 2024 |https://www.une.org/encuentra-tu-norma/busca-tu-norma/norma/?c=N0073033  | Definición y clasificación del tamaño de los microplásticos para su identificación y análisis en muestras ambientales mediante técnicas de laboratorio y observación visual o microscópica. | Define los microplásticos como partículas sólidas insolubles en agua con dimensiones entre 1 µm y 5 mm, estableciendo criterios estandarizados para su identificación, medición y caracterización en estudios ambientales. |No aplica| Clasificación y determinación del tamaño de los microplásticos. |Permite establecer el rango de tamaño que el dispositivo debe detectar e identificar mediante imágenes en tiempo real, asegurando que el sistema funcione dentro de los parámetros definidos para microplásticos.|
| 2 | Norma internacional  |Organización Internacional de Normalización |2025 | https://www.iso.org/obp/ui/en/#iso:std:iso:16094:-2:ed-1:v1:en |Identificación de tipos de polímeros. |Los microplásticos deben identificarse y clasificarse según su tipo de polímero, como polietileno (PE), polipropileno (PP), poliestireno (PS), PET y PVC, utilizando métodos de análisis estandarizados. |La clasificación puede verse afectada si la muestra no se prepara adecuadamente.|Estandarizar el análisis de microplásticos. | Permite definir cómo preparar las muestras antes de capturar imágenes. |
| 3 | Norma internacional |Organización Internacional de Normalización  | 2016 |https://www.iso.org/obp/ui/en/#iso:std:iso:7027:-1:ed-1:v1:en |Método estandarizado para medir partículas suspendidas en agua mediante dispersión de luz|Se deben utilizar métodos ópticos calibrados para detectar partículas presentes en el agua.| Los resultados pueden verse afectados por el tamaño y la concentración de las partículas. |Detección de partículas en agua | Permite justificar el uso de sensores ópticos o cámaras para detectar microplásticos en el agua.|
| 4 | Artículo científico | American Chemical Society | 2023 | https://pubs.acs.org/doi/10.1021/acs.jchemed.3c00370  |Uso de radiación ultravioleta o luz visible para detectar microplásticos mediante fluorescencia.  |Los microplásticos deben exponerse a una fuente de luz adecuada para observar su respuesta óptica o fluorescente.  |La intensidad de la luz y el color del material pueden afectar la detección.  | Identificación de microplásticos mediante radiación o luz. |Permite utilizar iluminación controlada para detectar y diferenciar microplásticos según su respuesta a la radiación. |
| 5 |Artículo científico|Springer Nature | 2021 |https://link.springer.com/article/10.1186/s43591-025-00156-3 |Estudio de cómo los microplásticos reflejan o absorben luz. |Los materiales plásticos presentan propiedades ópticas específicas que permiten su identificación.  | La reflectancia puede variar según el color y la superficie del material. |Identificación de materiales mediante propiedades ópticas. |Permite usar sensores o cámaras para diferenciar microplásticos según su interacción con la luz.|

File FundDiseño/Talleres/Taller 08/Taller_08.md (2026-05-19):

## 
| Certificados de OneShape |
|-------------|
||
||
||
||
||

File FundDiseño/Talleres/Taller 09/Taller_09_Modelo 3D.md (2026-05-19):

Render del Platillo Final
Render del Platillo Final
Render del Platillo Final

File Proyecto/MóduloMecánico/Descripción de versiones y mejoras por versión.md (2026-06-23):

#  🔄 DESCRIPCIÓN DE VERSIONES Y MEJORAS POR VERSIONES

<p align="justify">
El diseño mecánico del proyecto YAKU ÑAWI fue desarrollado utilizando la plataforma de modelado CAD Onshape, herramienta que permitió diseñar, modificar y visualizar las distintas partes del sistema de manera colaborativa. A lo largo del proceso de desarrollo se elaboraron tres versiones del modelo mecánico, incorporando progresivamente mejoras derivadas de las observaciones y recomendaciones realizadas por los docentes durante las diferentes etapas de evaluación.

Las modificaciones realizadas incluyeron cambios en el sistema de apertura de la carcasa, la incorporación de un soporte para la Power Bank, el rediseño del recipiente destinado a la recolección de muestras, pasando de una geometría circular a una prismática, así como la optimización de los soportes para las placas electrónicas y la distribución interna de los componentes. Asimismo, se efectuaron ajustes dimensionales y estructurales orientados a mejorar el ensamblaje, la estabilidad del dispositivo y su proceso de fabricación mediante impresión 3D.

Como resultado, se obtuvo un diseño mecánico funcional que garantiza la correcta integración de todos los componentes del sistema, facilitando su montaje, operación y mantenimiento, además de proporcionar una estructura adecuada para el desarrollo del prototipo final.
</p>

## VERSIÓN 1 (V1)
<p align="justify">
La primera versión correspondió al diseño conceptual del módulo mecánico. En esta etapa se establecieron las dimensiones generales de la carcasa y la ubicación preliminar de los principales componentes electrónicos, tales como la pantalla LCD, sensores, microcontrolador y sistema de alimentación. Este modelo permitió evaluar la viabilidad de integración de todos los elementos dentro de una única estructura.

Adicionalmente, se incorporó un sistema de apertura mediante puertas con bisagras para facilitar el acceso a los componentes internos del dispositivo. Sin embargo, durante las revisiones realizadas por los docentes se identificó que esta alternativa no era la más adecuada para los requerimientos del proyecto, ya que podía dificultar el ensamblaje y limitar la funcionalidad esperada del módulo.

A partir de estas observaciones, se planteó una nueva propuesta de diseño para la siguiente versión, enfocada en optimizar el sistema de apertura, mejorar la distribución interna de los componentes y facilitar el proceso de fabricación y ensamblaje del dispositivo.
</p>
<p align="center">
  
</p>

<p align="center">Imagen 1.imagen 3D versión 1.0</p>

<p align="center">
  
</p>

<p align="center">Imagen 1.imagen 3D versión 1.1</p>

## VERSIÓN 2 (V2): REDISEÑO Y OPTIMIZACIÓN
<p align="justify">
La segunda versión incorporó las observaciones obtenidas durante la primera evaluación. Se realizaron ajustes en la geometría de la carcasa y en la disposición de los componentes internos, permitiendo una mejor organización del sistema y una integración más eficiente de los elementos mecánicos y electrónicos.

Uno de los principales cambios fue la incorporación de un soporte posterior para la Power Bank, con el objetivo de asegurar su correcta fijación y facilitar su integración dentro del dispositivo. Asimismo, se modificó el diseño del recipiente destinado a la recolección de muestras, pasando de una geometría circular a una estructura prismática, lo que permitió un mejor aprovechamiento del espacio disponible y una mayor facilidad de fabricación.

Adicionalmente, se rediseñó el soporte de las placas electrónicas para mejorar su estabilidad y facilitar el montaje de los componentes. También se realizaron ajustes dimensionales en diferentes partes de la estructura con el fin de garantizar un mejor acoplamiento entre las piezas y optimizar el proceso de ensamblaje.

Estas mejoras contribuyeron a incrementar la funcionalidad del dispositivo y sirvieron como base para el desarrollo de la versión final del módulo mecánico.
</p>
<p align="center">
  
</p>

<p align="center">Imagen 1. imagen 3D versión 2.0. </p>

<p align="center">
  
</p>

<p align="center">Imagen 1. imagen 3D versión 2.1 </p>

## VERSIÓN 3 (V3): DISEÑO FINAL
<p align="justify">
La tercera versión corresponde al diseño final del módulo mecánico del proyecto YAKU ÑAWI. En esta etapa se consolidó la distribución definitiva de todos los componentes electrónicos y mecánicos, asegurando una adecuada integración entre cada uno de los elementos del sistema. Asimismo, se verificó la compatibilidad dimensional de las piezas diseñadas en Onshape y se realizaron los ajustes necesarios para optimizar su fabricación mediante impresión 3D.

A partir de las observaciones realizadas durante las versiones anteriores, se perfeccionó la estructura general del dispositivo, mejorando la disposición interna de los componentes, los sistemas de fijación y el acceso a las distintas partes del módulo. Además, se incorporó la identificación visual del proyecto mediante el grabado del nombre “YAKU ÑAWI” en la carcasa y se definieron de manera definitiva las aberturas y perforaciones necesarias para la pantalla LCD, los sensores y los elementos de ensamblaje.

Esta versión representa la solución final del diseño mecánico, logrando una estructura funcional, resistente y de fácil manufactura. El resultado fue un módulo capaz de alojar de forma segura todos los componentes del sistema, facilitando tanto el ensamblaje como las futuras tareas de operación, mantenimiento y validación del prototipo.
</p>
<p align="center">
  
</p>

<p align="center">Imagen 1. imagen 3D versión 3.0 </p>

<p align="center">
  
</p>

<p align="center">Imagen 1. imagen 3D versión 3.1 </p>

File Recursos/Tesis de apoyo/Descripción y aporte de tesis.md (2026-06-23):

# 🎓 TESIS DE REPOSITORIO REFERENCIAL

<table width="100%">
  <tr bgcolor="#34495e">
    <th colspan="2" align="center" style="color: white; padding: 10px;">
      <h3>EVALUACIÓN DE ANTECEDENTE PRINCIPAL (TESIS GUÍA)</h3>
    </th>
  </tr>
  
  <tr>
    <td width="20%" bgcolor="#f8f9fa"><b>Título de la Tesis:</b></td>
    <td>Plastic Net: Aprendizaje profundo para el reconocimiento automático de microplásticos mediante espectroscopia FT-IR</td>
  </tr>
  
  <tr>
    <td bgcolor="#f8f9fa"><b>Detalles Académicos:</b></td>
    <td>
      <b>Autor:</b> Tianyu Zhang &nbsp;|&nbsp; 
      <b>Año:</b> 2021 &nbsp;|&nbsp; 
      <b>Institución:</b> University of Waterloo (Tesis de Maestría)
    </td>
  </tr>
  
  <tr>
    <td bgcolor="#f8f9fa"><b>Enlaces de Acceso:</b></td>
    <td align="left">
      <a href="https://doi.org/10.15353/jcvis.v6i1.3554" target="_blank">
        
      </a>
      <a href="https://doi.org/10.15353/jcvis.v6i1.3554" target="_blank">
        
      </a>
    </td>
  </tr>
  
  <tr>
    <td bgcolor="#f8f9fa"><b>Resumen:</b></td>
    <td align="justify">
      Esta investigación aborda la problemática y lentitud de los métodos de identificación tradicionales de microplásticos, los cuales dependen enteramente de análisis manuales realizados por especialistas en laboratorio, haciéndolos propensos al error humano. Para mitigar esto, el autor desarrolla e implementa un sistema automatizado basado en <b>Redes Neuronales Convolucionales (CNN)</b> entrenadas para aprender de forma autónoma características visuales clave como la <b>forma, textura y color</b> de las partículas. El modelo abarca desde las etapas de adquisición y preprocesamiento de imágenes microscópicas hasta su evaluación con métricas de precisión, demostrando que la inteligencia artificial disminuye drásticamente los tiempos de análisis y eleva la confiabilidad del monitoreo ambiental acuático.
    </td>
  </tr>
  
  <tr>
    <td bgcolor="#eaecee"><b>Aporte a Yaku-Ñawi:</b></td>
    <td align="justify" bgcolor="#f4f6f7">
      <ul>
        <li><b>Sustento del Procesamiento Digital:</b> Valida directamente la viabilidad de utilizar Visión Computacional e Inteligencia Artificial para clasificar microplásticos en lugar de depender de lecturas subjetivas de un operario.</li>
        <li><b>Criterios de Programación:</b> Al demostrar que una red neuronal puede diferenciar contaminantes por su <i>forma, textura y color</i>, te da el fundamento de diseño para estructurar los algoritmos de filtrado de imagen dentro del microcontrolador <b>XIAO ESP32-S3</b>.</li>
        <li><b>Optimización de Tiempos:</b> Crear un dispositivo electrónico portátil capaz de agilizar el proceso de descarte de plásticos directamente <i>in situ</i> en el campo, inspirándose en las métricas de eficiencia computacional que propone la tesis.</li>
      </ul>
    </td>
  </tr>
</table>

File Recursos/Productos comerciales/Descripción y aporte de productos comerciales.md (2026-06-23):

# 🔬 TECNOLOGÍA EXISTENTE EN EL ÁMBITO COMERCIAL

<table width="100%">
  <!-- PRODUCTO 1: HORIBA -->
  <tr bgcolor="#2c3e50">
    <th colspan="2" align="center" style="color: white; padding: 10px;">
      <h3>1. LabRAM HR Evolution Raman Microscope — HORIBA Scientific</h3>
    </th>
  </tr>
  <tr>
    <td width="30%" align="center" bgcolor="#f8f9fa">
      <br>
      <!-- Asegúrate de subir la imagen a tu repositorio y referenciar la ruta correcta aquí -->
      Microscopio Raman LabRAM HR Evolution<br>
      <sub><b>Figura 1:</b> Microscopio Raman LabRAM HR Evolution para análisis ambiental.</sub>
    </td>
    <td>
      <table width="100%">
        <tr bgcolor="#f2f4f4"><th>Características Técnicas</th><th>Detalles del Dispositivo</th></tr>
        <tr><td><b>Técnica Analítica:</b></td><td>Espectroscopía Raman (Dispersión de luz láser)</td></tr>
        <tr><td><b>Fuente de Excitación:</b></td><td>Láser de múltiples longitudes de onda (405 nm, 532 nm, 633 nm y 785 nm)</td></tr>
        <tr><td><b>Automatización:</b></td><td>Mapeo químico automático y escaneo automatizado en 2D y 3D</td></tr>
        <tr><td><b>Software de Control:</b></td><td>LabSpec Raman Software (Clasificación con bibliotecas espectrales)</td></tr>
        <tr><td><b>Operación Estándar:</b></td><td>Laboratorio científico especializado de alto costo</td></tr>
      </table>
    </td>
  </tr>
  <tr>
    <td bgcolor="#eaecee"><b>Aporte y Justificación a Yaku-Ñawi:</b></td>
    <td bgcolor="#f4f6f7" align="justify">
      <ul>
        <li><b>Sustento del problema (Costo y Portabilidad):</b> Este equipo comercial demuestra que las alternativas actuales requieren laboratorios especializados y operativas complejas. Esto justifica la propuesta de valor de Yaku-Ñawi como una alternativa <b>portátil, directa y de bajo costo</b> para mediciones <i>in situ</i>.</li>
        <li><b>Validación de Fluorescencia:</b> El sistema de HORIBA usa láseres específicos para mitigar la interferencia por fluorescencia de ciertas muestras ambientales. Esto valida directamente nuestra integración de <b>LEDs de iluminación dual (UV-A y Blanco)</b> en Yaku-Ñawi para excitar los materiales de manera controlada y captar mejor las características ópticas mediante la cámara OV3660.</li>
      </ul>
    </td>
  </tr>

  <tr><td colspan="2" style="padding: 10px; border: none;"></td></tr>

  <tr bgcolor="#34495e">
    <th colspan="2" align="center" style="color: white; padding: 10px;">
      <h3>2. LUMOS II FT-IR Microscope — Bruker Corporation</h3>
    </th>
  </tr>
  <tr>
    <td width="30%" align="center" bgcolor="#f8f9fa">
      <br>
      Sistema FT-IR LUMOS II<br>
      <sub><b>Figura 2:</b> Sistema FT-IR LUMOS II para análisis de microplásticos.</sub>
    </td>
    <td>
      <table width="100%">
        <tr bgcolor="#f2f4f4"><th>Características Técnicas</th><th>Detalles del Dispositivo</th></tr>
        <tr><td><b>Técnica Analítica:</b></td><td>Micro-FTIR (Fourier Transform Infrared Spectroscopy)</td></tr>
        <tr><td><b>Fuente de Excitación:</b></td><td>Radiación infrarroja (IR) de absorción molecular</td></tr>
        <tr><td><b>Modos de Análisis:</b></td><td>ATR, transmisión y reflexión (Detectores FPA)</td></tr>
        <tr><td><b>Software de Control:</b></td><td>OPUS / Particle & Microplastics Analysis</td></tr>
        <tr><td><b>Rango de Detección:</b></td><td>Desde micrómetros hasta milímetros (Muestras de agua y sedimentos)</td></tr>
      </table>
    </td>
  </tr>
  <tr>
    <td bgcolor="#eaecee"><b>Aporte y Justificación a Yaku-Ñawi:</b></td>
    <td bgcolor="#f4f6f7" align="justify">
      <ul>
        <li><b>Clasificación de Polímeros:</b> El software de Bruker clasifica automáticamente plásticos como Polietileno (PE), PET y Poliestireno (PS). Esto establece el benchmark del problema comercial y justifica que el algoritmo cargado en nuestro microcontrolador <b>XIAO ESP32-S3</b> apunte a clasificar el mismo tipo de polímeros comunes en matrices de agua fluviales.</li>
        <li><b>Filosofía de Reconocimiento Automático:</b> El LUMOS II basa su eficiencia en la automatización del mapeo de partículas para eliminar el descarte manual lento. Yaku-Ñawi replica conceptualmente esta necesidad mediante visión artificial embebida, procesando la turbidez del agua y capturando imágenes para automatizar la alerta de contaminantes de forma rápida sin analistas de laboratorio.</li>
      </ul>
    </td>
  </tr>
</table>

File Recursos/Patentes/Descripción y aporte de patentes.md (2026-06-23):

# 🫆 DESCRIPCIÓN Y APORTE DE PATENTES
<p align="center">
  <a href="https://worldwide.espacenet.com/patent/search?q=pn%3DWO2024066118A1" target="_blank">
    
  </a>
  <a href="https://worldwide.espacenet.com/patent/search?q=pn%3DCN120334208A" target="_blank">
    
  </a>
  <a href="https://worldwide.espacenet.com/patent/search?q=pn%3DUS2024125677A1" target="_blank">
    
  </a>
  <a href="https://github.com/MRCDPLS/FdD_Equipo_07/blob/main/Recursos/Patentes/Patente%204-002302-2024DIN.pdf" target="_blank">
    
  </a>
</p>
<p align="center">
  Accede al documento técnico.
</p>

### 📄 PATENTE 1 (W02024066118A1): Detección mediante Fusión de Imágenes RGB y Hiperespectrales
<p align="justify">
-Resumen: Trata sobre un método de preprocesamiento, fusión de imágenes tradicionales (RGB) y espectros ópticos para detectar y segmentar de forma precisa partículas de microplásticos suspendidas en matrices sólidas o líquidas mediante IA.
</p>
<p align="justify">
-Aporte a Yaku-Ñawi: Justifica directamente el uso de la Cámara OV3660 combinada con los LEDs (UV-A y Blanco). Valida que para identificar plásticos no basta con una foto común, sino que la estimulación de iluminación dual (color y luz ultravioleta para fluorescencia) permite a un microcontrolador captar de mejor manera las texturas y formas de los contaminantes.
</p>

### 📄 PATENTE 2 (CN_120334208_A): Espectroscopía Raman de Doble Haz mediante Deposición por Burbujas
<p align="justify">
-Resumen: Propone un método para concentrar y detectar nano/microplásticos en muestras de agua líquida aprovechando un efecto fototérmico guiado por láser que genera burbujas capilares para capturar las partículas suspendidas.
</p>
<p align="justify">
-Aporte a Yaku-Ñawi: Te sirve como sustento de antecedentes del problema. Demuestra que las tecnologías tradicionales de laboratorio (como la espectroscopía Raman) son sumamente complejas y costosas, lo cual le da un valor increíble al enfoque de Yaku-Ñawi, que busca un análisis in situ, portátil y de bajo costo utilizando mediciones directas (turbidez y conductividad/TDS) en campo.
</p>

### 📄 PATENTE 3 (US_2024/0125677_A1): Sistema electrónico de detección de tamaño de partícula chica
<p align="justify">
-Resumen: Describe un dispositivo electrónico y un medio de escaneo que optimiza el tiempo de exposición de los sensores y cámaras para calcular con alta precisión el ratio de microplásticos pequeños (como PP y PET) directamente en muestras de agua fluviales.
</p>
<p align="justify">
-Aporte a Yaku-Ñawi: Es el núcleo para el diseño algorítmico y matemático en tu ESP32-S3. Esta patente fundamenta la necesidad de controlar de forma digital (mediante los GPIOs) los tiempos de captura de la cámara y el procesamiento de señales analógicas simultáneas para evitar falsos positivos al medir plásticos pequeños.
</p>

### 📄 PATENTE 4 (002302-2024/DIN - Indecopi Perú): Equipo electrónico portátil para detección de microplásticos en agua
<p align="justify">
-Resumen: Esta es una patente nacional de modelo de utilidad para un equipo portátil (con dimensiones específicas de ~11.5 cm y peso menor a 3 kg) diseñado para realizar análisis in situ de contaminación fluvial, guardando los datos en un sistema y enviándolos a través de conexiones inalámbricas. Cuenta con filtros ópticos y una pantalla LCD para interactuar.
</p>
<p align="justify">
-Aporte a Yaku-Ñawi: Valida el empaquetado físico y arquitectónico de tu prototipo. Soporta técnicamente tu decisión de integrar una Pantalla LCD I2C para la interfaz del usuario y el uso de conectividad inalámbrica (aprovechando que el XIAO ESP32-S3 tiene Wi-Fi/Bluetooth de forma nativa) para transmitir los datos del sensor de turbidez y TDS.
</p>

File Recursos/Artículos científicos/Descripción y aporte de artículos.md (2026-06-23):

# ARTÍCULOS CIENTÍFICOS DE REFERENCIA

<p align="center">
  <a href="https://doi.org/10.1126/sciadv.1700782" target="_blank">
    
  </a>
  <a href="https://doi.org/10.1007/s10311-023-01593-3" target="_blank">
    
  </a>
  <a href="https://doi.org/10.1016/j.trac.2018.10.020" target="_blank">
    
  </a>
  <a href="https://doi.org/10.1016/j.jhazmat.2024.134865" target="_blank">
    
  </a>
  <a href="https://doi.org/10.1016/j.envres.2022.113569" target="_blank">
    
  </a>
  <a href="https://doi.org/10.15381/rpb.v24i1.12724" target="_blank">
    
  </a>
</p>
Contribución de los Artículos Científicos al Proyecto

### Artículo 1 — Panorama global de la contaminación plástica

**Geyer R, Jambeck JR, Law KL.** *Production, use, and fate of all plastics ever made*. Science Advances. 2017.

Este artículo proporcionó una visión crítica sobre la producción, uso y destino de todos los plásticos fabricados a nivel mundial. Sus resultados permitieron comprender la magnitud del problema de la contaminación plástica y sirvieron como base para definir qué tipos de microplásticos serían más relevantes para la detección y análisis en nuestro proyecto.

---

### Artículo 2 — Fuentes, toxicidad y remediación de microplásticos

**Osman AI, Hosny M, Eltaweil AS, Omar S, Elgarahy AM, Farghali M, et al.** *Microplastic sources, formation, toxicity and remediation: a review*. Environmental Chemistry Letters. 2023.

Este artículo de revisión permitió comprender las principales fuentes de generación de microplásticos, su presencia en distintos ecosistemas y los riesgos asociados a la exposición humana. Además, proporcionó información sobre métodos de remediación y estrategias de control que ayudaron a contextualizar la importancia ambiental y sanitaria de nuestro proyecto.

---

###  Artículo 3 — Métodos de cuantificación de microplásticos

**Rios Mendoza LM, Balcer M.** *Microplastics in freshwater environments: A review of quantification assessment*. Trends in Analytical Chemistry. 2019.

Esta investigación fue utilizada para analizar diferentes métodos de cuantificación e identificación de microplásticos en muestras ambientales. Sus aportes sirvieron como referencia para evaluar la posible incorporación de técnicas de espectrometría y fluorescencia como complemento a futuras versiones del sistema de detección.

---

###  Artículo 4 — Inteligencia artificial aplicada a microplásticos

**Hu B, et al.** *Using artificial intelligence to rapidly identify microplastics pollution and predict microplastics environmental behaviors*. Journal of Hazardous Materials. 2024.

Este artículo influyó directamente en una de las decisiones tecnológicas más importantes del proyecto: la implementación de inteligencia artificial para la identificación de microplásticos. Sus resultados respaldaron el uso de modelos de visión artificial basados en YOLO para realizar detecciones rápidas y automatizadas en nuestro dispositivo.

---

### Artículo 5 — Machine Learning para identificación avanzada

**Tian X, Beén F, Bäuerlein PS.** *Quantum cascade laser imaging (LDIR) and machine learning for the identification of environmentally exposed microplastics and polymers*. Environmental Research. 2022.

Este estudio presentó un enfoque innovador para la identificación de microplásticos degradados mediante técnicas avanzadas de imagen y aprendizaje automático. Sus hallazgos aportaron una perspectiva valiosa para mejorar la precisión de los sistemas de detección utilizados en nuestro prototipo.

---

### Artículo 6 — Microplásticos en playas del Perú

**Purca S, Henostroza A.** *Presencia de microplásticos en cuatro playas arenosas de Perú*. Revista Peruana de Biología. 2017.

Este artículo permitió conocer la distribución de microplásticos en playas peruanas y proporcionó información útil para seleccionar posibles zonas de muestreo durante las pruebas de campo. Además, servirá como referencia para futuras implementaciones comerciales del sistema en ambientes costeros del país.

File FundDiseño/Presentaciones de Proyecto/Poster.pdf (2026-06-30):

Frente a esta problemática, Yaku-Ñawi propone un sistema portátil basado en inteligencia artificial, visión computacional y fluorescencia UV-A para detectar microplásticos de forma rápida, accesible y automatizada.

# Funcionamiento

# Yaku-Ñawi Sistema inteligente de detección de microplásticos PET y EPS

Alarcón M., Cerdan R., Evangelista B., Fernández Y., Quispe M. Universidad Peruana Cayetano Heredia, Facultad de Ciencias e Ingeniería, Fundamentos | de Diseño 2026-1
OBJETIVO | CONCLUSIÓN

# INTRODUCCIÓN

De las muestras analizadas en playas peruanas presentaron microplásticos.[1]

Entre los polímeros más
frecuentes se encuentran
el PET y el EPS.[2]

Pueden ser ingeridos por
organismos acuáticos,
afectando el equilibrio de los ecosistemas.[3]

La contaminación por microplásticos representa una amenaza para los ecosistemas acuáticos y la salud humana. En playas y humedales de Lima, polímeros como PET y EPS se fragmentan en partículas difíciles de detectar mediante métodos convencionales.

Diseñar un dispositivo portátil capaz de detectar microplásticos tipo EPS y PET en muestras de agua mediante análisis automatizado de imágenes y técnicas de inteligencia artificial.

2 1 | 3D con los materiales | METODOLOGÍA

## REFERENCIAS BIBLIOGRÁFICAS

El sistema se compone de sensores, iluminación controlada, captura de imágenes y procesamiento con inteligencia artificial para detectar microplásticos PET y EPS.

# RESULTADOS

[1 ]Purca S, Henostroza A. Presencia de microplásticos en cuatro playas arenosas de Perú. Rev Peru Biol. 2017;24(1):101-106. doi:10.15381/rpb.v24i1.12724. [2]De-la-Torre GE, Dioses-Salinas DC, Castro JM, Antay R, Yupanqui Fernández N, Espinoza-Morriberón D, et al. Abundance and distribution of microplastics on sandy beaches of Lima, Peru. Mar Pollut Bull. 2020;151:110877. doi:10.1016/j.marpolbul.2019.110877. Disponible en: https://doi.org/10.1016/j.marpolbul.2019.110877
[3]UNEP. Microplastics: A global overview. Nairobi: United Nations Environment Programme; 2016. Disponible en: https://wedocs.unep.org/handle/20.500.11822/12079

Yaku-Ñawi propone una solución innovadora para la identificación preliminar de microplásticos PET y EPS mediante la integración de iluminación UV-A, procesamiento digital de imágenes y visión por computador. El sistema busca fortalecer el monitoreo de la contaminación en cuerpos de agua mediante una alternativa portátil, automatizada y de apoyo a la investigación ambiental.

FOTOS DE LA CÁMARA 1 PÁGINA WEB | 2
PET con luz UVA | EPS con luz UVA

## 3 PARÁMETROS

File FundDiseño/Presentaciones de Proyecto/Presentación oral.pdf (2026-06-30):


# Yaku-Ñawi

## SISTEMA INTELIGENTE DE DETECCIÓN DE MICROPLÁSTICOS PET Y PP

# PROBLEMÁTICA

# La acumulación de microplásticos en cuerpos de agua amenaza los

ecosistemas acuáticos y la salud humana.

millones | 40 %

# De los residuos plásticos no recibe una gestión adecuada

## De toneladas de plástico se liberan al ambiente cada año

80 %

# Más del

# de las muestras en playas peruanas contienen microplásticos

52

residuos-noticia/#google_vignette

https://gestion.pe/mundo/cada-ano-se-liberan-mas-de-52-millones-de-toneladas-de-plasticos-al-medioambiente-desechos-reino-unido-basura-

Geyer R, Jambeck JR, Law KL. Production, use, and fate of all plastics ever made. Sci Adv. 2017;3(7):e1700782. doi:10.1126/sciadv.1700782 https://observatorio.ceplan.gob.pe/ficha/t53

# TECNOLOGÍA EXISTENTE


# ANÁLISIS DE PATENTES EXISTENTES

# ANÁLISIS DE PATENTES EXISTENTES

# INVESTIGACIÓN ACADÉMICA


# TESIS DE REPOSITORIOS


# Identificación automática de microplásticos

SOLUCIÓN; sintéticos

Mediante análisis de imágenes en playas y
humedales.

Clasificación de polímeros

Sistema portátil basado en
inteligencia artificial que detecta y
clasifica microplásticos de tipo EPS y
PET mediante imágenes en playas y

Diferenciación de materiales como PET y
EPS

humedales de Lima.

Monitoreo de la
contaminación ambiental

Generación de datos para evaluar la calidad
ambiental.

# PROPUESTA DE VALOR

Resultado rapido; Facilidadde transporte; Reduce costos; Monitoreo ambiental; Detección automática con inteligencia artificial

Yaku-Ñawi: tecnología que cuida nuestros ecosistemas

# LISTA DE EXIGENCIAS
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

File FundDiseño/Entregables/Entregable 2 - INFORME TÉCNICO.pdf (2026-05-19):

# UNIVERSIDAD PERUANA CAYETANO HEREDIA

## GRUPO: 7

## COORDINADOR:

### Mg. Mugaburu Celi, Marco Antonio

## JEFES DE PRÁCTICA:

### Mg. Chan Ríos, Renzo Jose Dr. Rivera Tito, Harry Anderson Ing. Venancio Huerta, Julissa Elvira

## INTEGRANTES:

### Alarcón Camones, Marcelo Valentino Cerdan Dongo, Rebeca Milagros Evangelista Noreña, Bruno Felix Fernández Rimarachín, Yakori Siclali Quispe García, Mariluz
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

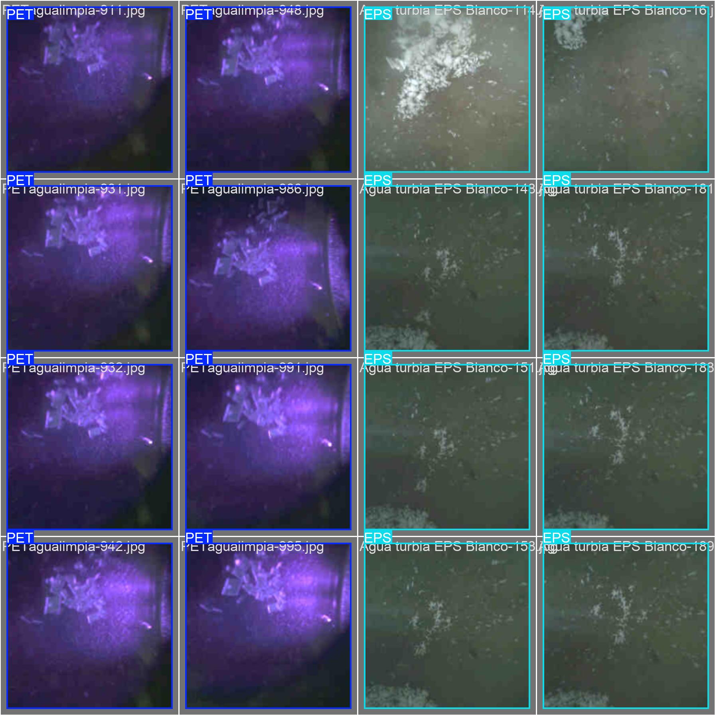
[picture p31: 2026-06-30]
Proyecto/MóduloSoftware/val_batch1_labels.jpg

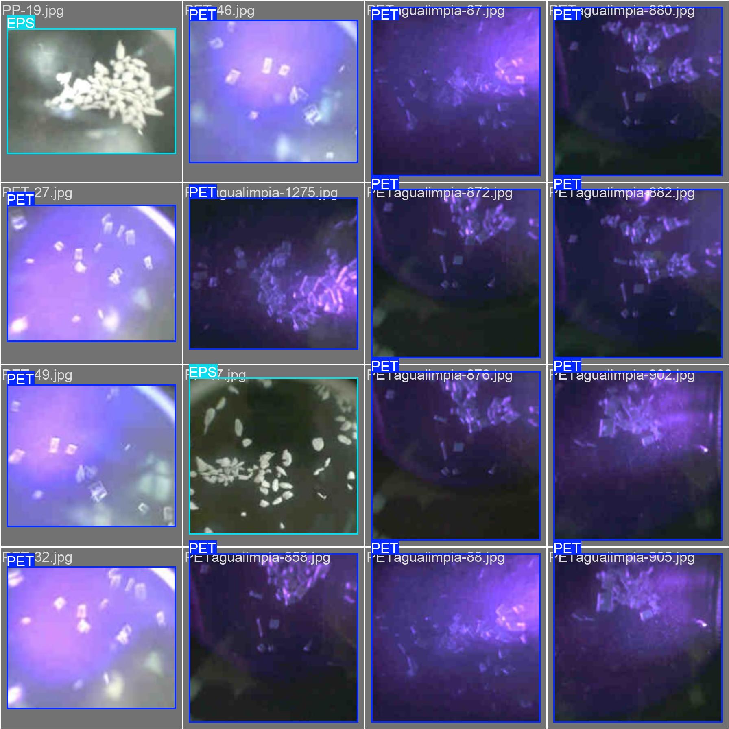
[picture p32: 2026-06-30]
Proyecto/MóduloSoftware/val_batch0_labels.jpg

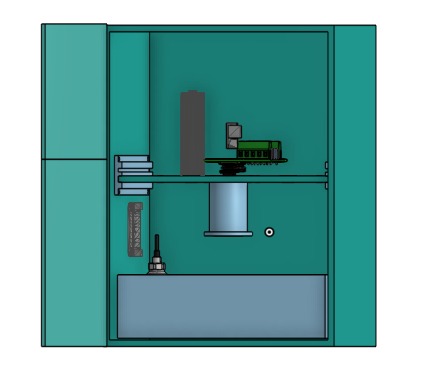
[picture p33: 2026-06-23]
Recursos/Imágenes/versión 1..jpeg

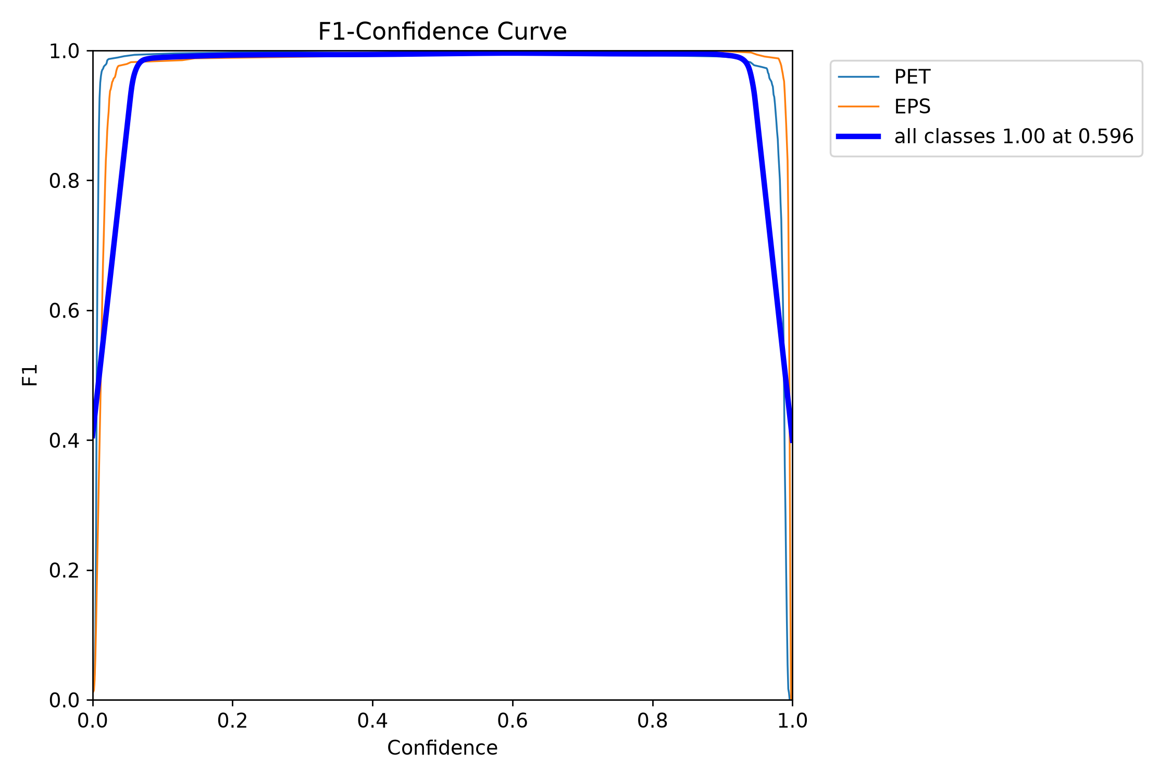
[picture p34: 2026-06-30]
Proyecto/MóduloSoftware/BoxF1_curve.png

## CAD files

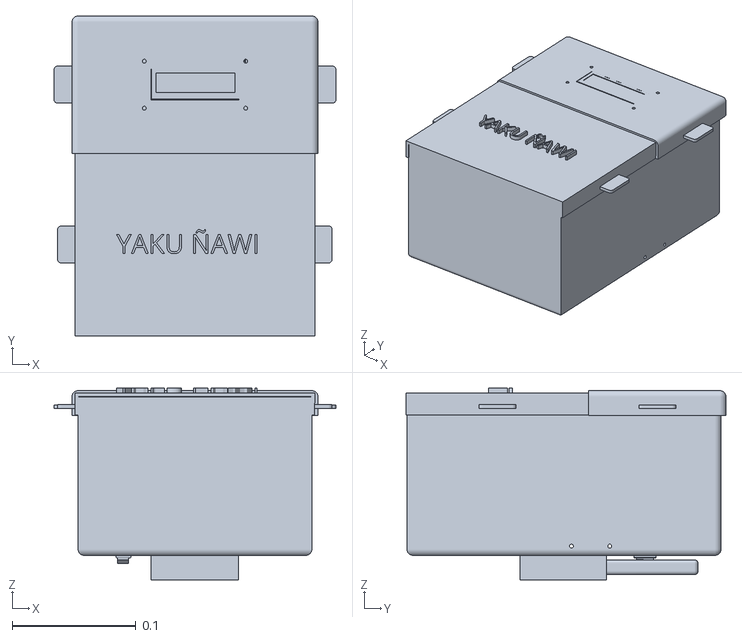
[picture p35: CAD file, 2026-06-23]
Proyecto/MóduloMecánico/V3.0/Onshape/Ensamble/V3_YAKU _ÑAWI.stl
0.228 x 0.259 x 0.155

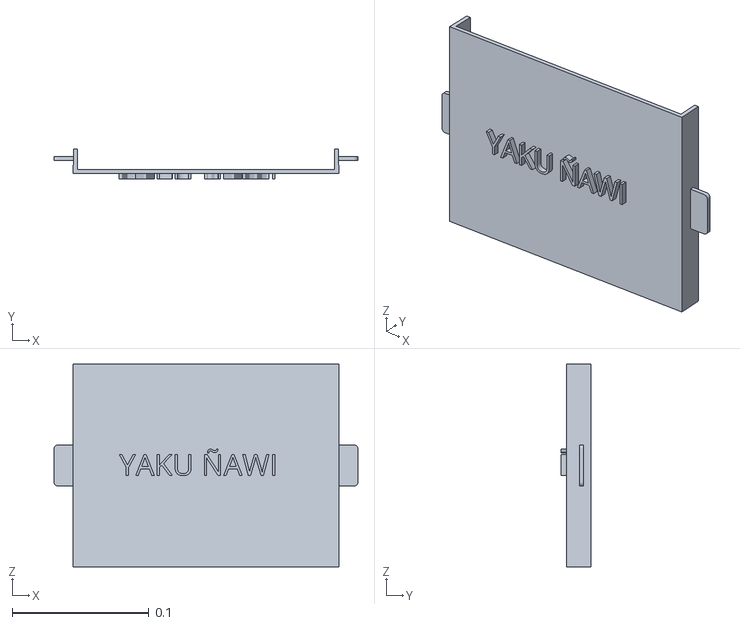
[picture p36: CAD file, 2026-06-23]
Proyecto/MóduloMecánico/V3.0/Onshape/Partes/V3_Puerta Inferior.stl
0.222 x 0.022 x 0.148

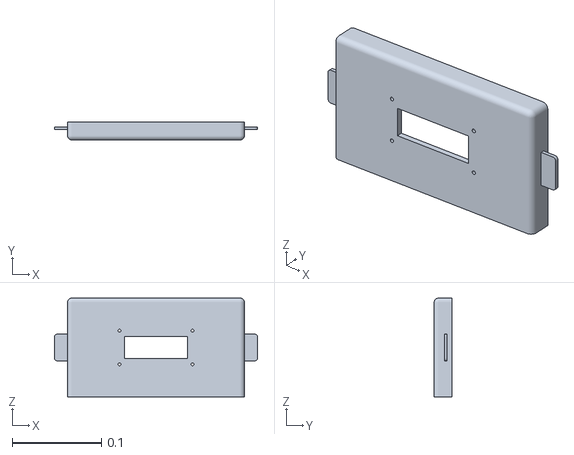
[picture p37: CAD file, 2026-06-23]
Proyecto/MóduloMecánico/V3.0/Onshape/Partes/V3_Puerta superior.stl
0.228 x 0.02 x 0.111

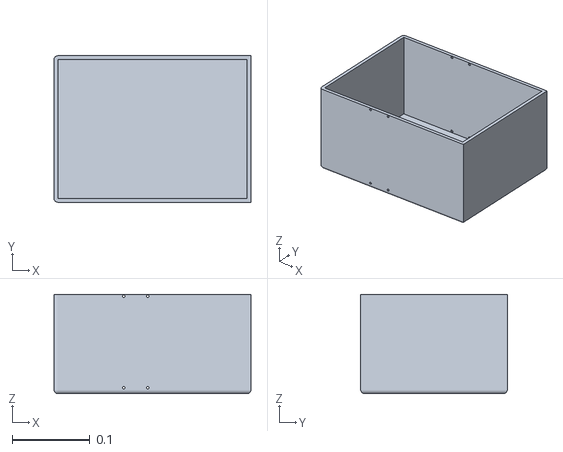
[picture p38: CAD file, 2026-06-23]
Proyecto/MóduloMecánico/V3.0/Onshape/Partes/V3_Caja.stl
0.254 x 0.189 x 0.128

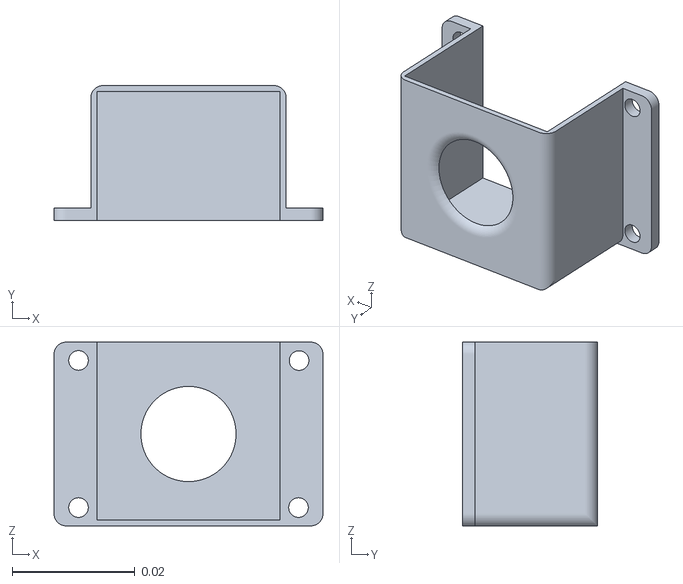
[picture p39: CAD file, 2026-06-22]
Proyecto/MóduloMecánico/V3.0/Onshape/Partes/V3_Cubierta camara.stl
0.0439 x 0.022 x 0.03

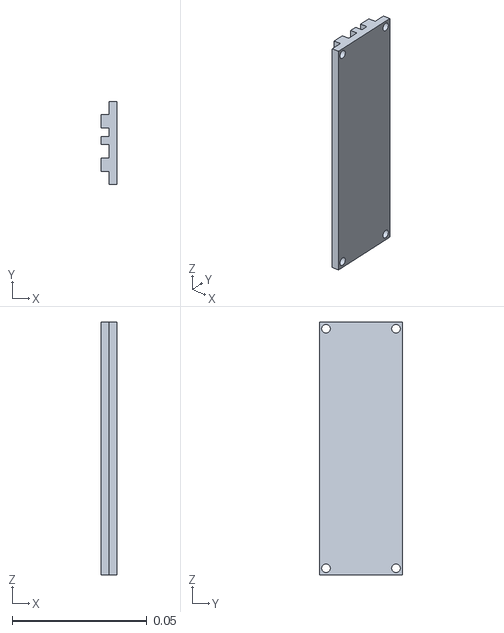
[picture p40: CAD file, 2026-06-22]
Proyecto/MóduloMecánico/V3.0/Onshape/Partes/V3_Soporte de placa.stl
0.006 x 0.031 x 0.094

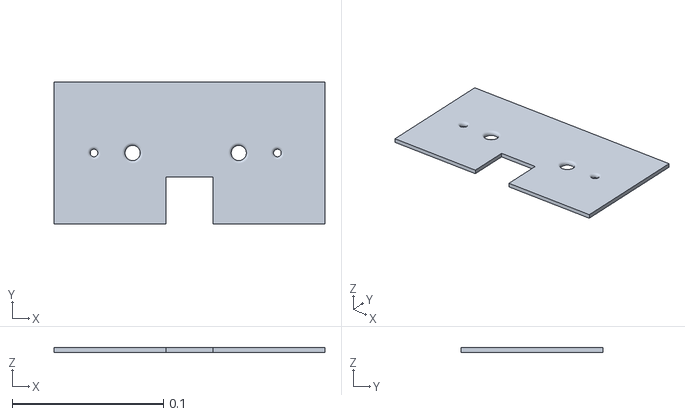
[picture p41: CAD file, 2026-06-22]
Proyecto/MóduloMecánico/V3.0/Onshape/Partes/V3_Placa 1.stl
0.179 x 0.094 x 0.003

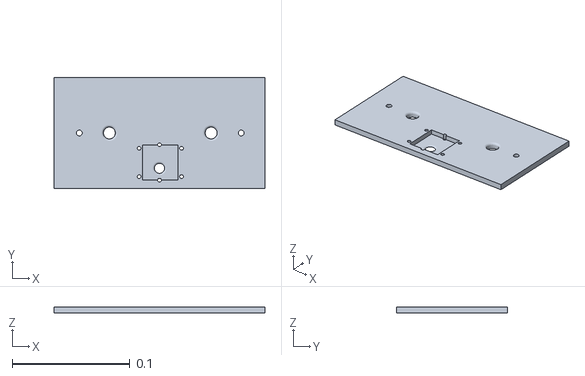
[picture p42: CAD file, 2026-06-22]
Proyecto/MóduloMecánico/V3.0/Onshape/Partes/V3_Placa 2.stl
0.179 x 0.094 x 0.005

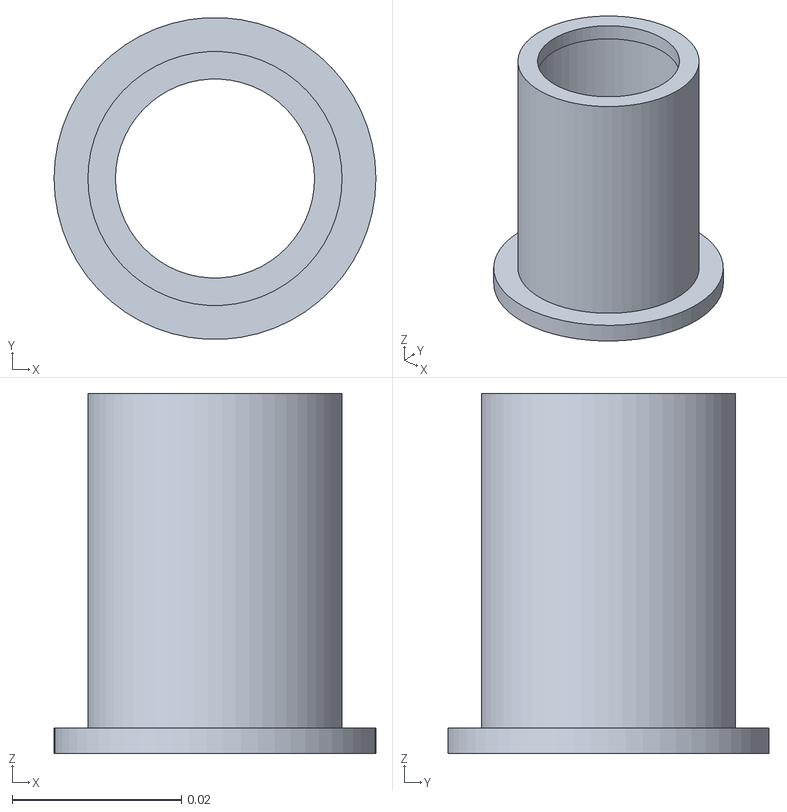
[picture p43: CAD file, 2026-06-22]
Proyecto/MóduloMecánico/V3.0/Onshape/Partes/V3_Soporte de lente.stl
0.038 x 0.0379 x 0.0425

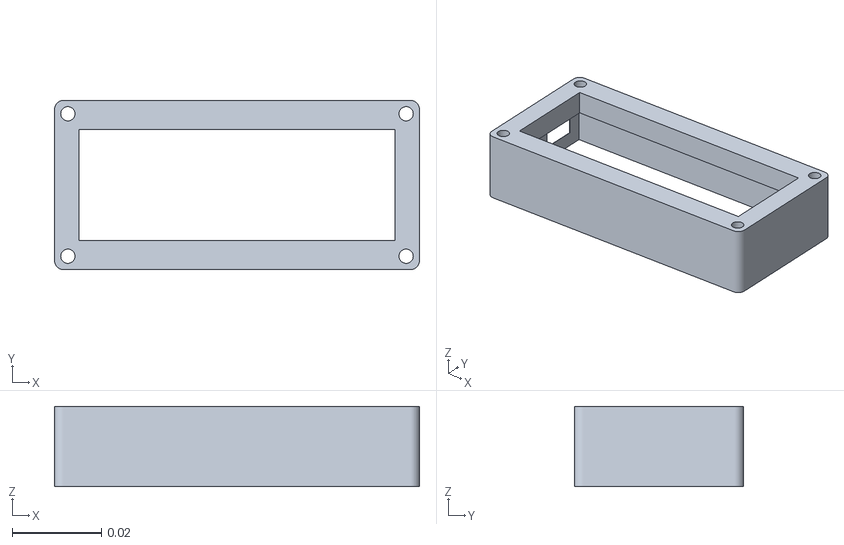
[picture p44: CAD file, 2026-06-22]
Proyecto/MóduloMecánico/V3.0/Onshape/Partes/V3_cubierta de pantalla led.stl
0.082 x 0.038 x 0.018

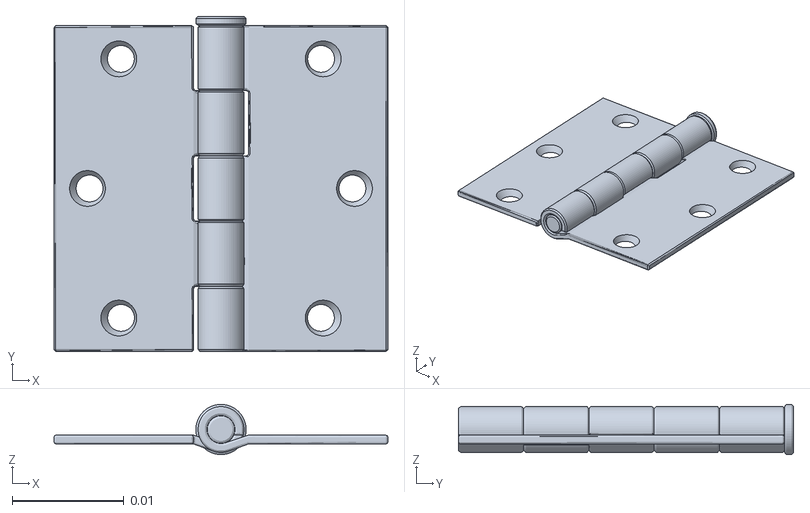
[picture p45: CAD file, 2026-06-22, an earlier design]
Proyecto/MóduloMecánico/V1.0/Onshape/Partes/V1_Bisagra.stl
0.0299 x 0.03 x 0.0045

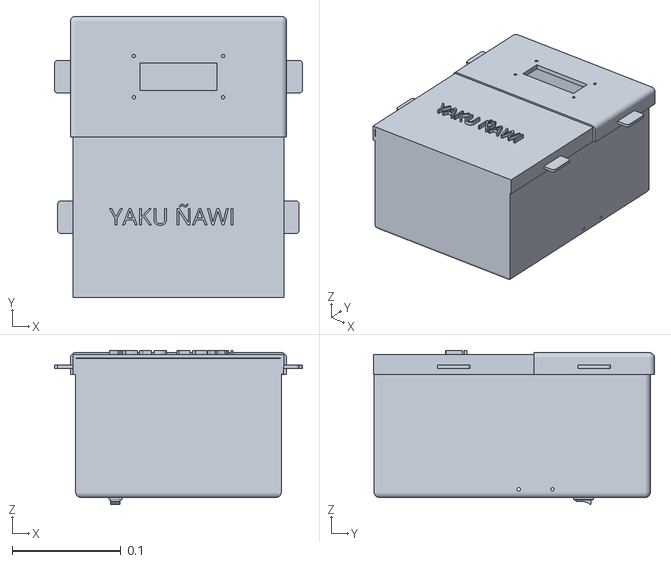
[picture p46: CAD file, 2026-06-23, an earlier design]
Proyecto/MóduloMecánico/V2.0/Onshape/Ensamble/V2_YAKY_ÑAWI.stl
0.228 x 0.259 x 0.142

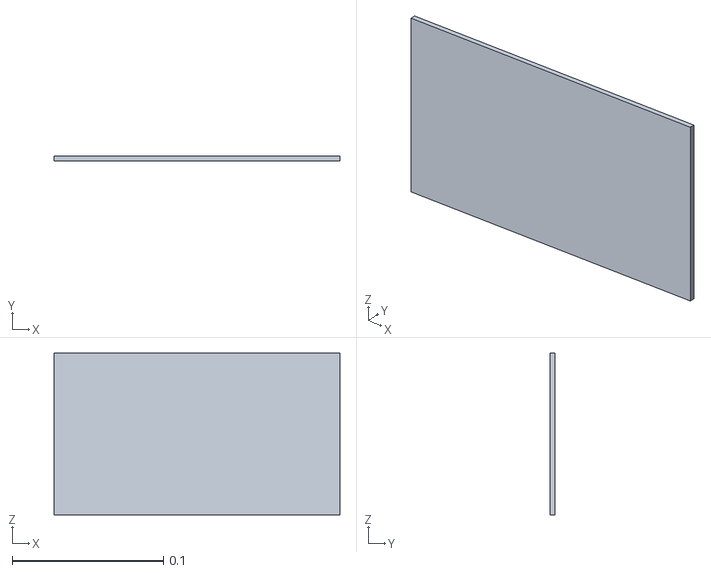
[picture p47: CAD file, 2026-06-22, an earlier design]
Proyecto/MóduloMecánico/V1.0/Onshape/Partes/V1_Puerta superior.stl
0.189 x 0.003 x 0.107

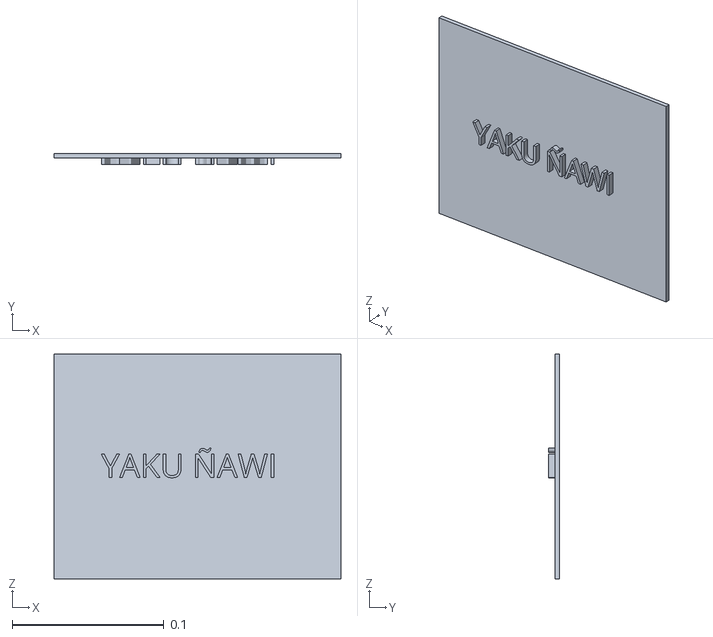
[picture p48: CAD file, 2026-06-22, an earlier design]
Proyecto/MóduloMecánico/V1.0/Onshape/Partes/V1_Puerta Inferior.stl
0.189 x 0.007 x 0.148

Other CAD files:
Proyecto/MóduloMecánico/V1.0/Onshape/Partes/V1_CAJA.stl
Proyecto/MóduloMecánico/V2.0/Onshape/Partes/V2_Soporte para power bank.stl

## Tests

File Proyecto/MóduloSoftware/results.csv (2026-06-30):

epoch | time | train/box_loss | train/cls_loss | train/dfl_loss | metrics/precision(B) | metrics/recall(B) | metrics/mAP50(B) | metrics/mAP50-95(B) | val/box_loss | val/cls_loss | val/dfl_loss | lr/pg0 | lr/pg1 | lr/pg2
1 | 694.759 | 0.22716 | 1.13253 | 0.95993 | 0.69766 | 0.7829 | 0.83857 | 0.80949 | 0.24534 | 1.61467 | 0.27344 | 0.000554246 | 0.000554246 | 0.000554246
2 | 1375.77 | 0.16468 | 0.56265 | 0.91357 | 0.91597 | 0.93853 | 0.98362 | 0.97747 | 0.20448 | 0.58987 | 0.21135 | 0.000743641 | 0.000743641 | 0.000743641
3 | 2019.67 | 0.12254 | 0.41939 | 0.90434 | 0.99476 | 0.99779 | 0.995 | 0.995 | 0.13322 | 0.2984 | 0.16552 | 0.000566297 | 0.000566297 | 0.000566297

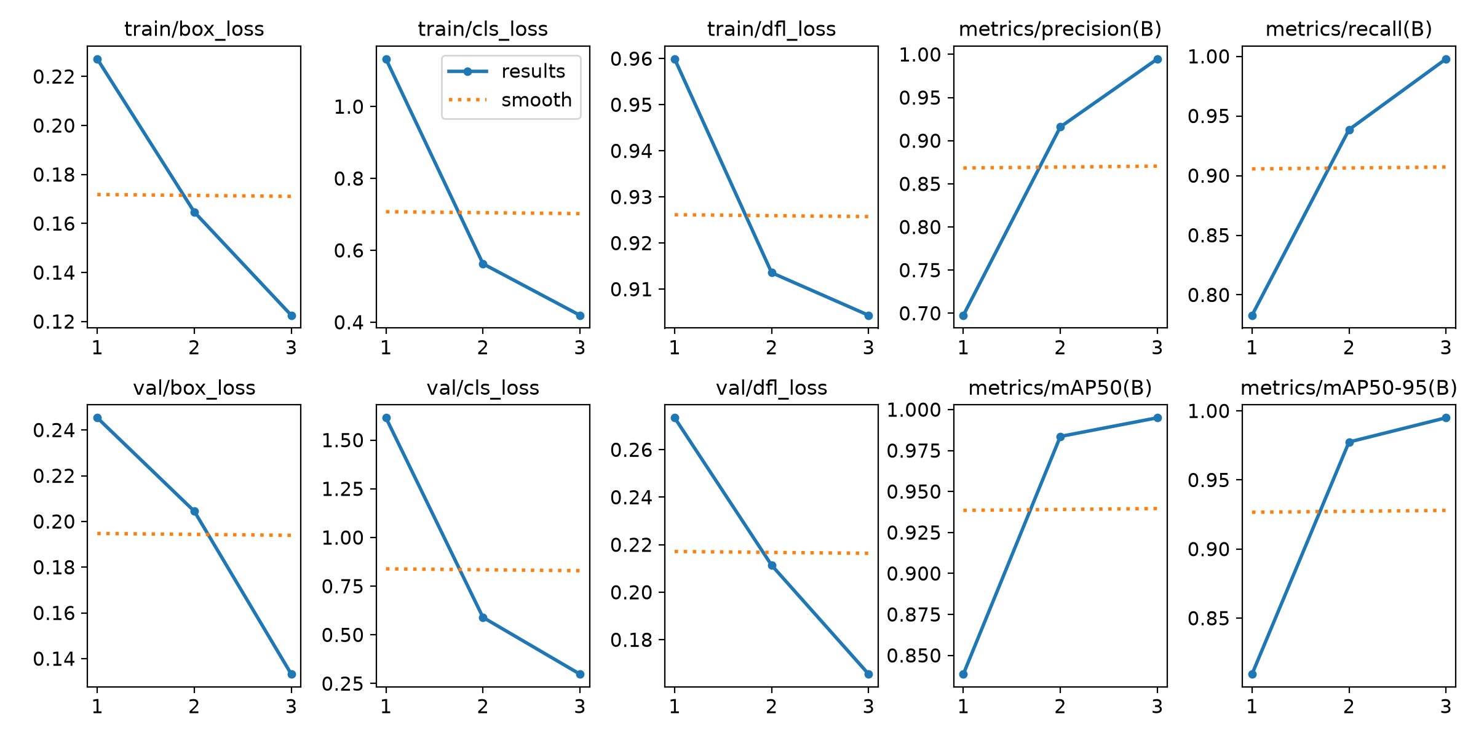
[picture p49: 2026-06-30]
Proyecto/MóduloSoftware/results.png

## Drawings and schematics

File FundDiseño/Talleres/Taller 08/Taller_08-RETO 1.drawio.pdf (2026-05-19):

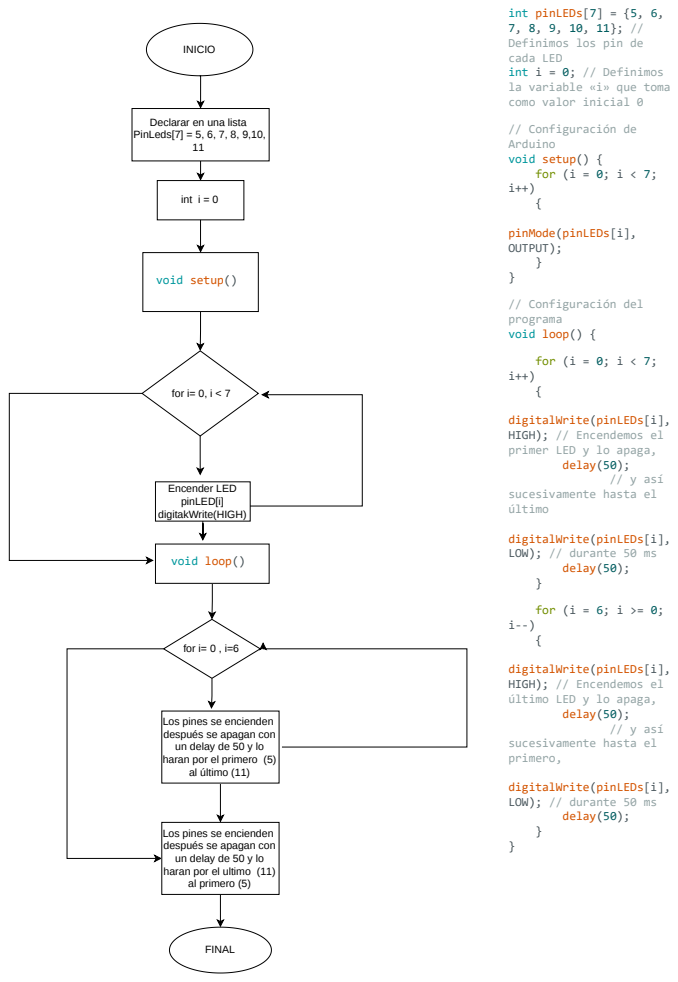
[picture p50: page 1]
; // Definimos; // Configuración de Arduino void setup(); for; pinMode; (pinLEDs[i],; OUTPUT; // Configuración del programa void loop(); ; // Encendemos; delay; ; // y así; digitalWrite; LOW; ; // durante 50 ms delay; ; // Encendemos el; for i= 0, i < 7; for i= 0 , i=6; void; loop(); INICIO; setup(); FINAL; int i = 0; Encender LED pinLED[i] digitakWrite(HIGH)

int pinLEDs
Definimos los pin de
cada LED
int i =
la variable «i» que toma
como valor inicial 0

Declarar en una lista
PinLeds[7] = 5, 6, 7, 8, 9,10,

digitalWrite
HIGH
primer LED y lo apaga,

sucesivamente hasta el
último

último LED y lo apaga,

Los pines se encienden
después se apagan con
un delay de 50 y lo
haran por el primero (5)
al último (11)

primero,

haran por el ultimo (11)
al primero (5)

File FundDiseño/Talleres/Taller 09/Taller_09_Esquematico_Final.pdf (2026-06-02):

### MOSI

### MISO

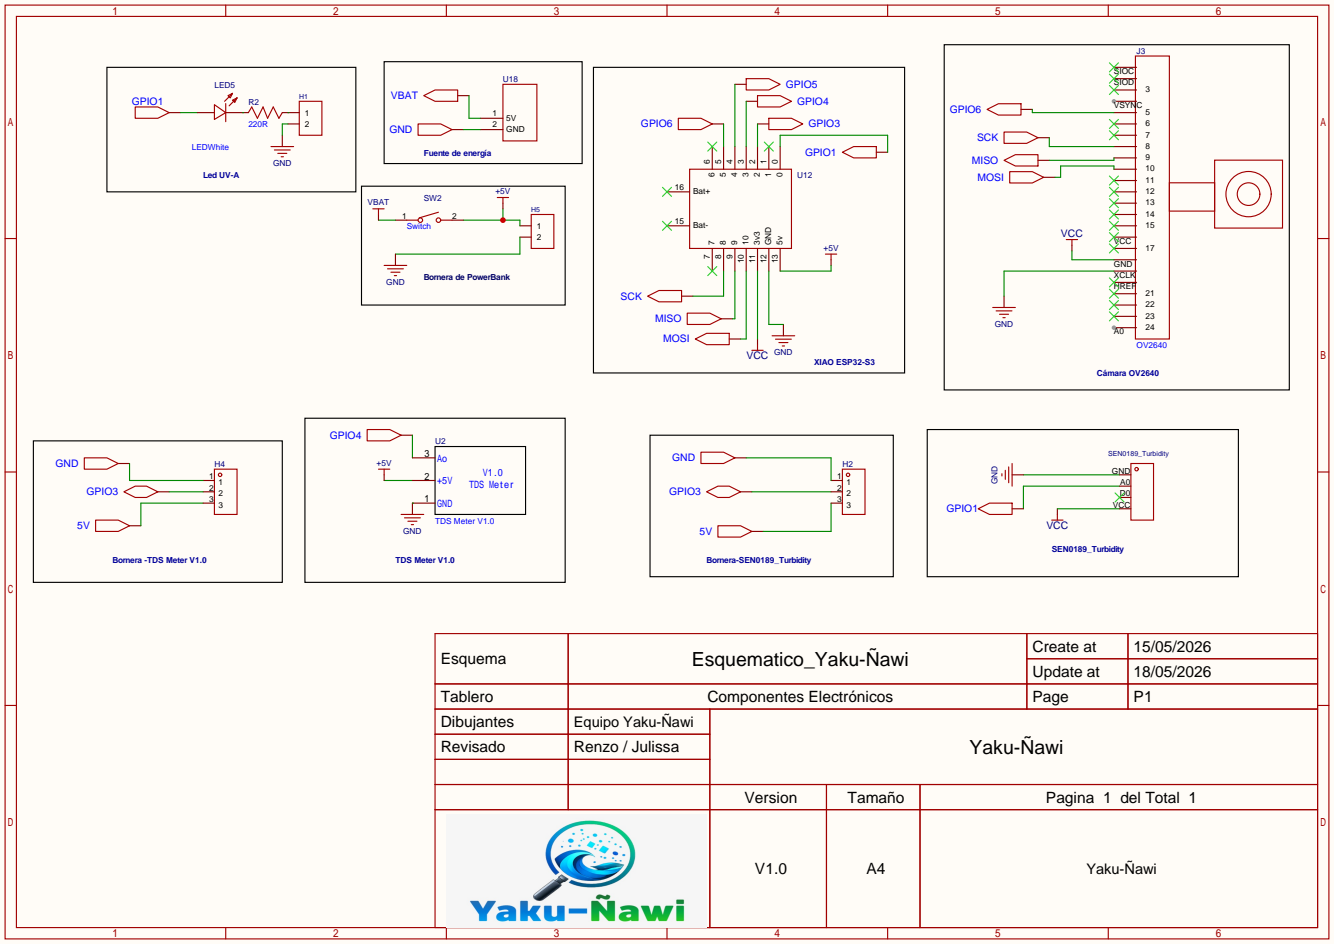
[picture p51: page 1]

Esquema | Esquematico_Yaku-Ñawi | Create at | 15/05/2026

Update at | 18/05/2026

Tablero | Componentes Electrónicos | Page | P1
Dibujantes | Equipo Yaku-Ñawi | Yaku-Ñawi
Revisado | Renzo / Julissa

Version | Tamaño | Pagina 1 del Total 1

V1.0 | A4 | Yaku-Ñawi

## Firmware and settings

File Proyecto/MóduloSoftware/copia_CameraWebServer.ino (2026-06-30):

#include <Arduino.h>
#include "esp_camera.h"
#include <WiFi.h>
#include <HTTPClient.h>
#include <Wire.h>
#include <LiquidCrystal_I2C.h>

// ===========================
// Select camera model in board_config.h
// ===========================
#include "board_config.h"

// ===========================
// Enter your WiFi credentials
// ===========================
const char *ssid = "Redmi 13C";
const char *password = "12345678";
const char *FLASK_URL_FRAME    = "http://10.108.103.206:5000/frame";
const char *FLASK_URL_SENSORES = "http://10.108.103.206:5000/sensores";

//=========================
// MODO DE PRUEBA
// Pon en 1 para probar rapido (ciclo de LED de 5 s),
// pon en 0 para el funcionamiento real (ciclo de 2 min).
//=========================
#define MODO_PRUEBA 1

#if MODO_PRUEBA
  const unsigned long TIEMPO_LED = 5000;   // 5 segundos (PRUEBA)
#else
  const unsigned long TIEMPO_LED = 120000; // 2 minutos (REAL)
#endif

//=========================
// Si quieres ademas levantar el servidor de streaming
// nativo del ESP32 (ademas de mandar frames a Flask), pon esto en 1.
// Para tu objetivo actual (comprobar LCD/LEDs/sensores en la web Flask)
// puedes dejarlo en 0.
//=========================
#define USAR_SERVIDOR_NATIVO 0

//=========================
// LCD
//=========================
LiquidCrystal_I2C lcd(0x27, 16, 2);

// Pines I2C reales del XIAO ESP32S3 (D4=SDA=GPIO5, D5=SCL=GPIO6)
const int PIN_SDA = D4;
const int PIN_SCL = D5;

//=========================
// LEDs
//=========================
const int ledBlanco = D0;
const int ledUV = D1;

//=========================
// Sensores
//=========================
const int turbidezPin = A2;
const int conductividadPin = A3;

//=========================
// Variables de tiempo
//=========================
unsigned long inicioCiclo = 0;
unsigned long ultimaLectura = 0;
unsigned long ultimoFrame = 0;

const unsigned long INTERVALO_SENSOR = 1000;  // 1 segundo
const unsigned long INTERVALO_FRAME = 200;    // 5 FPS

// Ultimas lecturas (para reusar en el envio a Flask)
int ultimoTurbidez = 0;
int ultimaConductividad = 0;

#if USAR_SERVIDOR_NATIVO
void startCameraServer();
void setupLedFlash();
#endif

void setup() {

  Serial.begin(115200);
  delay(3000);

  pinMode(ledBlanco, OUTPUT);
  pinMode(ledUV, OUTPUT);
  pinMode(turbidezPin, INPUT);
  pinMode(conductividadPin, INPUT);

  digitalWrite(ledBlanco, LOW);
  digitalWrite(ledUV, LOW);

  Wire.begin(PIN_SDA, PIN_SCL);
  lcd.init();
  lcd.backlight();

  lcd.setCursor(0, 0);
  lcd.print("Sistema listo");
  delay(2000);

  lcd.clear();
  lcd.setCursor(0, 0);
  lcd.print("Inicia");
  lcd.setCursor(0, 1);
  lcd.print("el proceso...");
  delay(3000);

  lcd.clear();

  inicioCiclo = millis();

  Serial.println("================================");
  Serial.println("INICIO");
  Serial.printf("Modo: %s | Ciclo LED: %lu ms\n", MODO_PRUEBA ? "PRUEBA" : "REAL", TIEMPO_LED);
  Serial.println("================================");

  camera_config_t config;
  config.ledc_channel = LEDC_CHANNEL_0;
  config.ledc_timer = LEDC_TIMER_0;
  config.pin_d0 = Y2_GPIO_NUM;
  config.pin_d1 = Y3_GPIO_NUM;
  config.pin_d2 = Y4_GPIO_NUM;
  config.pin_d3 = Y5_GPIO_NUM;
  config.pin_d4 = Y6_GPIO_NUM;
  config.pin_d5 = Y7_GPIO_NUM;
  config.pin_d6 = Y8_GPIO_NUM;
  config.pin_d7 = Y9_GPIO_NUM;
  config.pin_xclk = XCLK_GPIO_NUM;
  config.pin_pclk = PCLK_GPIO_NUM;
  config.pin_vsync = VSYNC_GPIO_NUM;
  config.pin_href = HREF_GPIO_NUM;
  config.pin_sccb_sda = SIOD_GPIO_NUM;
  config.pin_sccb_scl = SIOC_GPIO_NUM;
  config.pin_pwdn = PWDN_GPIO_NUM;
  config.pin_reset = RESET_GPIO_NUM;
  config.xclk_freq_hz = 20000000;
  config.frame_size = FRAMESIZE_UXGA;
  config.pixel_format = PIXFORMAT_JPEG;
  config.grab_mode = CAMERA_GRAB_WHEN_EMPTY;
  config.fb_location = CAMERA_FB_IN_PSRAM;
  config.jpeg_quality = 12;
  config.fb_count = 1;

  if (config.pixel_format == PIXFORMAT_JPEG) {
    if (psramFound()) {
      config.jpeg_quality = 10;
      config.fb_count = 2;
      config.grab_mode = CAMERA_GRAB_LATEST;
    } else {
      config.frame_size = FRAMESIZE_SVGA;
      config.fb_location = CAMERA_FB_IN_DRAM;
    }
  } else {
    config.frame_size = FRAMESIZE_240X240;
#if CONFIG_IDF_TARGET_ESP32S3
    config.fb_count = 2;
#endif
  }

#if defined(CAMERA_MODEL_ESP_EYE)
  pinMode(13, INPUT_PULLUP);
  pinMode(14, INPUT_PULLUP);
#endif

  esp_err_t err = esp_camera_init(&config);
  if (err != ESP_OK) {
    Serial.printf("Camera init failed with error 0x%x", err);
    return;
  }

  sensor_t *s = esp_camera_sensor_get();
  if (s->id.PID == OV3660_PID) {
    s->set_vflip(s, 1);
    s->set_brightness(s, 1);
    s->set_saturation(s, -2);
  }
  if (config.pixel_format == PIXFORMAT_JPEG) {
    s->set_framesize(s, FRAMESIZE_QVGA);
  }

#if defined(CAMERA_MODEL_M5STACK_WIDE) || defined(CAMERA_MODEL_M5STACK_ESP32CAM)
  s->set_vflip(s, 1);
  s->set_hmirror(s, 1);
#endif

#if defined(CAMERA_MODEL_ESP32S3_EYE)
  s->set_vflip(s, 1);
#endif

#if USAR_SERVIDOR_NATIVO && defined(LED_GPIO_NUM)
  setupLedFlash();
#endif

  WiFi.begin(ssid, password);
  WiFi.setSleep(false);

  Serial.print("WiFi connecting");
  while (WiFi.status() != WL_CONNECTED) {
    delay(500);
    Serial.print(".");
  }
  Serial.println("");
  Serial.println("WiFi connected");

#if USAR_SERVIDOR_NATIVO
  startCameraServer();
#endif

  Serial.print("Camera Ready! Use 'http://");
  Serial.print(WiFi.localIP());
  Serial.println("' to connect");
}

void enviarFrameFlask() {

  camera_fb_t *fb = esp_camera_fb_get();

  if (!fb) {
    Serial.println("Error capturando imagen");
    return;
  }

  HTTPClient http;
  http.begin(FLASK_URL_FRAME);
  http.addHeader("Content-Type", "image/jpeg");

  int codigo = http.POST(fb->buf, fb->len);

  if (codigo > 0) {
    Serial.printf("POST frame -> %d\n", codigo);
  } else {
    Serial.printf("Error HTTP frame: %s\n", http.errorToString(codigo).c_str());
  }

  http.end();
  esp_camera_fb_return(fb);
}

void enviarSensoresFlask(int turbidez, int conductividad) {

  if (WiFi.status() != WL_CONNECTED) return;

  HTTPClient http;
  http.begin(FLASK_URL_SENSORES);
  http.addHeader("Content-Type", "application/json");

  String json = "{\"turbidez\":" + String(turbidez) +
                ",\"conductividad\":" + String(conductividad) + "}";

  int codigo = http.POST(json);

  if (codigo > 0) {
    Serial.printf("POST sensores -> %d\n", codigo);
  } else {
    Serial.printf("Error HTTP sensores: %s\n", http.errorToString(codigo).c_str());
  }

  http.end();
}

void loop() {

  //=========================
  // Enviar imagen al servidor Flask
  //=========================
  if (millis() - ultimoFrame >= INTERVALO_FRAME) {
    ultimoFrame = millis();
    enviarFrameFlask();
  }

  //=========================
  // Tiempo del ciclo de LEDs
  //=========================
  unsigned long tiempo = millis() - inicioCiclo;

  if (tiempo < TIEMPO_LED) {
    digitalWrite(ledBlanco, HIGH);
    digitalWrite(ledUV, LOW);
  } else if (tiempo < (2 * TIEMPO_LED)) {
    digitalWrite(ledBlanco, LOW);
    digitalWrite(ledUV, HIGH);
  } else {
    inicioCiclo = millis();
  }

  //=========================
  // Lectura de sensores
  //=========================
  if (millis() - ultimaLectura >= INTERVALO_SENSOR) {
    ultimaLectura = millis();

    ultimoTurbidez = analogRead(turbidezPin);
    ultimaConductividad = analogRead(conductividadPin);

    Serial.printf("Turbidez: %d | Conductividad: %d\n", ultimoTurbidez, ultimaConductividad);

    lcd.setCursor(0, 0);
    lcd.print("Turb:");
    lcd.print(ultimoTurbidez);
    lcd.print("        ");

    lcd.setCursor(0, 1);
    lcd.print("Cond:");
    lcd.print(ultimaConductividad);
    lcd.print("        ");

    enviarSensoresFlask(ultimoTurbidez, ultimaConductividad);
  }
}

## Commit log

2026-03-17 Actualizacion de repositorio
    [WeatherStation_v2_Base_v2.stl, WeatherStation_v2_windmill_v4.stl]
2026-03-17 Actualizacion de Integrante 3
2026-03-17 Actualizacion de Integrante 5
2026-03-17 Actualizacion de Integrante 1
2026-03-17 Actualizacion de integrante 4
2026-03-17 Actualizacion de ODS
2026-03-20 Material de trabajo
2026-03-21 Actualización de Intereses en Integrante 1
2026-03-22 Actualización de pasatiempos Integrante 4
2026-03-22 Actualización de información de las ODS
2026-03-22 Actualización de información de la ODs
2026-03-22 Actualización de datos de la ODS
2026-03-22 Actualización en el markdown Integrantes del equipo
2026-03-22 cambiar los espacio de guiones
2026-03-22 Actualización de informacion integrante 3
2026-03-22 Actualizando intereses de diseñador
2026-03-22 cambio del marco de tabla de os integrantes del equipo
2026-03-22 actu de foto en Integrante 1
2026-03-23 hola amigos de radiovision
2026-03-23 modificando Integrantes de equipo
2026-03-23 descripción de ODS
2026-03-23 Actualización de imagen de integrante 4
2026-03-23 Actualización de datos e imágenes
2026-03-23 Actualización de foto grupal
2026-03-31 Actualizacion de referencias bibliograficas
2026-04-06 Adición de Referencias bibliográficas
2026-04-07 Actualizacion de datos
2026-04-08 Adicion de patentes
2026-04-08 Actualizacion de ruta
2026-04-08 Actualizacion de rutas
2026-04-11 Cambio de carpeta de patentes de Entregables a Taller
2026-04-13 propuesta de solu
2026-04-14 propuesta de solución
2026-04-14 Adicion de resumen final
2026-04-14 Actualización de la introducción
2026-04-14 Actualización de datos
2026-04-24 nuestro elevator pitch
    Updated project presentation and details for YAKU-ÑAWI, including problem statement, solution, and business model.
2026-04-24 nuestro elevator pitch yaku-ñawi
2026-04-28 subida de bocetos
2026-05-05 Adicion de presentacion avance
2026-05-05 cambio de ubicacion avance de proyecto
2026-05-19 add diagrama de flujo
2026-05-19 rename reto 1 diagrama de flujo
2026-05-19 Adicion modelado 3D capturas de pantalla
2026-05-19 uptade ( ˘▽˘)っ
2026-05-27 Adicion Modelado 3D
    [Soporte de electronica Yaku-Ñawi.stl, WeatherStation_v2_Base_v2.stl, WeatherStation_v2_windmill_v4.stl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]
2026-05-27 Adicion de Modelado 3D
    [WeatherStation_v2_Base_v2.stl, WeatherStation_v2_windmill_v4.stl]
2026-06-19 actu de repo
2026-06-19 Estructura de V1.0
2026-06-19 Estructura de V2.0
2026-06-19 Estructura de V3.0
2026-06-21 v1 schematic electronic
2026-06-22 text upload
    Added detailed description of the electronic schematic.
2026-06-22 electronic circuit schematic description
    Updated the description of the electronic circuit schematic to include the use of EasyEDA for design, simulation, and PCB fabrication.
2026-06-22 update image powerbank
2026-06-22 change image source for PowerBank
    Updated image source URL for PowerBank in Informe_Entregable3.md
2026-06-22 añadiendo +images
    Adjusted image width for better layout and added a new image of the XIAO ESP32-S3 Sense microcontroller.
2026-06-22 camera upload
2026-06-22 include LED images
    Added images and descriptions for UV-A and white LEDs in the report.
2026-06-22 update sensor information
2026-06-22 resolviendo merging
    [V1_Bisagra.stl, V1_CAJA.stl, V1_Cubierta cámara.stl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]
2026-06-22 Update Descripción de versiones y mejoras por versión.md
2026-06-23 add descripcion
    Added a detailed description and schematic of the patent project, including connections and power supply information.
2026-06-23 Update Descripción y aporte de artículos.md
2026-06-23 add descripción y aporte de normas
2026-06-23 add contribución de tesis
2026-06-23 markdown listo de productos comerciales
2026-06-23 Modificación informe de entregable 3
2026-06-30 yolo train
    [results.csv]
2026-06-30 Rename Metodología de investigación Se diseñó un sistema portátil que integra el módulo XIAO ESP32-S3 Sense, una cámara OV3660, iluminación UV-A y luz blanca para la adquisición de imágenes de muestr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
2026-06-30 Rename Detección de microplásticos Yaku-Ñawi.pdf to Presentación oral.pdf
